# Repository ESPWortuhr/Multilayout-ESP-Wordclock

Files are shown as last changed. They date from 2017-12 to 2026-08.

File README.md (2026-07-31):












[🇬🇧 English](README.en.md) | 🇩🇪 Deutsch

# ESP Wordclock

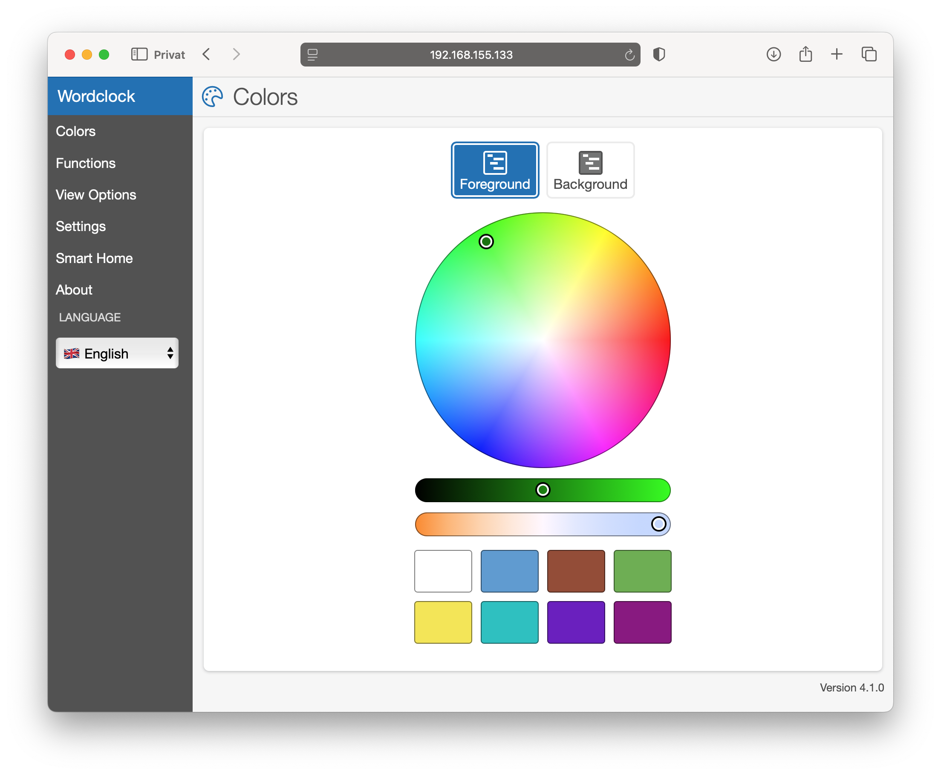
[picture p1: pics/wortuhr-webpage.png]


Dies ist ein Projekt für eine mehrsprachige Wortuhr auf Grundlage eines ESP8266-Mikrocontrollers und einer programmierbaren LED-Leiste (WS2812 oder SK6812). Eine Wortuhr ist ein wunderschönes DIY-Projekt für Anfänger, das Technologie und Design kombiniert, um eine funktionale und ästhetisch ansprechende Uhr zu schaffen. 
Egal, ob Sie ein Anfänger oder ein erfahrener Bastler sind, dieses Projekt ist eine großartige Möglichkeit, Ihre Fähigkeiten unter Beweis zu stellen und etwas wirklich Besonderes zu schaffen.
Die Software hat viele Funktionen:
- Mehrsprachig:
  - 🇬🇧 Englisch (English)
  - 🇩🇪 Deutsch
  - 🇪🇸 Spanisch (Español)
  - 🇮🇹 Italienisch (Italiano)
  - 🇳🇱 Niederländisch (Nederlands)
  - 🇭🇺 Ungarisch (Magyar)
  - 🇷🇴 Rumänisch (Română)
  - 🇨🇭 Schweizerdeutsch (Schwiizerdütsch)
  - 🇷🇺 Russisch (Русский)
  - 🇸🇪 Schwedisch (Svenska)
  - 🇫🇷 Französisch (Français)
  - 🇧🇩 Bengalisch (বাংলা)
- Unterstützung für mehrere Layouts und LED-Abstände
- Farbwechsel der Displayfarbe möglich (RGB oder RGBW)
- Digitale Uhranzeige
- Regenbogenfarbwechsel
- Umgebungslicht (als Sekundenzeiger ausgeführt) 
- Automatische Helligkeitsregelung (optional über LDR) 
- Auswahl an dialektspezifischen Anzeigen
- Home-Assistant-Einbindung mit Autodiscovery



## Inhaltsverzeichnis

- [Betriebsmodi der Uhr](#betriebsmodi-der-uhr)
- [Benötigte Hardware und Software](#benötigte-hardware-und-software)
- [Installation und Flashen der Firmware](#installation-und-flashen-der-firmware)
  - [Windows](#windows-über-grafische-oberfläche)
  - [MacOS](#macos)
  - [Linux](#linux)
  - [Fertige Firmware flashen (ohne Entwicklungsumgebung)](#fertige-firmware-flashen-ohne-entwicklungsumgebung)
  - [Nightly-Builds (aktueller Entwicklungsstand)](#nightly-builds-aktueller-entwicklungsstand)
  - [Nach der Installation: Der Erste Start](#nach-der-installation-der-erste-start)
- [Anschluss der Hardware](#anschluss-der-hardware)
- [Schematischer Aufbau einer Wordclock](#schematischer-aufbau-einer-wordclock)
- [Konfigurationsübersicht](#konfigurationsübersicht)
- [MQTT API Dokumentation](#mqtt-api-dokumentation)
- [Mitwirken](#mitwirken)
- [BSD-3 Lizenz](#bsd-3-lizenz)

## Betriebsmodi der Uhr

<p align="center">
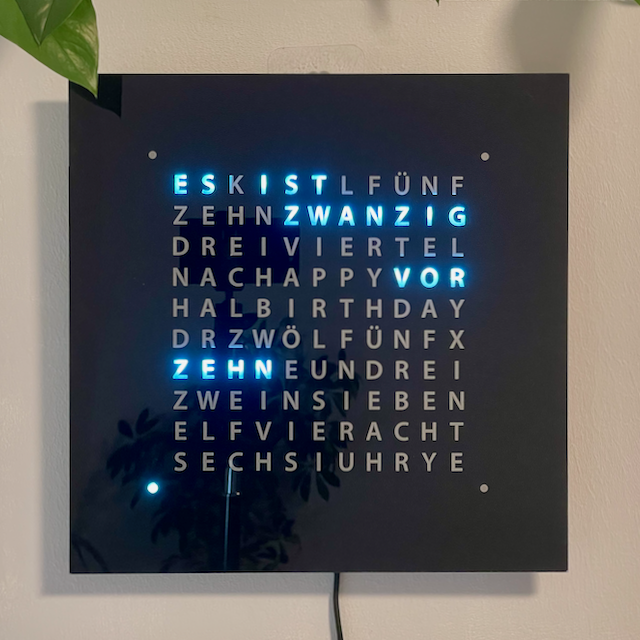
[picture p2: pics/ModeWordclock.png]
Wordclock
 DigitalClock
Colors Rainbow
Symbol Seconds
ScrollingText Animation
FrameSeconds 
</p>

## Benötigte Hardware und Software
* Hardware
    * NodeMCU oder vergleichbares Board mit einem dem ESP8266, ESP8285, ESP32 oder ESP32C3
    * WS2812B RGB-LED-Streifen oder SK6812 RGBW-Streifen
    * Stromversorgung 5V 2A
    * Optional: LDR, 10 KOhm-Widerstand

* Software
    * PlatformIO [Core](https://docs.platformio.org/en/latest/core/installation.html) oder [IDE](https://platformio.org/install/ide?install=vscode)
    * [Node.js](https://www.nodejs.org/)
    * [Git](https://git-scm.com)
 
---

## Installation und Flashen der Firmware

Bei vielen Entwickler-Boards (wie dem NodeMCU oder Wemos D1 Mini) benötigen Sie vorab den passenden USB-zu-Seriell-Treiber (meist **CH340** oder **CP210x**). Installieren Sie diesen, falls Ihr Computer das Board nach dem Einstecken nicht erkennt.

Es gibt zwei Wege zur fertigen Uhr:

* **Selbst kompilieren** (die folgenden Abschnitte Windows/MacOS/Linux). Nur so lässt sich die Uhr über `include/Config.h` an das eigene Layout, die eigene Sprache und die eigene Hardware anpassen. Für die meisten Nachbauten ist das der richtige Weg.
* **[Fertige Firmware flashen](#fertige-firmware-flashen-ohne-entwicklungsumgebung)** ohne Entwicklungsumgebung. Schneller, aber die Standard-Einstellungen sind fest einkompiliert.

### Windows (über grafische Oberfläche)

Der einfachste Weg für Windows-Nutzer führt über die grafische Oberfläche von Visual Studio Code (VS Code).

1. **Voraussetzungen installieren:**
   * Installieren Sie **PlatformIO IDE** (dies installiert automatisch Visual Studio Code), **Node.js** und **Git** manuell über die oben genannten Links.
   * Nach der Installation von VS Code finden Sie ein neues **PlatformIO-Symbol** (einen kleinen Ameisenkopf oder Alien) in der linken Seitenleiste.

2. **Projekt herunterladen (Klonen):**
   * Klicken Sie auf das PlatformIO-Symbol.
   * Gehen Sie im Menü auf `Quick Access` > `Miscellaneous` und wählen Sie `Clone Git Project`.
   * Geben Sie als URL `https://github.com/ESPWortuhr/Multilayout-ESP-Wordclock` ein und wählen Sie einen Speicherort auf Ihrer Festplatte aus.
   * Gehen Sie anschließend auf `Projects`, fügen Sie das soeben heruntergeladene Projekt über `Add Existing` hinzu und klicken Sie auf `Open`.

3. **Software kompilieren und hochladen:**
   * Schließen Sie nun Ihren ESP per USB-Kabel an den Computer an. *(Achtung: Verwenden Sie ein Datenkabel, kein reines Ladekabel!)*
   * In der PlatformIO-Seitenleiste finden Sie den Bereich `Project Tasks`. 
   * Klappen Sie Ihre Board-Umgebung auf und wählen Sie `General` > `Upload`.
   * **Geduld:** Beim ersten Mal dauert dieser Vorgang einige Minuten, da PlatformIO zunächst alle benötigten Bibliotheken im Hintergrund herunterlädt und die Software komplett neu kompiliert. 
   * Nach Abschluss erscheint eine grüne "SUCCESS"-Meldung.

### MacOS

Unter macOS können Sie ebenfalls den Weg über Visual Studio Code gehen (wie bei Windows beschrieben). Für Nutzer, die das Terminal bevorzugen, ist der Weg über den Paketmanager [Homebrew](https://docs.brew.sh/Installation) jedoch deutlich schneller:

1. Öffnen Sie das Terminal.
2. Führen Sie nacheinander die folgenden Befehle aus, um die Tools zu installieren, das Projekt herunterzuladen und auf den ESP zu flashen:

```sh
# PlatformIO und Node.js installieren
brew install platformio
brew install node

# Projektverzeichnis herunterladen
git clone https://github.com/ESPWortuhr/Multilayout-ESP-Wordclock.git
cd Multilayout-ESP-Wordclock

# ESP anschließen und flashen
pio run -t upload
```

### Linux

Auch unter Linux (z. B. Ubuntu, Debian, Raspberry Pi OS) lässt sich die Firmware bequem über das Terminal kompilieren und flashen.

Wichtiger Hinweis für Linux-Nutzer: Stellen Sie sicher, dass Ihr Benutzerkonto die Berechtigung hat, auf serielle Schnittstellen zuzugreifen (meist durch Hinzufügen des Benutzers zur Gruppe dialout via sudo usermod -a -G dialout $USER). Möglicherweise ist danach ein Neustart erforderlich.

```sh
# PlatformIO Installationsskript ausführen
python3 -c "$(curl -fsSL https://raw.githubusercontent.com/platformio/platformio/master/scripts/get-platformio.py)"

# Node.js Paketmanager installieren
sudo apt update
sudo apt install npm git

# Projekt herunterladen und ins Verzeichnis wechseln
git clone https://github.com/ESPWortuhr/Multilayout-ESP-Wordclock.git
cd Multilayout-ESP-Wordclock

# ESP anschließen und flashen
pio run -t upload
```

### Fertige Firmware flashen (ohne Entwicklungsumgebung)

Wer die Uhr nicht selbst kompilieren möchte, kann die fertigen Binärdateien von der [Releases-Seite](https://github.com/ESPWortuhr/Multilayout-ESP-Wordclock/releases) verwenden. Dort liegt pro Chip eine Datei, z. B. `ESP32_V4.4.0.bin`.

> **Wichtig:** Diese Dateien enthalten die Standard-Konfiguration aus `include/Config.h` (deutsches Layout `Ger10x11Alternative`, GRB-LEDs, kein I2C). Wer ein anderes Layout, eine andere Sprache oder eine RTC nutzt, muss selbst kompilieren.

**Weg 1 — Update über das Webinterface (empfohlen, kein Kabel nötig)**

Läuft auf der Uhr bereits eine Firmware, geht das Update über den eingebauten OTA-Updater:

1. Rufen Sie `http://<IP-der-Uhr>:81/update` im Browser auf (beachten Sie den **Port 81**).
2. Wählen Sie die heruntergeladene `.bin`-Datei aus und starten Sie den Upload.
3. Die Uhr startet nach dem Schreiben automatisch neu. Die WLAN- und Farbeinstellungen bleiben erhalten.

Ist in der Konfiguration `WEB_PROTECTED` auf `true` gesetzt, fragt der Updater vorher nach Benutzername und Passwort (`WEB_USER` / `WEB_PASSWORD`).

**Weg 2 — Serielles Flashen mit esptool**

Für ein fabrikneues Board oder eine Uhr, die nicht mehr startet. Voraussetzung ist Python mit `esptool` (`pip install esptool`):

```sh
# ESP8266 (NodeMCU, Wemos D1 Mini)
esptool.py --chip esp8266 --port /dev/ttyUSB0 write_flash 0x0 ESP8266_V4.4.0.bin

# ESP32 und ESP32-C3: die Datei enthält nur die Anwendung
esptool.py --chip esp32 --port /dev/ttyUSB0 write_flash 0x10000 ESP32_V4.4.0.bin
```

Unter Windows heißt der Port `COM3` o. ä., unter macOS `/dev/cu.usbserial-*`.

**Weg 3 — Browser-Flasher (ohne Installation)**

Wer weder PlatformIO noch Python installieren möchte, kann den ESP direkt aus dem Browser flashen. Diese Werkzeuge sprechen den Chip über die Web-Serial-Schnittstelle an:

| Werkzeug | Anmerkung |
| :--- | :--- |
| [esptool-js](https://espressif.github.io/esptool-js/) | Die offizielle Browser-Portierung von esptool durch Espressif. Datei und Offset werden von Hand eingetragen — es gelten dieselben Offsets wie oben. |
| [ESP Web Flasher (esp.huhn.me)](https://esp.huhn.me/) | Schlichtere Oberfläche, ebenfalls mit freier Offset-Angabe. |

Vorgehen: ESP per USB anschließen, im Werkzeug **Connect** wählen, den seriellen Port des Boards bestätigen, die `.bin`-Datei mit dem passenden Offset laden und den Schreibvorgang starten.

> **Voraussetzung:** Web Serial wird nur von Chromium-basierten Browsern unterstützt (Chrome, Edge, Opera) und nur über HTTPS. Firefox und Safari können das nicht. Der Browser braucht außerdem exklusiven Zugriff auf den Port — schließen Sie vorher alle seriellen Monitore.

> **Hinweis für ESP32/ESP32-C3:** Der Offset `0x10000` schreibt ausschließlich die Anwendung. Das setzt voraus, dass Bootloader und Partitionstabelle bereits auf dem Chip liegen — bei einem Board, auf dem schon einmal eine ESP32-Arduino-Firmware lief, ist das der Fall. Ein komplett leerer Chip braucht zusätzlich `bootloader.bin` (Offset `0x1000`, beim ESP32-C3 `0x0`) und `partitions.bin` (Offset `0x8000`). Diese beiden Dateien sind in den Releases nicht enthalten; verwenden Sie in dem Fall den Weg über `pio run -t upload`, der alles Nötige selbst schreibt.

### Nightly-Builds (aktueller Entwicklungsstand)

Für jeden Stand von `main` baut ein GitHub-Actions-Workflow automatisch die Firmware für alle drei Chips — nützlich, um einen Fehlerbericht oder eine gerade gemergte Funktion zu testen, ohne selbst zu kompilieren.

1. Öffnen Sie den Reiter [Actions → Nightly Firmware](https://github.com/ESPWortuhr/Multilayout-ESP-Wordclock/actions/workflows/nightly.yml).
2. Wählen Sie den obersten erfolgreichen Lauf aus.
3. Unter **Artifacts** liegen `firmware-ESP8266`, `firmware-ESP32` und `firmware-ESP32C3` zum Download.

Das Archiv enthält die `.bin` im Schema `<Chip>_V<Version>_<Commit>.bin`, eine `.sha256`-Prüfsumme sowie die `.elf`-Datei, mit der sich ein Absturz-Backtrace auflösen lässt. Geflasht wird genau wie oben beschrieben.

Zu beachten:

* Für den Download ist eine Anmeldung bei GitHub nötig (GitHub-Vorgabe für Artefakte).
* Die Artefakte werden nach **14 Tagen** automatisch gelöscht.
* Es sind **ungetestete Entwicklungsstände**, keine Releases. Wer eine stabile Uhr möchte, nimmt die Releases-Seite.

### Nach der Installation: Der Erste Start

Sobald der Upload auf den ESP erfolgreich war (Meldung `SUCCESS` im Terminal), startet die Uhr neu.

1. Die Wortuhr spannt nun ein eigenes WLAN-Netzwerk (Access Point) auf.
2. Suchen Sie mit Ihrem Smartphone oder Laptop nach einem neuen WLAN (meist "Wortuhr" oder ähnlich) und verbinden Sie sich damit.
3. Es sollte sich automatisch ein Anmeldefenster öffnen (Captive Portal). Falls nicht, öffnen Sie Ihren Browser und rufen Sie die Adresse `http://192.168.4.1` auf.
4. Tragen Sie dort Ihre heimischen WLAN-Zugangsdaten ein. Die Uhr startet neu, verbindet sich mit Ihrem Heimnetzwerk und ist fortan über ihre eigene IP-Adresse im Netzwerk erreichbar.

---

## Anschluss der Hardware
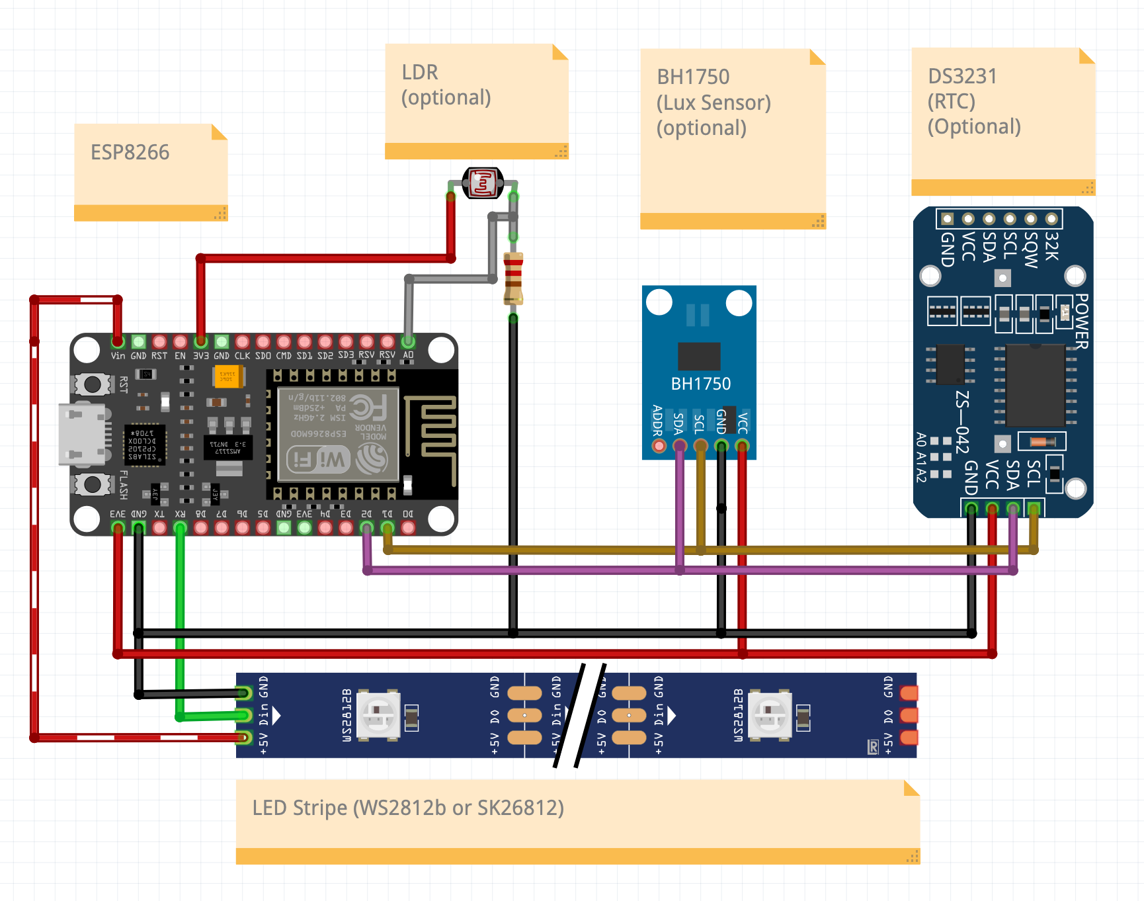
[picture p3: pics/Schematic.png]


## Schematischer Aufbau einer Wordclock

Dieser Leitfaden beschreibt den typischen Schichtaufbau und die elektronische Konfiguration einer DIY-Wortuhr. Die Spezifikationen richten sich nach dem klassischen 11x10 Buchstaben-Raster plus 4 separaten Minuten-LEDs.

### 1. Die mechanischen Schichten (Von vorne nach hinten)

* **Frontplatte:** Die sichtbare Schicht mit den ausgestanzten oder ausgelaserten Buchstaben (oft aus Edelstahl, beschichtetem Acryl oder Holzfurnier).
* **Diffusor-Schicht:** Eine milchige Folie oder ein Bogen Architektenpapier direkt hinter der Frontplatte. Sie streut das Licht der LEDs weich und gleichmäßig aus.
* **Lichtgitter (Baffle):** Ein Rasterkreuz (meist aus Holz, MDF oder 3D-Druck), das jede LED räumlich von den anderen trennt. Es verhindert streng das seitliche Überstrahlen des Lichts auf benachbarte, nicht aktive Buchstaben.
* **Trägerplatte (Rückwand):** Eine stabile Platte, auf der die LED-Streifen passgenau zum Lichtgitter waagerecht aufgeklebt werden.

### 2. Spezifikationen der LED-Matrix (WS2812B / Neopixel)

Um das Raster der Buchstaben matrixgetreu auszufüllen, müssen die Abstände der LEDs (LEDs pro Meter) exakt zur Größe der Uhr passen. Basierend auf den gängigen Gehäusegrößen ergeben sich folgende Anforderungen:

| Gehäusegröße (Front) | Matrix-Größe | Empfohlener LED-Stripe | Besonderheit bei der Verkabelung |
| :--- | :--- | :--- | :--- |
| **30 x 30 cm** | 25 x 25 cm | 60 LEDs/m | Standardmaß. Perfekter Abstand der LEDs für jedes Rasterfeld. |
| **40 x 40 cm** | 35 x 35 cm | 74 LEDs/m | Jede zweite LED einer Reihe bleibt ungenutzt (Software- oder Hardwareseitig übersprungen). |
| **50 x 50 cm** | 50 x 50 cm | 30 LEDs/m | Der natürliche Abstand der LEDs passt direkt zum größeren Raster. |

> **Hinweis zur Verklebung:** Die LED-Streifen werden typischerweise schlangenförmig (Zick-Zack-Verkabelung) auf die Trägerplatte geklebt. Der Daten-Ausgang (DOUT) einer Zeile wird dabei mit dem Daten-Eingang (DIN) der direkt darunterliegenden Zeile auf der gleichen Seite verbunden.

### 3. Elektronik und Komponenten

Den zugehörigen Schaltplan findest du oben unter [Anschluss der Hardware](#anschluss-der-hardware).

* **Mikrocontroller:** Ein ESP8266 (z.B. Wemos D1 Mini) oder ESP32. Dieser steuert die LEDs und synchronisiert die Uhrzeit meist automatisch über das heimische WLAN (NTP-Server).
* **Stromversorgung:** Ein starkes 5V-Netzteil. Wenn viele Buchstaben in der Farbe Weiß leuchten, kann die Matrix mehrere Ampere Strom ziehen. Ein 5V / 3A bis 5A Netzteil wird empfohlen.
* **Echtzeituhr (RTC):** Ein Modul wie das DS3231 (optional, aber empfohlen). Es sorgt durch eine Knopfzelle dafür, dass die Uhrzeit bei Stromausfall oder fehlendem WLAN exakt weiterläuft.
* **Level-Shifter:** Da der ESP mit 3.3V arbeitet, die LEDs aber 5V Datenpegel erwarten, sichert ein Level-Shifter (z.B. 74AHCT125) eine saubere Signalübertragung (oft reicht aber auch ein direkter Anschluss über einen 470 Ohm Widerstand).

### 4. Basis-Schaltplan

* **Netzteil 5V (+):** Verbinden mit dem 5V-Pin des Mikrocontrollers UND dem 5V-Eingang des LED-Streifens.
* **Netzteil GND (-):** Verbinden mit dem GND-Pin des Mikrocontrollers UND dem GND-Eingang des LED-Streifens.
* **Mikrocontroller Data-Pin:** Verbinden mit dem DIN (Data In) des allerersten LED-Streifens in der Matrix.

---

## Konfigurationsübersicht

Die folgenden Einstellungen stammen aus der Datei `include/Config.h`.
Viele dieser Einstellungen können später auch bequem über das Webinterface der Uhr angepasst werden.

### Hardware & Pins (ESP32)
Legt fest, an welchen Pins die Hardware angeschlossen ist (Hinweis: Der ESP8266 wird für diese spezifischen Pins hier aktuell nicht unterstützt).
* **`LED_PIN`**: Pin für den LED-Datenkanal. *(Standard: 3, bei dem ESP8266 ist das der RX Pin)*
* **`SDA_PIN_ESP32` / `SCL_PIN_ESP32`**: Pins für die I2C-Kommunikation (z.B. für RTC oder Lichtsensor). *(Standard: beide `255`, d.h. der I2C-Bus ist deaktiviert)*
  * Diese Pins müssen nicht im Quelltext gesetzt werden: Im Webinterface unter **Einstellungen → Hardware-Pins** lassen sich SDA und SCL direkt eintragen und speichern. Der Wert `255` steht dort ebenfalls für „deaktiviert".
  * Über die Schaltfläche **I2C-Adressen suchen** startet ein Scan des Busses (Adressen 1-126). Das Ergebnisfeld listet alle gefundenen Adressen auf — praktisch, um zu prüfen, ob eine RTC (DS3231 üblicherweise `0x68`) oder ein BH1750-Lichtsensor (`0x23` oder `0x5C`) korrekt angeschlossen ist. Meldet der Scan „Keine I2C-Adressen gefunden", stimmt in der Regel die Verkabelung oder die Pin-Zuordnung nicht.
* **`RTC_Type`**: Verwendetes Echtzeituhr-Modul (RTC), damit die Uhr auch ohne WLAN weiterläuft. *(Standard: `RTC_DS3231`)*

### Sprache & Front-Layout
Definiert, in welcher Sprache und mit welchem Raster die Wortuhr aufgebaut ist. Es ist eine Vielzahl an Sprachen hinterlegt (Deutsch, Englisch, Niederländisch, Spanisch, etc.).
* **`DEFAULT_LAYOUT`**: *(Aktiver Standard: `Ger10x11Alternative`)* * 10 Zeilen, 11 LEDs pro Zeile + 4 Minuten-LEDs.
  * Dies ist das alternative deutsche Layout von Github-User @dbambus mit zusätzlichen Wörtern.

### LED & Darstellung
Spezifiziert den Typ der verwendeten LEDs und die Standard-Farbwerte beim Start.
* **`DEFAULT_LEDTYPE`**: Die Farbreihenfolge des LED-Streifens.
* **`WHITE_LEDTYPE`**: Farbtemperatur, falls RGBW-LEDs genutzt werden. *(Standard: `NeutralWhite`)*
* **`DEFAULT_HUE`**: Standard-Farbton beim Start (0-360). *(Standard: `120` - entspricht Grün)*
* **`DEFAULT_BRIGHTNESS`**: Starthelligkeit in Prozent.
* **`DEFAULT_BUILDTYPE`**: Bauart der Matrix. *(Standard: `Normal` - jede LED auf dem Streifen wird genutzt)*
* **`MINUTE_...`**: Art der Minutenanzeige. *(Standard: `MINUTE_LED4x` - 4 separate LEDs für die Minuten)*

### Helligkeitsregelung
Einstellungen für die automatische Helligkeitsanpassung über externe Sensoren.
* **`AUTOBRIGHT_USE_BH1750`**: Nutzung eines digitalen Lichtsensors.
* **`AUTOBRIGHT_USE_LDR`**: Nutzung eines analogen Fotowiderstands.
  * *Hinweis: Da beide auf `false` stehen, ist die automatische Helligkeitsregelung aktuell deaktiviert.*
* **LDR-Widerstandswerte**: Falls ein LDR genutzt wird, sind hier die Kalibrierungswerte für den Spannungsteiler hinterlegt (`RESBRIGHT 15`, `RESDARK 1000`, `RESDIVIDER 10`).

### WLAN & Captive Portal
Konfiguration der Netzwerkanbindung.
* **`MANUAL_WIFI_SETTINGS`**: Legt fest, ob die WLAN-Daten fest im Code hinterlegt sind.
* **`WIFI_SSID`**: Name deines WLANs.
* **`WIFI_PASSWORD`**: Dein WLAN-Passwort.
* **`CP_PROTECTED` / `CP_SSID` / `CP_PASSWORD`**: Einstellungen für das Captive Portal (das eigene WLAN-Netzwerk der Uhr für die Ersteinrichtung). *(Standard: Unverschlüsselt, SSID: `"Connect_to_Wordclock"`)*

### System & Boot-Verhalten
Einstellungen für den Startvorgang und das Debugging.

### Matrix- & Verdrahtungseinstellungen
Hier wird definiert, wie die LEDs physisch in der Uhr verklebt und verdrahtet wurden (z.B. wo der Streifen beginnt und ob er im Zick-Zack verlegt wurde).
* **`REVERSE_MINUTE_DIR`**: Dreht die Laufrichtung der Minuten-LEDs um.
* **`MIRROR_FRONT_VERTICAL` / `HORIZONTAL`**: Spiegelt die Anzeige vertikal oder horizontal.
* **`EXTRA_LED_PER_ROW`**: Falls zusätzliche (blinde) LEDs pro Zeile verbaut sind.
* **`FLIP_HORIZONTAL_VERTICAL`**: Tauscht X- und Y-Achse (nützlich bei falscher Ausrichtung).
* **`MEANDER_ROWS`**: Gibt an, ob der LED-Streifen schlangenförmig (Zick-Zack) verklebt wurde.
---

## MQTT API Dokumentation

Die Uhr verwendet das **JSON Light Schema** von Home Assistant. Das bedeutet, dass Befehle und Statusmeldungen im JSON-Format über MQTT ausgetauscht werden.

### 1. MQTT Topics (Themen)
Die Uhr verwendet ein Basis-Topic, welches in den Einstellungen der Uhr (Webinterface) definiert wird. In dieser Dokumentation wird es als `<TOPIC>` bezeichnet (z.B. `ESPWordclock`).

| Funktion | Topic | Beschreibung |
| :--- | :--- | :--- |
| **Befehle senden** | `<TOPIC>/cmd` | An dieses Topic sendest du JSON-Befehle, um die Uhr zu steuern. |
| **Status empfangen** | `<TOPIC>/status` | Auf diesem Topic veröffentlicht die Uhr nach jeder Änderung ihren aktuellen Status. |
| **Verfügbarkeit** | `<TOPIC>/availability` | Zeigt an, ob die Uhr online ist (`online` oder `offline` via Last Will). |

---

### 2. Befehle Senden (Command Payload)
Befehle werden als JSON-String an das Topic `<TOPIC>/cmd` gesendet. Du kannst mehrere Parameter in einer einzigen Nachricht kombinieren.

#### Unterstützte JSON-Parameter:

* **`state`** (String)
  Schaltet die LEDs der Uhr ein oder aus.
  * Werte: `"ON"` oder `"OFF"` *(Muss zwingend großgeschrieben werden!)*
* **`brightness`** (Integer)
  Steuert die Helligkeit der LEDs.
  * Werte: `0` bis `255`
* **`color`** (Object)
  Setzt die Vordergrundfarbe der Uhr im HSB-Farbraum (Hue, Saturation).
  * `h` (Hue/Farbton): `0` bis `360` (Grad)
  * `s` (Saturation/Sättigung): `0` bis `100` (%)
* **`effect`** (String)
  Wechselt den Anzeigemodus / das Programm der Uhr.
  * Werte: 
    * `"Wordclock"` (Normale Wortuhr)
    * `"Seconds"` (Sekundenanzeige)
    * `"Digitalclock"` (Digitale Uhrzeit)
    * `"Scrollingtext"` (Lauftext)
    * `"Rainbowcycle"` (Regenbogen-Zyklus)
    * `"Rainbow"` (Regenbogen statisch)
    * `"Color"` (Einfarbig)
    * `"Symbol"` (Symbolanzeige, z.B. Herz)
* **`scrolling_text`** (String)
  Legt den Text fest, der im Effekt `"Scrollingtext"` angezeigt wird.
  * Werte: Beliebiger Text (max. Länge abhängig von den C++ Speichereinstellungen).

---

### 3. Beispiele für MQTT-Befehle

**Uhr einschalten, auf 100% Helligkeit setzen und Farbe auf Rot ändern:**
```json
{
  "state": "ON",
  "brightness": 255,
  "color": {
    "h": 0,
    "s": 100
  }
}
```

**Modus auf "Lauftext" ändern und Text vorgeben:**
```json
{
  "effect": "Scrollingtext",
  "scrolling_text": "Hallo Welt!"
}
```

**Uhr ausschalten:**
```json
{
  "state": "OFF"
}
```

---

### 4. Status Empfangen (Status Payload)

Sobald die Uhr einen Befehl verarbeitet hat (oder sich intern etwas ändert), sendet sie ihren Zustand an <TOPIC>/status. Dies ist besonders wichtig, damit Smart Home Systeme (wie Home Assistant) den aktuellen Zustand kennen.

**Beispielhafter Status-Rückgabewert:**

```json
{
  "state": "ON",
  "color": {
    "h": 120,
    "s": 100
  },
  "brightness": 128,
  "color_mode": "hs",
  "effect": "Wordclock"
}
```

(Hinweis: color_mode: "hs" wird von Home Assistant benötigt, um zu wissen, dass die Farbe im Hue/Saturation-Format vorliegt).

---

### 5. Home Assistant Auto-Discovery
Diese Uhr unterstützt MQTT Auto-Discovery für Home Assistant.
Wenn die Uhr startet oder der Button "MQTT Discovery" im Webinterface gedrückt wird, sendet sie automatisch ihre komplette Konfiguration an das Topic:

`homeassistant/light/<TOPIC>/light/config`

Dadurch taucht die Wortuhr in Home Assistant vollautomatisch als Licht-Entität auf. Du hast dort sofort Zugriff auf:

- Ein/Aus Schalter
- Helligkeits-Schieberegler
- Farbwähler (Farbrad)
- Ein Dropdown-Menü für alle Effekte (Wordclock, Rainbow, etc.)

## Mitwirken

Pull Requests sind willkommen — sei es eine neue Sprache, ein neues Frontlayout oder eine Fehlerkorrektur.

**Code-Formatierung.** Das Projekt nutzt `clang-format` mit der Konfiguration in [.clang-format](.clang-format). Ein Pull Request, dessen Formatierung davon abweicht, wird von der CI abgelehnt. Formatieren Sie deshalb vor dem Commit:

```sh
clang-format -i $(git ls-files '*.h' '*.hpp' '*.cpp' '*.ino')
```

Die CI prüft mit **clang-format 11**. Neuere Versionen formatieren an einzelnen Stellen abweichend — im Zweifel entscheidet das Ergebnis der CI.

**Automatische Prüfungen.** Jeder Push und jeder Pull Request durchläuft drei Workflows:

| Workflow | Prüft |
| :--- | :--- |
| [PlatformIO CI](.github/workflows/platformio.yml) | Kompiliert für ESP8266, ESP32 und ESP32-C3 |
| [Run clang-format Linter](.github/workflows/clang-format.yml) | Einhaltung der Code-Formatierung |
| [Nightly Firmware](.github/workflows/nightly.yml) | Täglicher Build inklusive Firmware-Artefakten |

Alle drei müssen grün sein, bevor ein PR gemergt werden kann.

**Vor dem Öffnen eines Pull Requests** empfiehlt sich ein lokaler Build aller drei Umgebungen — das ist derselbe Befehl, den die CI ausführt:

```sh
pio run
```

**Neue Frontlayouts** brauchen zwei Schritte:

1. Die Layout-Datei als eigene `.hpp` nach `include/WordClockTypes/` legen. Der Build bindet alle Dateien dieses Verzeichnisses automatisch über `include/ClockType.gen.h` ein; dort ist nichts von Hand zu ergänzen. Am Ende der Datei steht die Instanz des Layouts, z. B. `De10x11Alternative_t _de10x11Alternative;`.
2. Das Layout in der Liste `CLOCK_TYPES_LIST` in [include/WordClockState.h](include/WordClockState.h) registrieren. Ohne diesen Eintrag ist das Layout weder auswählbar noch im Webinterface sichtbar:

```c
X(Ger10x11Alternative, 12, _de10x11Alternative, "de-10-11-alt")
```

Die vier Parameter sind der Name der Aufzählung, eine **eindeutige ID**, der Name der Instanz aus Schritt 1 und der i18n-Schlüssel für die Anzeige. Die ID dient als Querverweis für HTML und JavaScript und darf nicht doppelt vergeben werden — verwenden Sie die nächste freie Nummer am Ende der Liste. Die Liste ist nach Sprachkürzeln gruppiert; ordnen Sie den neuen Eintrag passend ein.

Die Auswahlliste im Webinterface wird aus dieser Liste **automatisch erzeugt** (Grunt-Schritt `replace:frontlayout`); in `webpage/index.html` ist nichts zu ergänzen. Was noch von Hand dazukommt, ist der Anzeigename unter dem i18n-Schlüssel in den Sprachdateien `webpage/language/*.js` (dort im Abschnitt `view.front`).

Optional kann das Layout zusätzlich als auskommentierte `DEFAULT_LAYOUT`-Zeile in `include/Config.h` aufgeführt werden, damit es dort zur Auswahl steht.

## BSD-3 Lizenz

Diese Software ist unter der BSD-Lizenz lizenziert und darf frei verwendet werden. Es ist erlaubt, sie zu kopieren, zu verändern und zu verbreiten.
Die einzige Bedingung ist, dass der Copyright-Hinweis des Originalprogramms nicht entfernt werden darf.

Der vollständige Lizenztext steht in der Datei [LICENSE](LICENSE).

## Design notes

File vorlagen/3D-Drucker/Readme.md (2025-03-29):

# TBD: Druckdateien werde ich auf Printables hochladen
[Printables](https://www.printables.com/@Sebas)

# Druckdatei erstellen
Die Beschreibungen beziehen sich alle auf den PrusaSlicer, können aber mit Sicherheit auch auf andere Slicer übertragen werden.

## Einfache Version
Um den Diffusor direkt ins Gehäuse zu drucken kann entweder die Datei "Wortuhr_8x8_CaseWithoutLayerChange.3mf" direkt gesliced werden und in Höhe des Diffusors ein Filamentwechsel eingefügt. So hat man jedoch einen weißen Streifen aus am Gehäuse.

## Schwierigere Version
In der Datei "Wortuhr_8x8_Case_DE15min_Prusa.3mf" ist in Höhe des Diffusors ein Schlitz im Gehäuse, sodass der Diffusor in der Luft hängt. Dies kann so gesliced werden und im Anschluss mit dem Python-Script "ChangeLayerHeightAfterFilamentChange.py" nach unten gesetzt werden. Somit wird der Diffusor in das Gehäuse eingedruckt (siehe "Wortuhr_8x8_Case_DE15min_Prusa_0.2mm_PLA,PLA_MK3_2h24m.gcode"). Es soll wohl auch möglich sein, direkt im Slicer durch das definieren eines zweiten Extruders den Diffusor in das Gehäuse zu drucken, allerdings habe ich das bisher noch nicht getestet.

## Druckeinstellungen
- Höhenmodifizierer im Bereich des Diffusors zu 0.1mm (Zwei Schichten sind notwendig, damit homogen)
- Druckeinstellungen -> Erweitert -> Infill/Perimeter Überlappung: 35% (Sonst bleiben Lücken zwischen Buchstaben und Infill)
- PLA mit möglichst niedriger Temperatur (205-210°C) um Fäden zwischen den Buchstaben zu verhindern.

# FreeCAD
Zum erstellen habe ich die Version FreeCAD 1.0 RC1 (https://github.com/FreeCAD/FreeCAD/releases/tag/1.0rc1) verwendet. Das Modell ist über die Variablen in VarSet parametrierbar. Es wird empfohlen, nur manuell zu aktualisieren (Klick Rechte Maustaste auf Wortuhr_8x8_Vorlage -> Neuberechnungen überspringen). Die Vorlage ist für eine maximale Größe von 16x16 LEDs ausgelegt.

Folgende Parameter sind anpassbar:
- Anzahl der LEDs in X und Y Richtung
- Abstand der LEDs in X und Y Richtung
- Höhe und Breite der Platine der LED Matrix
- Buchstaben auf der Wortuhr
- Schriftart & -größe
- Wandstärke
- Spielraum

Falls ihr Fragen oder eigene Idee zu Layout's oder Änderungen habt könnt ihr euch gerne bei mir melden.

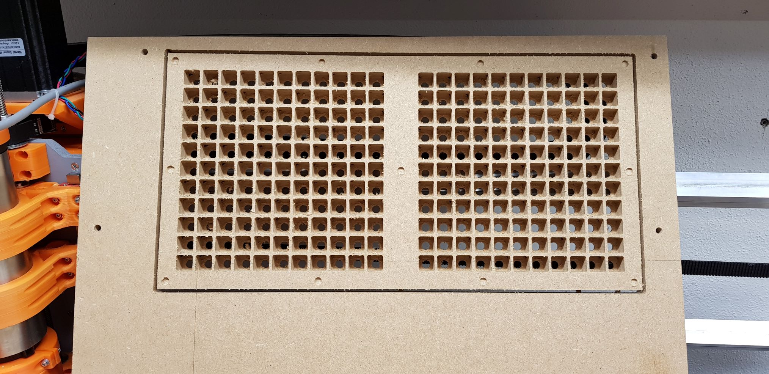
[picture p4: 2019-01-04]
pics/CNC_Machined/uhr_242-front.jpg

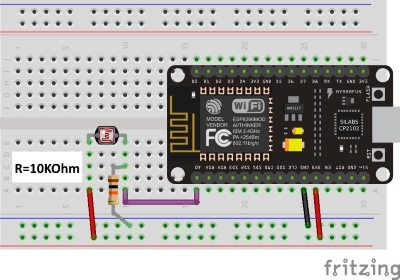
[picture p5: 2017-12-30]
pics/LDR.jpg

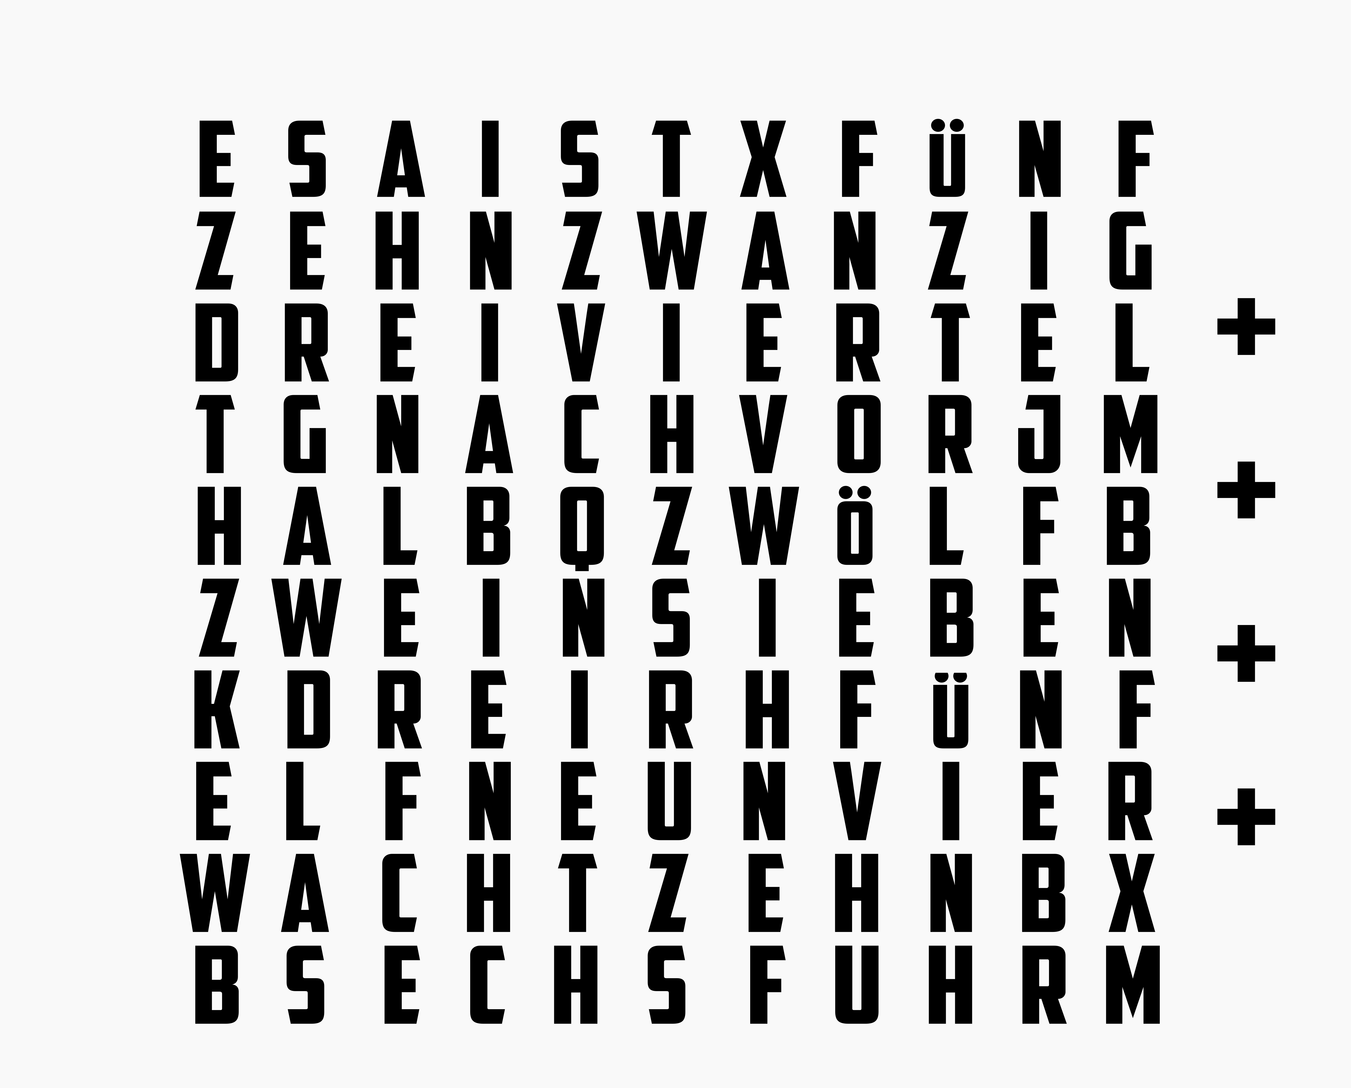
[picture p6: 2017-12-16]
pics/40x50_Text.png

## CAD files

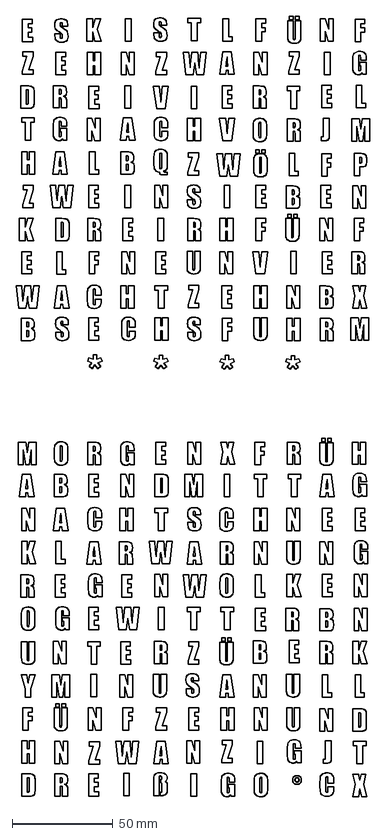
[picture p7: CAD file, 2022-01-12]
vorlagen/Router/Uhr242/Uhr242_Front.dxf
175.7 x 387.6 mm

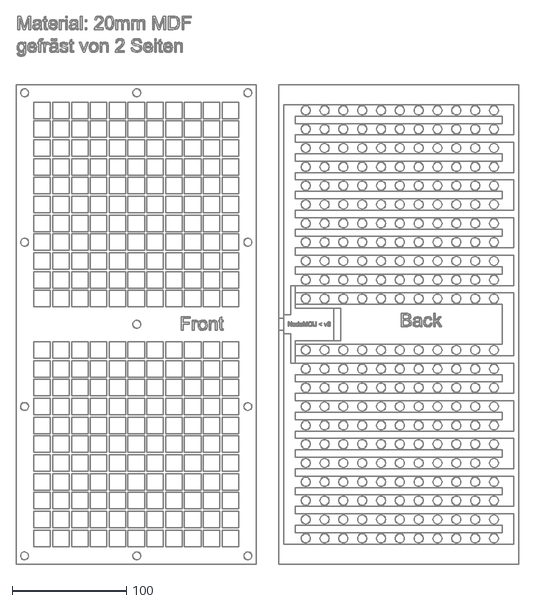
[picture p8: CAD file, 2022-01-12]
vorlagen/Router/Uhr242/Uhr242_Matrix.dxf
440.0 x 480.2

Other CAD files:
vorlagen/Laser/Uhr114/WordClockUhr114LaserFinalV2.dxf
vorlagen/Laser/Uhr242/WordClockUhr242LaserFinalV2.dxf
3D_Model/Wordclock.f3d

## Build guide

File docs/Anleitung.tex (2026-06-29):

\documentclass[12pt,a4paper, german,oneside, headinclude, headsepline,plainheadsepline,BCOR20mm, DIV18,parskip=half, openright, numbers=noenddot, captions=tableheading,version=first,listof=totoc,version=first]{scrbook}

\hfuzz=20pt
\vfuzz=20pt

%--------------- Packages ----------------
\usepackage[ngerman]{babel}
\usepackage[utf8]{inputenc}
\usepackage[T1]{fontenc}
\usepackage{lmodern}
\usepackage[centertags]{amsmath} 
\usepackage{tabularx}
\usepackage{graphicx} 
\usepackage{float} 
\usepackage{setspace} 
\usepackage{scrlayer-scrpage}
\usepackage{scrhack}
\usepackage{makeidx}
\usepackage[usenames,dvipsnames,svgnames,table]{xcolor}
\usepackage[absolute]{textpos}
\usepackage{subfigure}
\usepackage{amssymb}
\usepackage{listings}
\usepackage{trfsigns}
\usepackage{siunitx}
\usepackage[abs]{overpic}
\usepackage[colorlinks = false,pdfpagelabels = true,pdfstartview = FitH,bookmarksopen = true,bookmarksnumbered = true,linkcolor = black,plainpages = false,hypertexnames = false,citecolor = black] {hyperref}
\usepackage{pgfplots}
\usepackage[framed,numbered,autolinebreaks,useliterate]{mcode}
\usepackage{xcolor}
\usepackage[
    left = \flqq{},% 
    right = \frqq{},% 
    leftsub = \flq{},% 
    rightsub = \frq{} %
]{dirtytalk}
\lstset{breaklines=true}

\pagestyle{scrheadings}
\renewcommand{\headfont}{\normalfont\sffamily} 
\renewcommand{\pnumfont}{\normalfont\sffamily} 
\ohead[\pagemark]{\pagemark} 
\ifoot[]{}
\ofoot[]{}
\setlength{\headheight}{1.5\baselineskip}
\onehalfspacing

%----------------------- Beginn des Dokuments -----------------------
\begin{document}
\pagenumbering{Roman}
\thispagestyle{empty}
\setcounter{page}{-1}



\vspace{25mm}

{\centering

\LARGE\textbf{{Anleitung}}\\
\vspace{1em}
\large{Für die Multilayout-ESP-Wordclock} \\

\par}

\newpage
\thispagestyle{empty}

\cleardoublepage

\cleardoublestandardpage

\begin{spacing}{1.15}		
\pdfbookmark[1]{Inhaltsverzeichnis}{toc}		
\tableofcontents 		

\end{spacing}

\cleardoublestandardpage

\mainmatter							

\chapter{Einleitung}

Diese Anleitung soll helfen, eine mehrsprachige Wortuhr zu bauen, die auf einem ESP8266-, ESP8285-, ESP32- oder ESP32-C3-Mikrocontroller und einer programmierbaren LED-Leiste (WS2812 oder SK6812) basiert. Dieses Projekt wurde über mehrere Jahre von einer Vielzahl von Mitwirkenden auf GitHub entwickelt und frei zur Verfügung gestellt.\\
Eine Wortuhr (auch als Wordclock bekannt) ist ein schönes DIY-Projekt für Anfänger, das Technologie und Design kombiniert, um eine funktionale und ästhetisch ansprechende Uhr zu schaffen. Egal, ob Sie Anfänger oder erfahrener Bastler sind, dieses Projekt ist eine großartige Gelegenheit, Ihre Fähigkeiten unter Beweis zu stellen und etwas wirklich Besonderes zu schaffen. Die Gestaltungsmöglichkeiten liegen vor allem im Rahmen und in der Wahl der Oberfläche der Uhr.

\section{Hauptfunktionen}

Die bereitgestellte Software zum Betreiben der Wortuhr hat mehrere Funktionen:

\begin{itemize}
    \item Mehrsprachig (Deutsch, Englisch, Niederländisch, Italienisch, Spanisch, Ungarisch, Französisch, Rumänisch, Schweizer Deutsch, Russisch und Schwedisch)
    \item Unterstützung für mehrere Matrizengrößen und LED-Abstände
    \item Farbwechsel der Anzeigefarbe möglich (RGB oder RGBW)
    \item Digitale Uhranzeige
    \item Laufschrift, kurzer statischer Text und Symbol-Anzeige
    \item Regenbogenfarbwechsel
    \item Einstellbare Übergangsanimationen zwischen Anzeigewechseln
    \item Geburtstags- und Silvester-Animationen
    \item Umgebungslicht (als Sekundenzeiger ausgeführt oder Ambientlight)
    \item Minuten- und Sekundenanzeige im Rahmen oder in Worten
    \item Automatische Helligkeitsregelung (optional über Sensor)
    \item Offlinebetrieb (optional über entsprechende RTC)
    \item Zeitserver, Zeitzone und manuelle Uhrzeit im Web-Frontend einstellbar
    \item Konfigurierbare Hardware- und I2C-Pins
    \item Konfigurierbares Startverhalten
    \item Auswahl an dialektspezifischen Anzeigen
    \item MQTT- und Home-Assistant-Einbindung mit Autodiscovery
    \item Wetterdaten über OpenWeatherMap bei passenden Frontplatten
    \item Optionaler Passwortschutz für das Web-Frontend
\end{itemize}

\section{Uhrenvarianten}

Die Firmware unterstützt verschiedene Frontplatten und Matrixgrößen. Die passende Variante wird später im Web-Frontend unter \say{Anzeigeoptionen} im Bereich \say{Front} ausgewählt. Wichtig ist, dass die eingestellte Matrix zur tatsächlich gebauten Buchstabenmaske und zur Anordnung der LEDs passt.

\begin{itemize}
    \item Klassische deutsche Layouts mit 10 \(\times\) 11, 11 \(\times\) 11, 13 \(\times\) 13, 16 \(\times\) 8 oder 16 \(\times\) 18 LEDs
    \item Kompakte Varianten mit 8 \(\times\) 8 LEDs, teilweise für Viertelstunden-Anzeige
    \item Internationale Layouts, unter anderem Englisch, Niederländisch, Spanisch, Italienisch, Ungarisch, Französisch, Rumänisch, Schweizer Deutsch, Russisch, Schwedisch und Bengalisch
    \item Dialekt- und Sondervarianten wie Bayerisch, Schwäbisch, Nero, mrrioes oder Wetter-Layout
    \item Bauarten mit einer LED pro Buchstabe, jeder zweiten LED pro Buchstabe oder zwei, drei bzw. vier LEDs pro Buchstabe
\end{itemize}

Zusätzlich können im Web-Frontend die Minutenzählrichtung, horizontale oder vertikale Spiegelung, gedrehte Layouts, zusätzliche LEDs pro Reihe, mäanderförmig verlegte LED-Streifen und die Bauart der LED-Matrix eingestellt werden. Diese Optionen sind hilfreich, wenn die LED-Streifen anders herum eingebaut wurden, die Frontplatte gespiegelt gefertigt ist oder mehrere physische LEDs einen Buchstaben ausleuchten. Änderungen an Matrixgröße und Bauart werden im EEPROM gespeichert und erst nach einem Neustart der Uhr vollständig übernommen.

    \begin{figure} [H]
        \centering
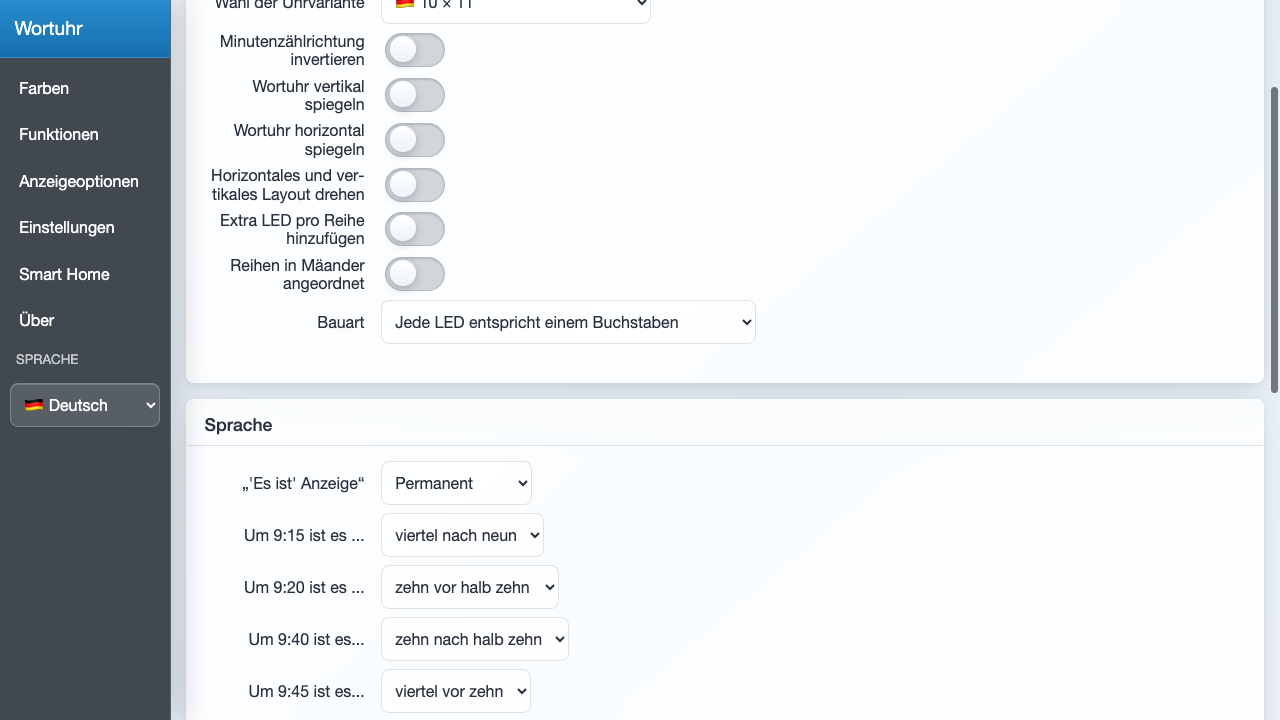
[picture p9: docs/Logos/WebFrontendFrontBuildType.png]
        
        \caption{Front- und Bauart-Konfiguration im Web-Frontend}
        \label{abb.WebFrontendFrontBuildType}
    \end{figure}

\section{Voraussetzungen}

Die folgende Hardware/Software wird für dieses Projekt benötigt:

\subsubsection{Hardware}

\begin{itemize}
    \item NodeMCU oder vergleichbares Board mit ESP8266-, ESP8285-, ESP32- oder ESP32-C3-Chip
    \item WS2812B RGB-LED-Streifen oder SK6812 RGBW-Streifen
    \item Stromversorgung 5 V / 2 A
    \item Optional: LDR, 10 KOhm-Widerstand
    \item Optional: BH1750 (digitaler Helligkeitssensor, anstatt LDR)
    \item Optional: DS3231 (Echtzeituhr, für den Offline-Betrieb)
\end{itemize}

\subsubsection{Software}

\begin{itemize}
    \item PlatformIO Core oder IDE (bspw. Visual Studio Code)
    \item Node.js
    \item Git
\end{itemize}

\chapter{Installation der Wortuhr Software}

\section{Erstmaliges Aufspielen einer Binary}
Für das erstmalige Aufspielen stehen auf der GitHub-Seite rechts unter \say{Releases} fertige Versionen der Software zur Verfügung. Programme zum Aufspielen der Binary findet man z.B. unter \say{https://github.com/nodemcu/nodemcu-flasher}.

\section{Windows}

\begin{enumerate}
    \item Installieren Sie die aktuellsten Versionen von PlatformIO, Node.js und Git manuell
    \item Dadurch wird Visual Studio Code installiert, mit einem PlatformIO-Symbol (Ameisenkopf/Alien) in der Seitenleiste
    \item Gehen Sie zu \say{Quick Access / Miscellaneous} und geben Sie den Befehl \say{Clone Git Project} ein, und geben Sie \href{https://github.com/ESPWortuhr/Multilayout-ESP-Wordclock}{https://github.com/ESPWortuhr/Multilayout-ESP-Wordclock} als URL ein
    \item Gehen Sie dann zu \say{Projekte}, fügen Sie das neue Projekt mit \say{Vorhandenes hinzufügen} zur Liste hinzu und klicken Sie auf \say{Öffnen}.
    \item In der PlatformIO-Seitenleiste erscheint nun \say{Project Tasks}. Wählen Sie den Befehl \say{General / Upload} (dauert ein paar Minuten, die Software wird zuerst erstellt).
    \item Schließen Sie den ESP8266 über USB an. Wenn die Wortuhr-Software erstellt ist, wird sie auf dem ESP installiert.
\end{enumerate}

\section{macOS}

Der einfachste Weg ist die Installation mit \say{Homebrew}:

\begin{lstlisting}
    brew install platformio
    brew install node
    git clone https://github.com/ESPWortuhr/Wortuhr
    cd Wortuhr
    pio run -t upload
\end{lstlisting}

Dabei ist der ESP über USB angeschlossen. Die Wortuhr-Software wird dabei mittels PlatformIO erstellt und auf den ESP übertragen.

\section{Linux}

\begin{lstlisting}
    python3 -c "$(curl -fsSL https://raw.githubusercontent.com/ platformio/platformio/master/scripts/get-platformio.py)"
    sudo apt install npm
    git clone https://github.com/ESPWortuhr/Wortuhr
    cd Wortuhr
    pio run -t upload
\end{lstlisting}

Dabei ist der ESP über USB angeschlossen. Die Wortuhr-Software wird dabei mittels PlatformIO erstellt und auf den ESP übertragen.

\section{Erster Start und WLAN-Einrichtung}
Nach dem erfolgreichen Aufspielen startet die Uhr neu. Falls noch keine WLAN-Daten hinterlegt sind, erstellt sie ein eigenes WLAN für die Einrichtung. Die Standard-SSID ist \say{Connect\_to\_Wordclock}, sofern sie in der Firmware-Konfiguration nicht geändert wurde.

\begin{enumerate}
    \item Mit Smartphone oder Laptop mit dem WLAN der Uhr verbinden.
    \item Falls sich kein Anmeldefenster öffnet, im Browser \say{http://192.168.4.1} aufrufen.
    \item Das heimische WLAN auswählen und die Zugangsdaten eintragen.
    \item Nach dem Speichern startet die Uhr neu und verbindet sich mit dem Heimnetzwerk.
    \item Die danach verwendete IP-Adresse wird in der Grundeinstellung beim Start als Laufschrift ausgegeben.
\end{enumerate}

\section{Update der Firmware über das Web-Frontend}
Mit der Software ist es möglich, die Firmware \textbf{OTA} (over the air), über den in der Uhr eingebauten Webserver zu aktualisieren. Dies ist in den meisten Fällen einfacher als das direkte Flashen.
Ausschlaggebend für diese Vorgehensweise ist, dass die Uhr über WLAN erreichbar ist. Die Update-Schnittstelle ist dann über die Adresse
http://<IP-Adresse der Uhr>:81/update erreichbar (Beispiel: http://192.168.4.1:81/update). Die Adresse der Uhr wird in der Grundeinstellung beim Start als Laufschrift ausgegeben.

\section{Optionaler Zugriffsschutz für das Web-Frontend}
Das Web-Frontend kann bereits in der Firmware-Konfiguration mit HTTP-Basic-Auth geschützt werden. Dazu werden in \texttt{include/Config.h} im Abschnitt \say{Web interface settings} die Werte \texttt{WEB\_PROTECTED}, \texttt{WEB\_USER} und \texttt{WEB\_PASSWORD} gesetzt. Ist \texttt{WEB\_PROTECTED} auf \texttt{true} gestellt, fragt die Uhr beim Zugriff auf Web-Frontend, Websocket-Verbindung und OTA-Update-Seite nach Benutzername und Passwort.

Wichtig: Das Standardpasswort \texttt{CHANGE\_THIS\_PASSWORD} darf für eine produktiv verwendete Uhr nicht unverändert bleiben. Nach einer Änderung in \texttt{Config.h} muss die Firmware neu gebaut und auf die Uhr übertragen werden.

\chapter{Hardware}

Für den Aufbau der Wortuhr wird folgende elektronische Hardware benötigt:

\begin{itemize}
    \item NodeMCU oder vergleichbares Board mit ESP8266-, ESP8285-, ESP32- oder ESP32-C3-Chip
    \item RGB-LED-Streifen WS2812B oder RGBW-Streifen SK6812
    \item Stromversorgung 5 V / 2 A
    \item Optional: Hardware-Taster für Power, Modus und Geschwindigkeit/Farbe
    \item Optional: LDR, 10 KOhm Widerstand
    \item Optional: BH1750 (digitaler Helligkeitssensor, ersetzt LDR)
    \item Optional: DS3231 (Echtzeituhr, für Offline-Betrieb)
\end{itemize}

Neben der Elektronik werden für den mechanischen Aufbau weitere Materialien benötigt. Da es verschiedene Arten gibt, eine Uhr zu bauen, sind hier nur die grundlegenden Dinge aufgeführt:

\begin{itemize}
    \item Bilderrahmen (Holz oder Metall mit mindestens 14 mm Rahmenhöhe)
    \item Diffusorfolie
    \item Buchstabenmaske
    \item Abstandsgitter (Holz oder Kunststoffschaum)
\end{itemize}

\section{Pegelanpassung}

Der ESP arbeitet intern mit einer Betriebsspannung von 3,3 V. Die WS2812(B)-Streifen arbeiten dagegen mit 5 V. Dies erfordert eine Pegelanpassung, damit die digitalen Signale fehlerfrei zu den Streifen übertragen werden können. Ohne Anpassung kann es auch funktionieren, muss es aber nicht.
Es gilt: "Der minimale High-Pegel des Ausgangs muss höher sein als der minimale High-Pegel des Eingangs"
Was heißt das im Klartext?
Laut Datenblatt des LED-Streifens sind folgende Pegel notwendig, um ein \say{sauberes} HIGH- und LOW-Signal zu bekommen.
Um ein HIGH-Signal am Eingang des WS2812B-Streifens zu erzeugen, muss laut Datenblatt (Bild 1) mindestens ein Pegel von 4,3 V erzeugt werden. Da der ESP aber maximal 3,3 V erzeugen kann, wird hier kein sicheres HIGH-Signal erzeugt.

Nun kommt der Trick mit der Diode:
Die erste LED wird nun mit einer Diode in der Plus-Leitung betrieben. Die Durchlassspannung der Diode beträgt 0,7 V. Das heißt, dass die erste LED mit 4,3 V betrieben wird. Das ist laut Datenblatt auch zulässig. Bei 4,3 V beträgt der benötigte HIGH-Pegel nun noch 3,6 V. Da die Hersteller noch Toleranzen mit einberechnen, funktioniert das ganze Konstrukt wieder. Nun gibt die erste LED den Pegel mit 4,3 V an die nächste LED weiter. Diese wird wieder mit 5 V betrieben und der HIGH-Pegel liegt mit 4,3 V wieder innerhalb der Datenblatt-Toleranz. Die zweite LED verstärkt sozusagen das Signal wieder auf die vollen 5 V.
Das heißt, die erste LED wird sozusagen als Pegelanpassung missbraucht.

\section{Anschlussbeispiel}
Der Datenpin des LED-Streifens ist in der Grundeinstellung an dem Port \say{Rx} (GPIO3) angeschlossen. Damit bleibt die bisherige ESP8266-Ansteuerung mit festem RX-Pin kompatibel. Wird der LED-Pin in der Hardware-Konfiguration geändert, verwendet die Firmware auf dem ESP8266 automatisch die Bit-Bang-Ansteuerung für den gewählten GPIO. Wie auf dem Schaltbild muss eine Diode in die +5-V-Leitung der ersten LED. Die +5-V-Leitung zwischen der ersten und zweiten LED muss durchtrennt werden (aber nur diese, nicht Daten und GND!).
Am zweiten Streifen wird dann zusätzlich vom Netzteil +5 V eingespeist. Die LEDs vom ersten Streifen werden dann sozusagen \say{rückwärts} mit den nötigen +5 V versorgt.

    \begin{figure} [h]
		\centering
		 
		\caption{Anschlussbeispiel}
		\label{abb.Schematic}
	\end{figure}

\section{Konfigurierbare Hardware-Pins}

Die Firmware kann den Datenpin des LED-Streifens und drei optionale Hardware-Taster konfigurieren. Die Konfiguration wird im Web-Frontend unter \say{Einstellungen} im Bereich \say{Hardware-Pins} vorgenommen. Es muss immer die GPIO-Nummer des Controllers eingetragen werden, nicht die auf dem Board aufgedruckte Bezeichnung. Bei NodeMCU-Boards ist zum Beispiel \say{D4} nicht die richtige Eingabe, sondern die zugehörige GPIO-Nummer.

    \begin{figure} [H]
        \centering
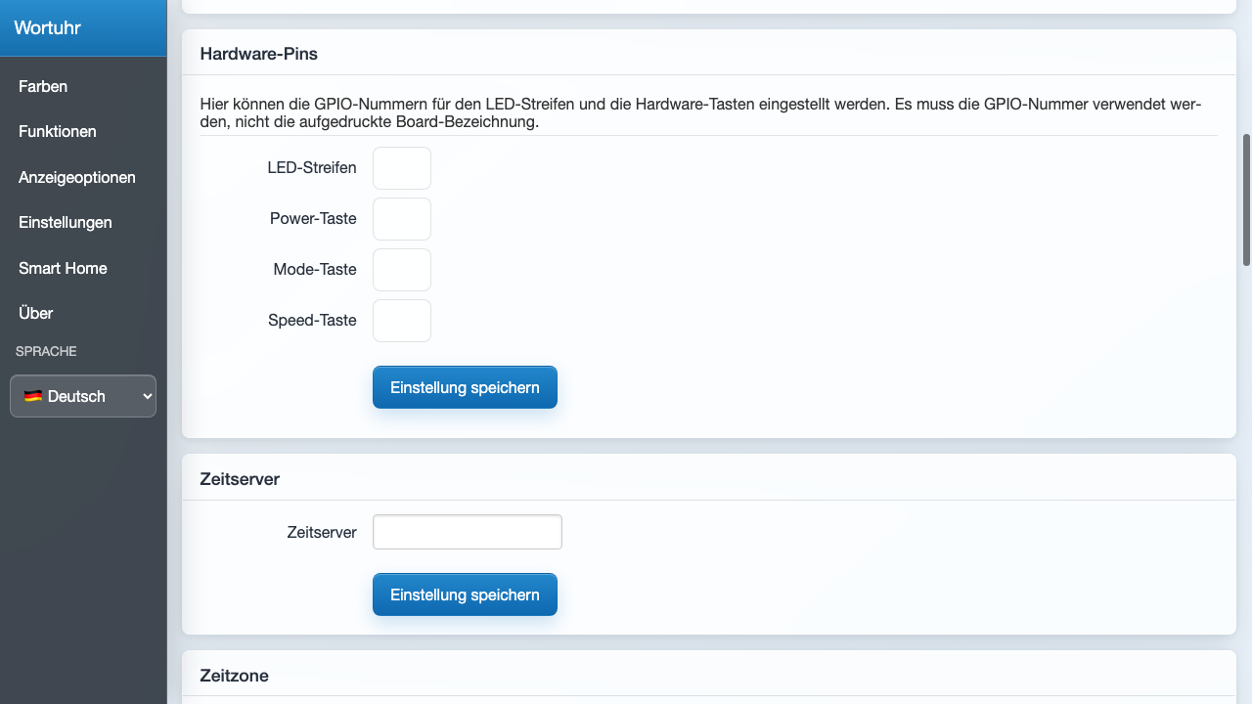
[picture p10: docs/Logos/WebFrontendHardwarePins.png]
        
        \caption{Hardware-Pin-Konfiguration im Web-Frontend}
        \label{abb.HardwarePinsWeb}
    \end{figure}

\subsection{Standard-Pins}

\begin{table}[H]
    \centering
    \begin{tabularx}{\linewidth}{|l|l|X|}
        \hline
        Funktion & Standard-GPIO & Hinweis \\
        \hline
        LED-Streifen & GPIO3 & Auf ESP8266 entspricht dies RX und nutzt die alte, feste Standard-Ansteuerung. \\
        \hline
        Power-Taste & GPIO2 & Taster gegen GND; wird per internem Pull-up gelesen. \\
        \hline
        Mode-Taste & GPIO13 & Kurzer Druck: nächster Modus; langer Druck: nächste Transition. \\
        \hline
        Speed-Taste & GPIO14 & Kurzer Druck: Helligkeit; langer Druck: Farbton. \\
        \hline
    \end{tabularx}
    \caption{Standardbelegung der konfigurierbaren Hardware-Pins}
    \label{tab.HardwarePinsDefaults}
\end{table}

Die Taster werden mit \texttt{INPUT\_PULLUP} betrieben. Ein Taster verbindet den GPIO daher beim Drücken mit GND. Für alle vier Hardware-Pins gilt: Jeder GPIO darf nur einmal verwendet werden. Die Firmware prüft doppelte Pins und ungültige Werte und stellt bei ungültigen EEPROM-Werten wieder die Standard-Pins her.

\subsection{I2C-Pins und I2C-Scan}

Im selben Bereich können auch die I2C-Pins für optionale I2C-Geräte wie BH1750-Helligkeitssensor oder DS3231-Echtzeituhr eingestellt werden. Für den ESP8266 sind die Standardwerte SDA = D2 und SCL = D1, beim klassischen ESP32 SDA = GPIO21 und SCL = GPIO22. Beim ESP32-C3 sind die I2C-Pins standardmäßig deaktiviert und müssen passend zum verwendeten Board gesetzt werden.

Der Wert \texttt{255} deaktiviert einen I2C-Pin. SDA und SCL müssen immer gemeinsam gesetzt oder gemeinsam deaktiviert werden. Nach dem Speichern kann mit \say{I2C-Adressen suchen} geprüft werden, ob angeschlossene Geräte auf dem gewählten Bus antworten. Gefundene Adressen werden im Web-Frontend angezeigt; bei ungültigen oder deaktivierten Pins erscheint eine entsprechende Meldung.

\subsection{Geeignete Pins je Controller}

Die folgenden Empfehlungen beziehen sich auf die in diesem Projekt verwendeten Controller-Varianten. Zusätzlich muss geprüft werden, welche Pins auf dem konkreten Entwicklungsboard wirklich herausgeführt sind. Einige Hersteller drucken Board-Bezeichnungen wie \say{D1} oder \say{RX} auf; in der Web-Konfiguration wird trotzdem die GPIO-Nummer eingetragen.

\subsubsection{ESP8266 / ESP8285}

Für ESP8266-Boards akzeptiert die Firmware GPIO0 bis GPIO16. Empfehlenswert sind:

\begin{itemize}
    \item LED-Streifen: Standard GPIO3/RX. Alternativ GPIO4, GPIO5, GPIO12, GPIO13 oder GPIO14.
    \item Hardware-Taster: GPIO4, GPIO5, GPIO12, GPIO13 oder GPIO14. GPIO2 ist als Standard für die Power-Taste nutzbar, darf beim Booten aber nicht auf LOW gezogen werden.
    \item Nicht verwenden: GPIO6 bis GPIO11, da diese üblicherweise mit dem Flash-Speicher verbunden sind.
    \item Mit Vorsicht verwenden: GPIO0, GPIO2 und GPIO15 sind Boot-Strapping-Pins. Falsche Pegel beim Einschalten können den Bootvorgang verhindern. GPIO16 hat keinen normalen internen Pull-up und ist deshalb für die Taster-Schaltung nicht empfohlen.
\end{itemize}

\subsubsection{ESP32}

Für ESP32-Boards akzeptiert die Firmware GPIO0 bis GPIO39. Empfehlenswert sind:

\begin{itemize}
    \item LED-Streifen: GPIO4, GPIO13 bis GPIO19, GPIO21 bis GPIO23, GPIO25 bis GPIO27, GPIO32 oder GPIO33. GPIO3 bleibt als Standard aus Kompatibilitätsgründen möglich, liegt aber oft auf RX0.
    \item Hardware-Taster: GPIO4, GPIO13 bis GPIO19, GPIO21 bis GPIO23, GPIO25 bis GPIO27, GPIO32 oder GPIO33.
    \item Nicht verwenden: GPIO6 bis GPIO11, da diese üblicherweise mit dem SPI-Flash verbunden sind.
    \item Nicht für den LED-Streifen verwenden: GPIO34 bis GPIO39, da diese nur Eingang sind. Für Taster sind sie nur mit externem Pull-up geeignet, da sie keine internen Pull-up-/Pull-down-Widerstände besitzen.
    \item Mit Vorsicht verwenden: GPIO0, GPIO2, GPIO5, GPIO12 und GPIO15 sind Boot-Strapping-Pins. GPIO1 und GPIO3 sind die Standard-UART-Pins und können die serielle Ausgabe stören.
\end{itemize}

\subsubsection{ESP32-C3}

Der ESP32-C3 besitzt GPIO0 bis GPIO21. Auch wenn die Weboberfläche höhere Zahlen nicht verhindert, sollten nur tatsächlich vorhandene Pins des Boards verwendet werden. Empfehlenswert sind:

\begin{itemize}
    \item LED-Streifen und Hardware-Taster: GPIO0, GPIO1, GPIO3, GPIO4, GPIO5, GPIO6, GPIO7, GPIO10, GPIO11, GPIO20 oder GPIO21, sofern diese Pins auf dem verwendeten Board herausgeführt sind.
    \item Nicht verwenden: GPIO12 bis GPIO17, da diese üblicherweise mit SPI-Flash oder PSRAM verbunden sind.
    \item Mit Vorsicht verwenden: GPIO2, GPIO8 und GPIO9 sind Boot-Strapping-Pins. GPIO18 und GPIO19 sind standardmäßig für USB-JTAG vorgesehen.
    \item Hinweis zu den Standard-Pins: GPIO13 und GPIO14 sind auf ESP32-C3-Boards häufig nicht als freie GPIOs nutzbar. Für ESP32-C3 sollten die Button-Pins daher vor dem Verdrahten auf geeignete freie GPIOs geändert werden.
\end{itemize}

Die Einschränkungen orientieren sich an den GPIO-Hinweisen der Espressif-Dokumentation für ESP32 und ESP32-C3 sowie den bekannten ESP8266-Boot- und Flash-Pins.

\subsection{Bedienung der Hardware-Taster}

\begin{itemize}
    \item Power-Taste: schaltet die LEDs aus und bei erneutem Druck wieder mit den vorherigen Farben ein.
    \item Mode-Taste: kurzer Druck wechselt zum nächsten Anzeigemodus, langer Druck zur nächsten Transition.
    \item Speed-Taste: kurzer Druck erhöht die Helligkeit, langer Druck wechselt den Farbton.
\end{itemize}

\chapter{Funktionen der Uhrensoftware auf dem ESP}

\section{Anzeigemodi im Web-Frontend}
Die wichtigsten Funktionen werden im Web-Frontend unter \say{Funktionen} ausgewählt. Neben der klassischen Wortuhr stehen Sekundenanzeige, Digitaluhr, Laufschrift, Regenbogen, Farbwechsel, feste Farbe und Symbol-Anzeige zur Verfügung. Je nach Modus werden darunter nur die jeweils passenden Einstellungen eingeblendet, zum Beispiel Geschwindigkeit, Helligkeit, Lauftext oder Symbolauswahl.

    \begin{figure} [H]
        \centering
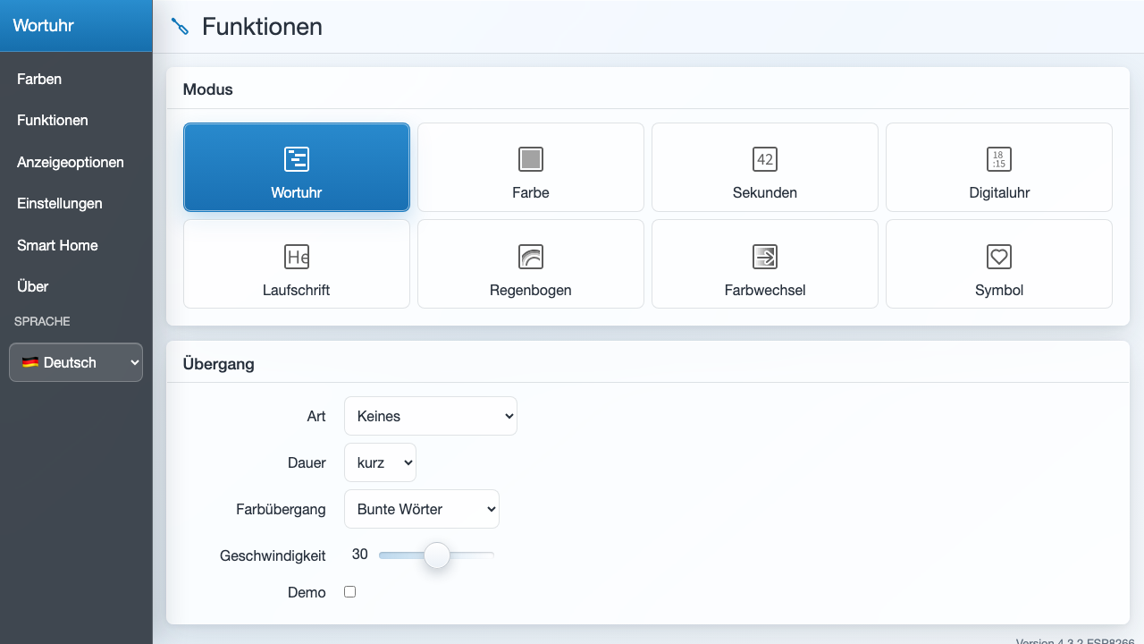
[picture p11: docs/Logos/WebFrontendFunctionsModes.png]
        
        \caption{Auswahl der Anzeigemodi im Web-Frontend}
        \label{abb.WebFrontendFunctionsModes}
    \end{figure}

Im Modus \say{Laufschrift} wird der unter \say{Lauftext} gespeicherte Text über die Matrix bewegt. Sehr kurze Texte werden automatisch anders behandelt: Nach dem Entfernen führender und nachfolgender Leerzeichen werden ein oder zwei Zeichen statisch zentriert angezeigt, sofern sie auf die gewählte Matrix passen. Ein- oder zweistellige Zahlen werden dabei wie eine kleine Digitalanzeige dargestellt.

Im Modus \say{Symbol} kann eines der vordefinierten Bitmap-Symbole angezeigt werden. Zur Auswahl stehen Herz, Smiley, Note, Schneeflocke, Brief, Glocke, Stop und Standby. Die Farbe wird über die normalen Vordergrund-Farbeinstellungen bestimmt; die Geschwindigkeit beeinflusst die Wiederholung bzw. Aktualisierung des Modus.

    \begin{figure} [H]
        \centering
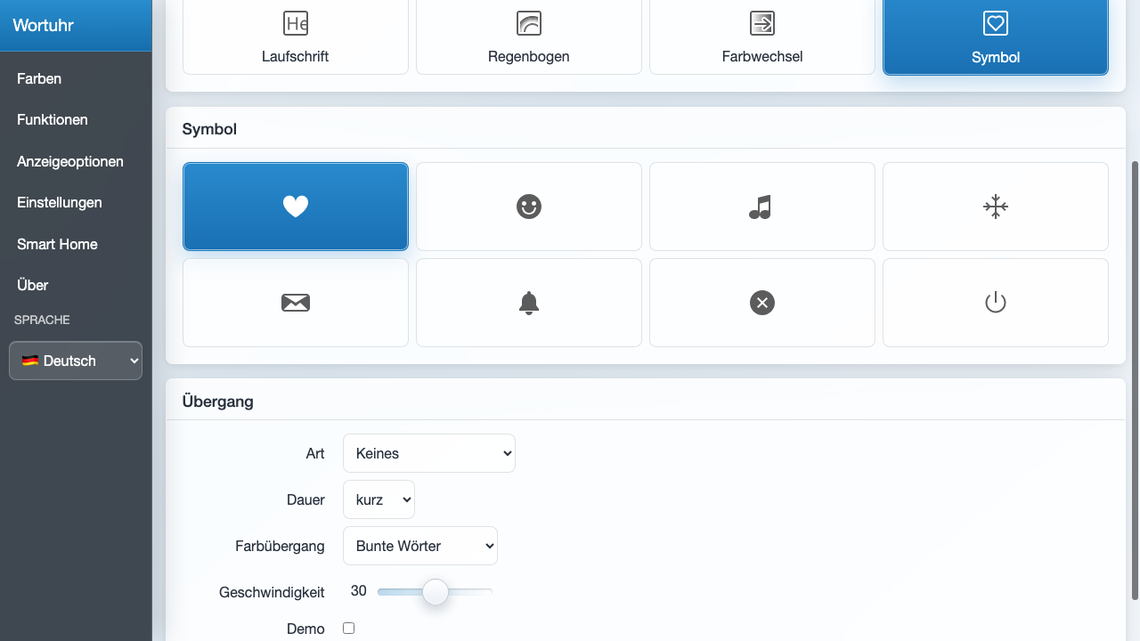
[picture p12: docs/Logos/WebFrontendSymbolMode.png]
        
        \caption{Symbol-Auswahl im Web-Frontend}
        \label{abb.WebFrontendSymbolMode}
    \end{figure}

\section{Übergänge und Animationen}

Unter \say{Funktionen} kann im Bereich \say{Übergang} eingestellt werden, wie Änderungen der Wortmatrix animiert werden. Zur Auswahl stehen unter anderem Hoch- und Runterscrollen, Schieben nach links oder rechts, Überblenden, Laser, Matrix-Regen, Bälle, Feuerwerk, Schlange, Bunt und Zufällig. Zusätzlich lassen sich Dauer, Geschwindigkeit und die Einfärbung der Animation einstellen. Die Option \say{Demo} löst die gewählte Transition zu Testzwecken aus.

Einige Animationen werden auch für besondere Ereignisse verwendet. An Silvester zeigt die Uhr einen Countdown und anschließend eine Feuerwerksanimation. Im Bereich \say{Geburtstage} können bis zu fünf Termine im Format \texttt{MM-DD} hinterlegt werden. An diesen Tagen erscheint alle fünf Minuten eine Feuerwerksanimation. Bei kompatiblen Frontplatten werden währenddessen die Wörter \say{Happy Birthday} statt der Uhrzeit angezeigt.

\section{Anzeigeoptionen}

Unter \say{Anzeigeoptionen} werden nicht nur Frontplatte und Bauart gesetzt, sondern auch die Darstellung von Sprache, Minuten, Sekunden und Startverhalten angepasst.

\subsection{Sprach- und Minutenlogik}

Im Bereich \say{Sprache} kann eingestellt werden, wann der Text \say{Es ist} angezeigt wird. Außerdem lassen sich sprachliche Varianten für Viertelstunden und Zwanzig-Minuten-Angaben wählen, zum Beispiel \say{viertel nach neun} oder \say{viertel zehn}. Diese Optionen hängen von der gewählten Sprache und Frontplatte ab.

Die Minutenanzeige kann deaktiviert oder über zusätzliche LEDs dargestellt werden. Je nach Bauart stehen vier Minuten-LEDs, sieben Minuten-LEDs, Ecken oder die Anzeige in Worten zur Verfügung. Die Einstellung muss zur mechanischen Front und zur Verdrahtung passen.

\subsection{Sekunden im Rahmen}

Die Sekundenanzeige im Rahmen kann ausgeschaltet oder als Punkt, Sektor oder umlaufender Sektor dargestellt werden. Diese Funktion setzt voraus, dass die gebaute Uhr entsprechende Rahmen-LEDs besitzt. Bei Frontplatten ohne Rahmen-LEDs sollte die Anzeige deaktiviert bleiben.

\subsection{Boot-Optionen}

Im Bereich \say{Boot} wird festgelegt, was beim Neustart sichtbar sein soll. Die LEDs können kurz aufblitzen, einmal durchlaufen, während der Netzwerksuche ein WLAN-Symbol anzeigen und nach erfolgreicher Verbindung die IP-Adresse ausgeben. Die IP-Anzeige ist besonders hilfreich, wenn die Uhr per Browser konfiguriert oder ein OTA-Update gestartet werden soll.

\section{Verbinden der Uhr mit dem eigenen WLAN}
Nach dem erfolgreichen Verbinden kann die Uhr nach Eingabe der angezeigten IP-Adresse in einem Browser konfiguriert werden. Dabei kann die Uhr auch mit dem eigenen WLAN Netz verbunden werden.

Die WLAN-Konfiguration befindet sich im Web-Frontend unter \say{Einstellungen} im Bereich \say{Wi-Fi / WLAN}. Dort kann die Neukonfiguration gestartet oder das WLAN bis zum Neustart deaktiviert werden.

    \begin{figure} [H]
        \centering
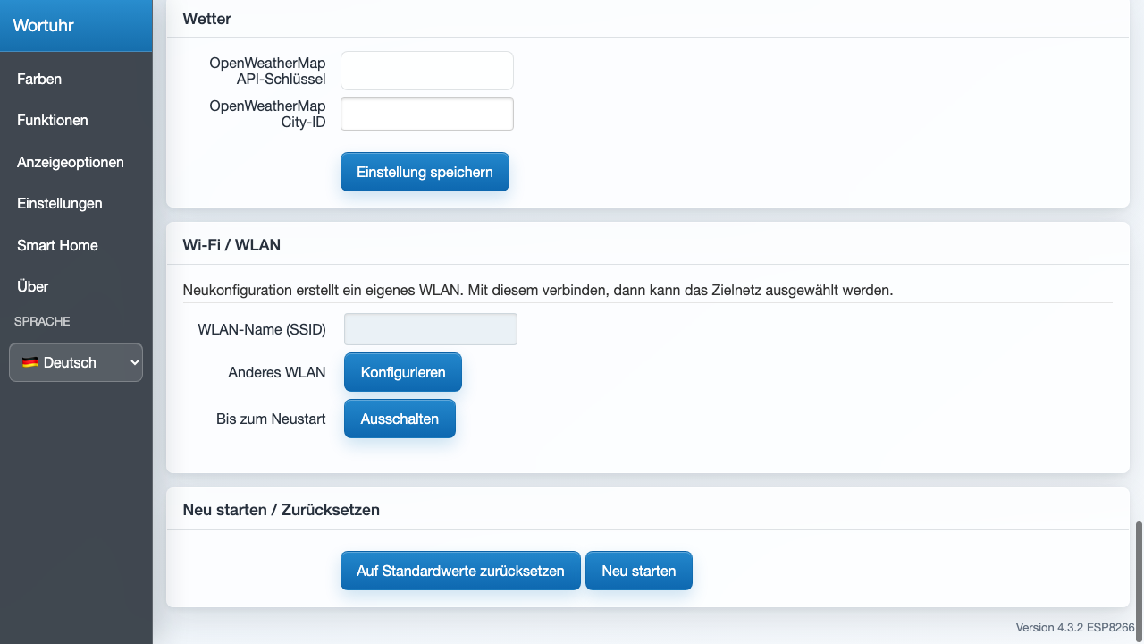
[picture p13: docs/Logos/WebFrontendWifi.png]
        
        \caption{WLAN-Konfiguration im Web-Frontend}
        \label{abb.WebFrontendWifi}
    \end{figure}
 
\section{Zeitserver (NTP Server)}
Falls die Uhr an das eigene WLAN mit Internet angebunden wird, kann ein Zeitserver hinterlegt werden. Dieser sorgt dafür, dass die Uhrzeit zyklisch sekundengenau gestellt wird. 

Der Zeitserver wird im Web-Frontend unter \say{Einstellungen} im Bereich \say{Zeitserver} eingetragen und gespeichert.

    \begin{figure} [H]
        \centering
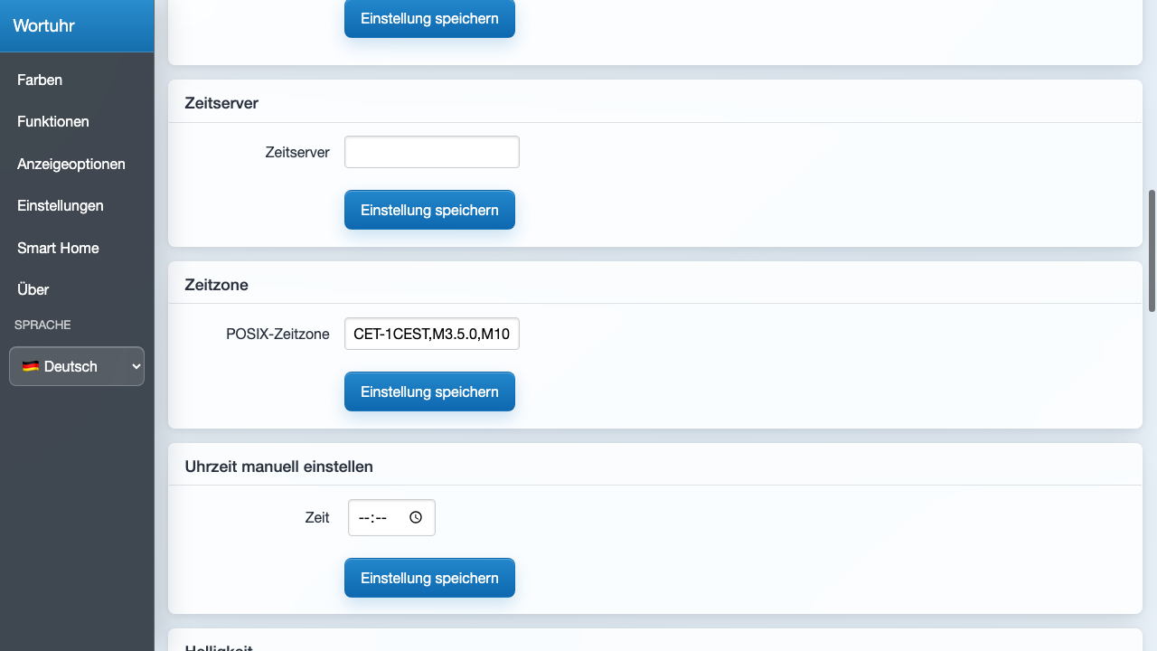
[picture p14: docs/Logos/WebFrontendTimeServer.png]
        
        \caption{Zeitserver-Konfiguration im Web-Frontend}
        \label{abb.WebFrontendTimeServer}
    \end{figure}

\section{Zeitzone und manuelle Uhrzeit}
Die Zeitzone wird im Web-Frontend unter \say{Einstellungen} im Bereich \say{Zeitzone} als POSIX-Zeitzone gespeichert. Für Deutschland ist die Voreinstellung \path{CET-1CEST,M3.5.0,M10.5.0/3}. Die POSIX-Schreibweise enthält neben der Abweichung zur UTC auch die Regeln für Sommer- und Winterzeit; dadurch kann die Uhr die lokale Zeit korrekt aus der vom Zeitserver gelieferten UTC-Zeit berechnen.

Im Bereich \say{Uhrzeit manuell einstellen} kann die Uhrzeit direkt gesetzt werden. Das ist vor allem für Tests, für den Betrieb ohne WLAN oder als schnelle Korrektur hilfreich. Wenn die Uhr später wieder einen Zeitserver erreicht, wird die Zeit erneut per NTP synchronisiert.

    \begin{figure} [H]
        \centering
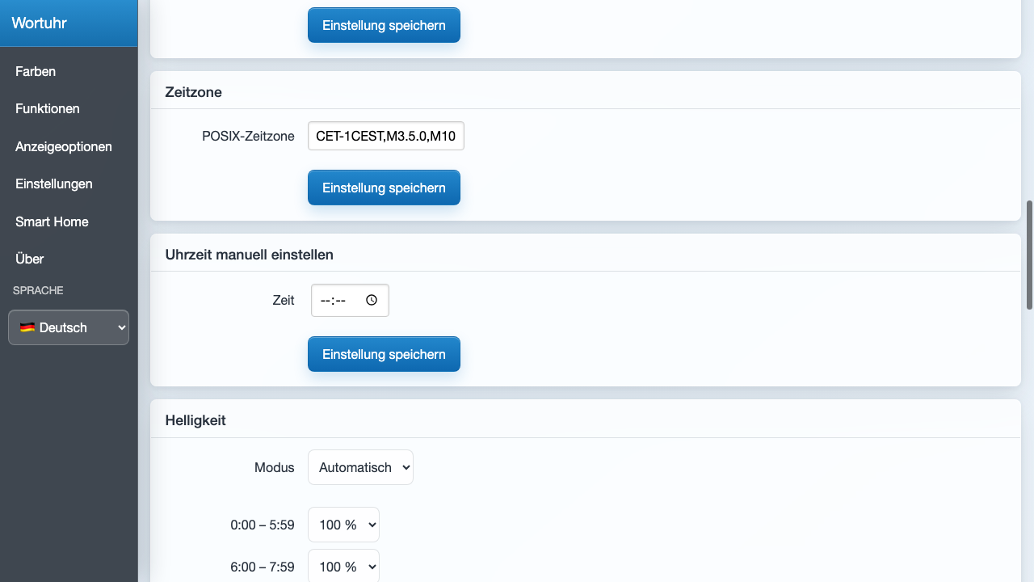
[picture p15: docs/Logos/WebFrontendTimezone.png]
        
        \caption{Zeitzone und manuelle Uhrzeit im Web-Frontend}
        \label{abb.WebFrontendTimezone}
    \end{figure}
 
\section{Automatische Helligkeitsregelung}
Falls der optionale LDR an der Uhr angeschlossen wurde, ist es möglich, die Helligkeit automatisch, abhängig der Umgebungshelligkeit, regeln zu lassen. Dazu muss folgende Einstellung aktiviert werden. Durch das Feld Kalibrierung kann man die Grundhelligkeit an seine eigenen Wünsche anpassen.

Die automatische Helligkeit wird im Web-Frontend unter \say{Einstellungen} im Bereich \say{Helligkeit} konfiguriert. Im Modus \say{Automatisch} können minimale und maximale LED-Helligkeit sowie das Referenz-Umgebungslicht angepasst werden.

    \begin{figure} [H]
        \centering
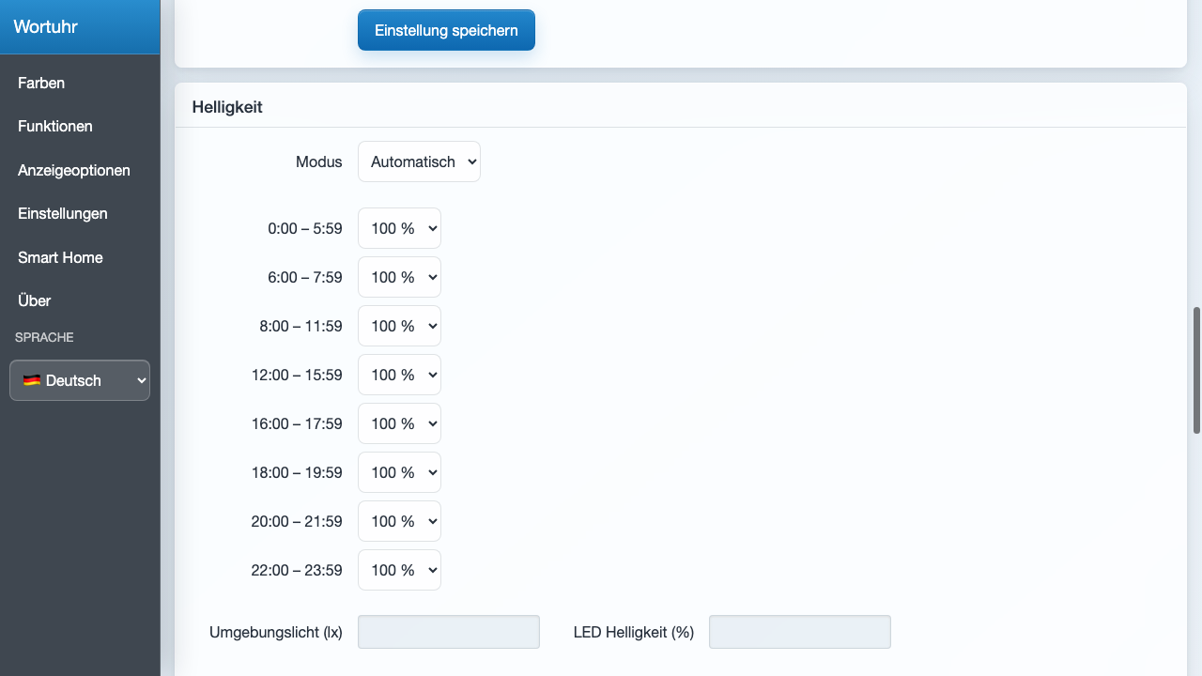
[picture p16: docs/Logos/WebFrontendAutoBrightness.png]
        
        \caption{Automatische Helligkeitsregelung im Web-Frontend}
        \label{abb.WebFrontendAutoBrightness}
    \end{figure}

Im manuellen Modus kann die Helligkeit zeitabhängig gesetzt werden. Dafür stehen Zeitbereiche von 0:00 bis 23:59 Uhr zur Verfügung, die jeweils auf 100 \%, 80 \%, 60 \%, 40 \%, 20 \% oder \say{Aus} gestellt werden können. So kann die Uhr nachts automatisch dunkler leuchten, auch wenn kein Helligkeitssensor angeschlossen ist.

\section{LED-Typ, Weißpunkt und Wetterdaten}

Unter \say{Einstellungen} kann der verwendete LED-Typ ausgewählt werden. Für WS2812-Streifen stehen verschiedene Farbreihenfolgen wie BRG, GRB, RGB, RBG und BGR zur Verfügung. Bei SK6812-RGBW-Streifen kann zusätzlich der Typ der weißen LED als Warmweiß, Neutralweiß oder Kaltweiß gesetzt werden. Wenn Farben falsch angezeigt werden, ist dies meistens die erste Einstellung, die geprüft werden sollte.

Für Wetter-Frontplatten kann im Bereich \say{Wetter} ein OpenWeatherMap-API-Schlüssel und eine City-ID hinterlegt werden. Die Uhr ruft damit Wettervorhersagen ab und kann diese auf Layouts anzeigen, die Wetterwörter bzw. Wetterbereiche unterstützen. Ohne passende Frontplatte oder ohne gültigen API-Schlüssel bleibt diese Funktion wirkungslos.

\section{Smart Home und MQTT}

Die Uhr kann über MQTT in ein Smart-Home-System eingebunden werden. Im Web-Frontend befindet sich dafür der Bereich \say{Smart Home}. Dort werden MQTT aktiviert sowie Serveradresse, Port, Benutzername, Passwort, Client-ID und Topic gespeichert. Die MQTT-Zugangsdaten können alternativ bereits in \texttt{include/Config.h} vorkonfiguriert werden.

Über MQTT lassen sich grundlegende Funktionen wie Ein-/Ausschalten, Helligkeit, Farbe, Effekt bzw. Modus, Lauftext, automatische Helligkeit und Übergangseinstellungen steuern. Statuswerte wie aktuelle Farbe, Helligkeit, Modus, WLAN-Signal, Uptime und Sensordaten werden ebenfalls veröffentlicht.

Mit \say{Sende HA Discovery} sendet die Uhr die Home-Assistant-Autodiscovery-Konfiguration. Danach erscheint sie in Home Assistant als MQTT-Gerät mit Licht-Entität und zusätzlichen Steuerelementen, ohne dass die YAML-Konfiguration manuell angelegt werden muss. Voraussetzung ist ein erreichbarer MQTT-Broker und aktivierte MQTT-Discovery in Home Assistant.

\section{Neustart und Zurücksetzen}

Im Bereich \say{Neu starten / Zurücksetzen} kann die Uhr direkt aus dem Web-Frontend neu gestartet werden. Außerdem können die gespeicherten Einstellungen auf Standardwerte zurückgesetzt werden. Nach Änderungen an Matrixgröße, Bauart, Hardware-Pins oder anderen systemnahen Einstellungen zeigt das Web-Frontend einen Hinweis an, wenn ein Neustart empfohlen wird.

\section{Fehlersuche}

\begin{table}[H]
    \centering
    \small
    \begin{tabularx}{\linewidth}{|l|X|}
        \hline
        Problem & Mögliche Ursache und Lösung \\
        \hline
        Kein WLAN der Uhr sichtbar & Die Uhr neu starten und einige Sekunden warten. Falls bereits WLAN-Daten gespeichert sind, startet kein Captive Portal. Dann die aktuelle IP-Adresse verwenden oder die WLAN-Konfiguration im Web-Frontend erneut starten. \\
        \hline
        Web-Frontend ist nicht erreichbar & Prüfen, ob sich Gerät und Uhr im gleichen Netzwerk befinden. Die beim Start angezeigte IP-Adresse verwenden und bei OTA-Updates den Port \texttt{:81} ergänzen. \\
        \hline
        Web-Frontend fragt nach Benutzername und Passwort & In \texttt{include/Config.h} ist \texttt{WEB\_PROTECTED} aktiviert. Mit den dort gesetzten Werten \texttt{WEB\_USER} und \texttt{WEB\_PASSWORD} anmelden. \\
        \hline
        LEDs bleiben dunkel & 5-V-Versorgung, GND-Verbindung, Datenrichtung des LED-Streifens und den eingestellten LED-Pin prüfen. Bei optionalen Tastern darf kein Boot-Strapping-Pin dauerhaft auf LOW gezogen werden. \\
        \hline
        Farben werden falsch angezeigt & Im Web-Frontend unter \say{Einstellungen} den LED-Typ bzw. die Farbreihenfolge anpassen. Unterschiedliche LED-Streifen verwenden verschiedene RGB-/RGBW-Reihenfolgen. \\
        \hline
        Uhrzeit stimmt nicht & WLAN-Verbindung, Zeitserver, Zeitzone und Internetzugang prüfen. Für den Offline-Betrieb muss eine RTC wie DS3231 korrekt angeschlossen sein oder die Uhrzeit manuell gesetzt werden. \\
        \hline
    \end{tabularx}
    \caption{Häufige Fehler und erste Prüfschritte}
    \label{tab.Troubleshooting}
\end{table}

\end{document}

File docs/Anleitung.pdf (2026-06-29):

!!

M | E | S | P | I | W | O | R | D | F
B | A | C | L | O | C | K | D | A | N
E | A | N | A | L | L | E | E | F | T
M | A | N | U | A | L | N | J | L | K

## Anleitung

### Für die Multilayout-ESP-Wordclock

# Inhaltsverzeichnis

1 Einleitung | 1
2 Installation der Wortuhr Software | 5
3 Hardware | 8
4 Funktionen der Uhrensoftware auf dem ESP | 15

Inhaltsverzeichnis | I

I

# 1 Einleitung

Diese Anleitung soll helfen, eine mehrsprachige Wortuhr zu bauen, die auf einem ESP8266-, ESP8285-, ESP32- oder ESP32-C3-Mikrocontroller und einer programmierbaren LED-Leiste (WS2812 oder SK6812) basiert. Dieses Projekt wurde über mehrere Jahre von einer Vielzahl von Mitwirkenden auf GitHub entwickelt und frei zur Verfügung gestellt. Eine Wortuhr (auch als Wordclock bekannt) ist ein schönes DIY-Projekt für Anfänger, das Technologie und Design kombiniert, um eine funktionale und ästhetisch ansprechende Uhr zu schaffen. Egal, ob Sie Anfänger oder erfahrener Bastler sind, dieses Projekt ist eine großartige Gelegenheit, Ihre Fähigkeiten unter Beweis zu stellen und etwas wirklich Besonderes zu schaffen. Die Gestaltungsmöglichkeiten liegen vor allem im Rahmen und in der Wahl der Oberfläche der Uhr.

## 1.1 Hauptfunktionen

Die bereitgestellte Software zum Betreiben der Wortuhr hat mehrere Funktionen:

- Mehrsprachig (Deutsch, Englisch, Niederländisch, Italienisch, Spanisch, Ungarisch, Französisch, Rumänisch, Schweizer Deutsch, Russisch und Schwedisch)
- Unterstützung für mehrere Matrizengrößen und LED-Abstände
- Farbwechsel der Anzeigefarbe möglich (RGB oder RGBW)
- Digitale Uhranzeige
- Laufschrift, kurzer statischer Text und Symbol-Anzeige
- Regenbogenfarbwechsel
- Einstellbare Übergangsanimationen zwischen Anzeigewechseln
- Geburtstags- und Silvester-Animationen

1 Einleitung | 2
- Umgebungslicht (als Sekundenzeiger ausgeführt oder Ambientlight)
- Minuten- und Sekundenanzeige im Rahmen oder in Worten
- Automatische Helligkeitsregelung (optional über Sensor)
- Offlinebetrieb (optional über entsprechende RTC)
- Zeitserver, Zeitzone und manuelle Uhrzeit im Web-Frontend einstellbar
- Konfigurierbare Hardware- und I2C-Pins
- Konfigurierbares Startverhalten
- Auswahl an dialektspezifischen Anzeigen
- MQTT- und Home-Assistant-Einbindung mit Autodiscovery
- Wetterdaten über OpenWeatherMap bei passenden Frontplatten
- Optionaler Passwortschutz für das Web-Frontend

## 1.2 Uhrenvarianten

Die Firmware unterstützt verschiedene Frontplatten und Matrixgrößen. Die passende Variante wird später im Web-Frontend unter «Anzeigeoptionen» im Bereich «Front» ausgewählt. Wichtig ist, dass die eingestellte Matrix zur tatsächlich gebauten Buchstabenmaske und zur Anordnung der LEDs passt.

- Klassische deutsche Layouts mit 10 × 11, 11 × 11, 13 × 13, 16 × 8 oder 16 × 18 LEDs
- Kompakte Varianten mit 8 × 8 LEDs, teilweise für Viertelstunden-Anzeige
- Internationale Layouts, unter anderem Englisch, Niederländisch, Spanisch, Italienisch, Ungarisch, Französisch, Rumänisch, Schweizer Deutsch, Russisch, Schwedisch und Bengalisch
- Dialekt- und Sondervarianten wie Bayerisch, Schwäbisch, Nero, mrrioes oder Wetter-Layout
- Bauarten mit einer LED pro Buchstabe, jeder zweiten LED pro Buchstabe oder zwei, drei bzw. vier LEDs pro Buchstabe

1 Einleitung | 3

Zusätzlich können im Web-Frontend die Minutenzählrichtung, horizontale oder vertikale Spiegelung, gedrehte Layouts, zusätzliche LEDs pro Reihe, mäanderförmig verlegte LED-Streifen und die Bauart der LED-Matrix eingestellt werden. Diese Optionen sind hilfreich, wenn die LED-Streifen anders herum eingebaut wurden, die Frontplatte gespiegelt gefertigt ist oder mehrere physische LEDs einen Buchstaben ausleuchten. Änderungen an Matrixgröße und Bauart werden im EEPROM gespeichert und erst nach einem Neustart der Uhr vollständig übernommen.


Abbildung 1.1: Front- und Bauart-Konfiguration im Web-Frontend

## 1.3 Voraussetzungen

Die folgende Hardware/Software wird für dieses Projekt benötigt:

Hardware

- NodeMCU oder vergleichbares Board mit ESP8266-, ESP8285-, ESP32- oder ESP32-C3-Chip
- WS2812B RGB-LED-Streifen oder SK6812 RGBW-Streifen
- Stromversorgung 5 V / 2 A
- Optional: LDR, 10 KOhm-Widerstand

1 Einleitung | 4
- Optional: BH1750 (digitaler Helligkeitssensor, anstatt LDR)
- Optional: DS3231 (Echtzeituhr, für den Offline-Betrieb)

Software

- PlatformIO Core oder IDE (bspw. Visual Studio Code)
- Node.js
- Git

# 2 Installation der Wortuhr Software

## 2.1 Erstmaliges Aufspielen einer Binary

Für das erstmalige Aufspielen stehen auf der GitHub-Seite rechts unter «Releases» fertige Versionen der Software zur Verfügung. Programme zum Aufspielen der Binary findet man z.B. unter «https://github.com/nodemcu/nodemcu-flasher».

## 2.2 Windows

1. Installieren Sie die aktuellsten Versionen von PlatformIO, Node.js und Git manuell
2. Dadurch wird Visual Studio Code installiert, mit einem PlatformIO-Symbol (Ameisenkopf/Alien) in der Seitenleiste
3. Gehen Sie zu «Quick Access / Miscellaneous» und geben Sie den Befehl «Clone Git Project» ein, und geben Sie https://github.com/ESPWortuhr/Multilayout-ESP-Wordclock (https://github.com/ESPWortuhr/Multilayout-ESP-Wordclock) als URL ein
4. Gehen Sie dann zu «Projekte», fügen Sie das neue Projekt mit «Vorhandenes hinzufügen» zur Liste hinzu und klicken Sie auf «Öffnen».
5. In der PlatformIO-Seitenleiste erscheint nun «Project Tasks». Wählen Sie den Befehl «General / Upload» (dauert ein paar Minuten, die Software wird zuerst erstellt).
6. Schließen Sie den ESP8266 über USB an. Wenn die Wortuhr-Software erstellt ist, wird sie auf dem ESP installiert.

2 Installation der Wortuhr Software | 6

## 2.3 macOS

Der einfachste Weg ist die Installation mit «Homebrew»:

1 | brew install platformio
2 | brew install node
3 | git clone https://github.com/ESPWortuhr/Wortuhr
4 | cd Wortuhr
5 | pio run -t upload

Dabei ist der ESP über USB angeschlossen. Die Wortuhr-Software wird dabei mittels PlatformIO erstellt und auf den ESP übertragen.

## 2.4 Linux

1 | python3 -c "$(curl -fsSL https://raw.githubusercontent.com/ ...
| platformio/platformio/master/scripts/get-platformio.py)"
2 | sudo apt install npm
3 | git clone https://github.com/ESPWortuhr/Wortuhr
4 | cd Wortuhr
5 | pio run -t upload

Dabei ist der ESP über USB angeschlossen. Die Wortuhr-Software wird dabei mittels PlatformIO erstellt und auf den ESP übertragen.

## 2.5 Erster Start und WLAN-Einrichtung

Nach dem erfolgreichen Aufspielen startet die Uhr neu. Falls noch keine WLAN-Daten hinterlegt sind, erstellt sie ein eigenes WLAN für die Einrichtung. Die Standard-SSID ist «Connect_to_Wordclock», sofern sie in der Firmware-Konfiguration nicht geändert wurde.

1. Mit Smartphone oder Laptop mit dem WLAN der Uhr verbinden.
2. Falls sich kein Anmeldefenster öffnet, im Browser «http://192.168.4.1» aufrufen.

2 Installation der Wortuhr Software | 7
3. Das heimische WLAN auswählen und die Zugangsdaten eintragen.
4. Nach dem Speichern startet die Uhr neu und verbindet sich mit dem Heimnetzwerk.
5. Die danach verwendete IP-Adresse wird in der Grundeinstellung beim Start als Laufschrift ausgegeben.

## 2.6 Update der Firmware über das Web-Frontend

Mit der Software ist es möglich, die Firmware OTA (over the air), über den in der Uhr eingebauten Webserver zu aktualisieren. Dies ist in den meisten Fällen einfacher als das direkte Flashen. Ausschlaggebend für diese Vorgehensweise ist, dass die Uhr über WLAN erreichbar ist. Die Update-Schnittstelle ist dann über die Adresse http://<IP-Adresse der Uhr>:81/update erreichbar (Beispiel: http://192.168.4.1:81/update). Die Adresse der Uhr wird in der Grundeinstellung beim Start als Laufschrift ausgegeben.

## 2.7 Optionaler Zugriffsschutz für das Web-Frontend

Das Web-Frontend kann bereits in der Firmware-Konfiguration mit HTTP-Basic-Auth geschützt werden. Dazu werden in include/Config.h im Abschnitt «Web interface set-

tings» die Werte WEB_PROTECTED, WEB_USER und WEB_PASSWORD gesetzt. Ist WEB_PROTECTED auf true gestellt, fragt die Uhr beim Zugriff auf Web-Frontend, Websocket-Verbindung und OTA-Update-Seite nach Benutzername und Passwort.

Wichtig: Das Standardpasswort CHANGE_THIS_PASSWORD darf für eine produktiv verwendete Uhr nicht unverändert bleiben. Nach einer Änderung in Config.h muss die Firmware neu gebaut und auf die Uhr übertragen werden.

# 3 Hardware

Für den Aufbau der Wortuhr wird folgende elektronische Hardware benötigt:

- NodeMCU oder vergleichbares Board mit ESP8266-, ESP8285-, ESP32- oder ESP32-C3-Chip
- RGB-LED-Streifen WS2812B oder RGBW-Streifen SK6812
- Stromversorgung 5 V / 2 A
- Optional: Hardware-Taster für Power, Modus und Geschwindigkeit/Farbe
- Optional: LDR, 10 KOhm Widerstand
- Optional: BH1750 (digitaler Helligkeitssensor, ersetzt LDR)
- Optional: DS3231 (Echtzeituhr, für Offline-Betrieb)

Neben der Elektronik werden für den mechanischen Aufbau weitere Materialien benötigt. Da es verschiedene Arten gibt, eine Uhr zu bauen, sind hier nur die grundlegenden Dinge aufgeführt:

- Bilderrahmen (Holz oder Metall mit mindestens 14 mm Rahmenhöhe)
- Diffusorfolie
- Buchstabenmaske
- Abstandsgitter (Holz oder Kunststoffschaum)

3 Hardware | 9

## 3.1 Pegelanpassung

Der ESP arbeitet intern mit einer Betriebsspannung von 3,3 V. Die WS2812(B)-Streifen arbeiten dagegen mit 5 V. Dies erfordert eine Pegelanpassung, damit die digitalen Signale fehlerfrei zu den Streifen übertragen werden können. Ohne Anpassung kann es auch funktionieren, muss es aber nicht. Es gilt: "Der minimale High-Pegel des Ausgangs muss höher sein als der minimale High-Pegel des Eingangs"Was heißt das im Klartext? Laut Datenblatt des LED-Streifens sind folgende Pegel notwendig, um ein «sauberes» HIGH- und LOW-Signal zu bekommen. Um ein HIGH-Signal am Eingang des WS2812B-Streifens zu erzeugen, muss laut Datenblatt (Bild 1) mindestens ein Pegel von 4,3 V erzeugt werden. Da der ESP aber maximal 3,3 V erzeugen kann, wird hier kein sicheres HIGH-Signal erzeugt.

Nun kommt der Trick mit der Diode: Die erste LED wird nun mit einer Diode in der Plus-Leitung betrieben. Die Durchlassspannung der Diode beträgt 0,7 V. Das heißt, dass die erste LED mit 4,3 V betrieben wird. Das ist laut Datenblatt auch zulässig. Bei 4,3 V beträgt der benötigte HIGH-Pegel nun noch 3,6 V. Da die Hersteller noch Toleranzen mit einberechnen, funktioniert das ganze Konstrukt wieder. Nun gibt die erste LED den Pegel mit 4,3 V an die nächste LED weiter. Diese wird wieder mit 5 V betrieben und der HIGH-Pegel liegt mit 4,3 V wieder innerhalb der Datenblatt-Toleranz. Die zweite LED verstärkt sozusagen das Signal wieder auf die vollen 5 V. Das heißt, die erste LED wird sozusagen als Pegelanpassung missbraucht.

## 3.2 Anschlussbeispiel

Der Datenpin des LED-Streifens ist in der Grundeinstellung an dem Port «Rx» (GPIO3) angeschlossen. Damit bleibt die bisherige ESP8266-Ansteuerung mit festem RX-Pin kompatibel. Wird der LED-Pin in der Hardware-Konfiguration geändert, verwendet die Firmware auf dem ESP8266 automatisch die Bit-Bang-Ansteuerung für den gewählten GPIO. Wie auf dem Schaltbild muss eine Diode in die +5-V-Leitung der ersten LED. Die +5-V-Leitung zwischen der ersten und zweiten LED muss durchtrennt werden (aber nur diese, nicht Daten und GND!). Am zweiten Streifen wird dann zusätzlich vom Netzteil +5 V eingespeist. Die LEDs vom ersten Streifen werden dann sozusagen «rückwärts» mit den nötigen +5 V versorgt.

3 Hardware | 10

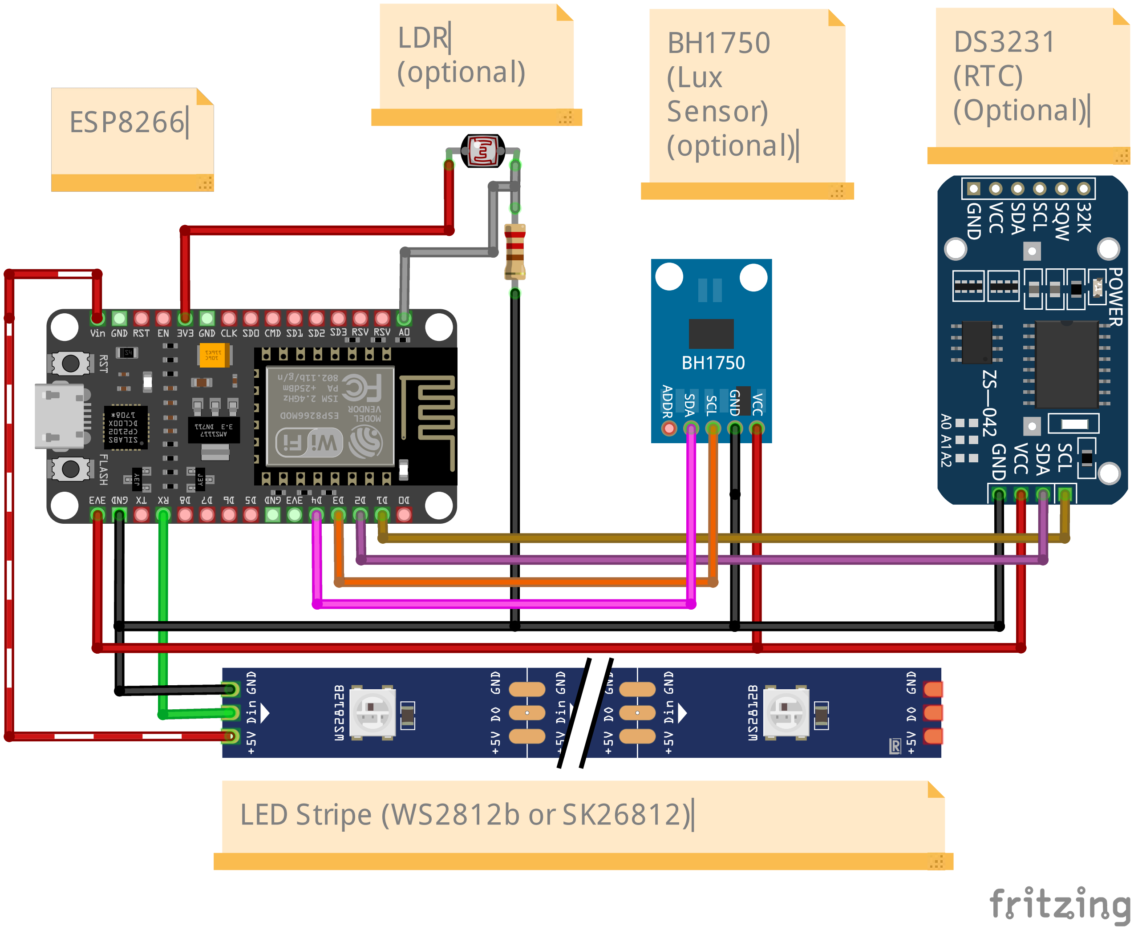
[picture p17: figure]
DS3231 (RTC) (Optional); BH1750 (Lux Sensor) (optional); LED Stripe (WS2812b or SK26812); ESP8266; LDR (optional)

Abbildung 3.1: Anschlussbeispiel

## 3.3 Konfigurierbare Hardware-Pins

Die Firmware kann den Datenpin des LED-Streifens und drei optionale Hardware-Taster konfigurieren. Die Konfiguration wird im Web-Frontend unter «Einstellungen» im Bereich «Hardware-Pins» vorgenommen. Es muss immer die GPIO-Nummer des Controllers eingetragen werden, nicht die auf dem Board aufgedruckte Bezeichnung. Bei NodeMCU-Boards ist zum Beispiel «D4» nicht die richtige Eingabe, sondern die zugehörige GPIO-Nummer.

3 Hardware | 11

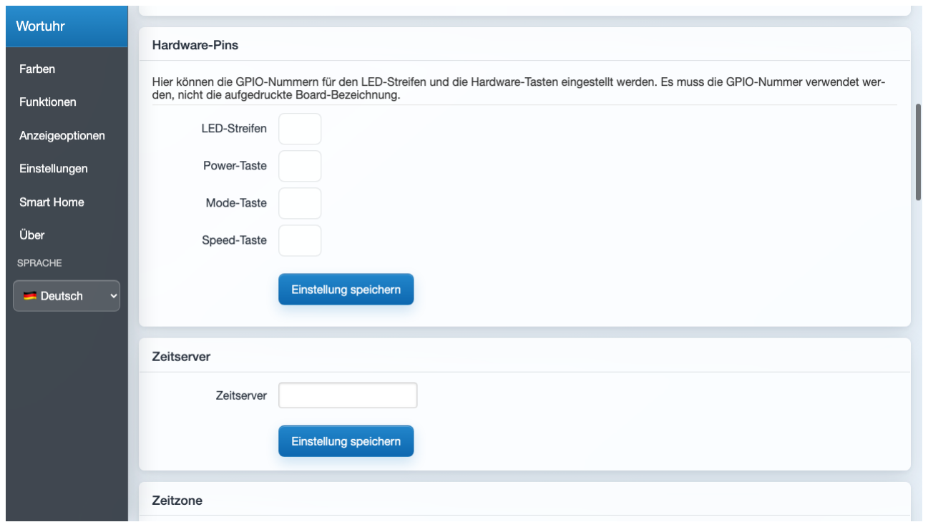
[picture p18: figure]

Abbildung 3.2: Hardware-Pin-Konfiguration im Web-Frontend

### 3.3.1 Standard-Pins

Funktion | Standard-GPIO | Hinweis
LED-Streifen | GPIO3 | Auf ESP8266 entspricht dies RX und nutzt die alte, feste Standard-Ansteuerung.
Power-Taste | GPIO2 | Taster gegen GND; wird per internem Pull-up gele-sen.
Mode-Taste | GPIO13 | Kurzer Druck: nächster Modus; langer Druck: nächste Transition.
Speed-Taste | GPIO14 | Kurzer Druck: Helligkeit; langer Druck: Farbton.
Tabelle 3.1: Standardbelegung der konfigurierbaren Hardware-Pins

Die Taster werden mit INPUT_PULLUP betrieben. Ein Taster verbindet den GPIO daher beim Drücken mit GND. Für alle vier Hardware-Pins gilt: Jeder GPIO darf nur einmal verwendet werden. Die Firmware prüft doppelte Pins und ungültige Werte und stellt bei ungültigen EEPROM-Werten wieder die Standard-Pins her.

### 3.3.2 I2C-Pins und I2C-Scan

Im selben Bereich können auch die I2C-Pins für optionale I2C-Geräte wie BH1750-Helligkeitssensor oder DS3231-Echtzeituhr eingestellt werden. Für den ESP8266 sind

3 Hardware | 12

die Standardwerte SDA = D2 und SCL = D1, beim klassischen ESP32 SDA = GPIO21 und SCL = GPIO22. Beim ESP32-C3 sind die I2C-Pins standardmäßig deaktiviert und müssen passend zum verwendeten Board gesetzt werden.

Der Wert 255 deaktiviert einen I2C-Pin. SDA und SCL müssen immer gemeinsam gesetzt oder gemeinsam deaktiviert werden. Nach dem Speichern kann mit «I2C-Adressen suchen» geprüft werden, ob angeschlossene Geräte auf dem gewählten Bus antworten. Gefundene Adressen werden im Web-Frontend angezeigt; bei ungültigen oder deaktivierten Pins erscheint eine entsprechende Meldung.

### 3.3.3 Geeignete Pins je Controller

Die folgenden Empfehlungen beziehen sich auf die in diesem Projekt verwendeten Controller-Varianten. Zusätzlich muss geprüft werden, welche Pins auf dem konkreten Entwicklungsboard wirklich herausgeführt sind. Einige Hersteller drucken Board-Bezeichnungen wie «D1» oder «RX» auf; in der Web-Konfiguration wird trotzdem die GPIO-Nummer eingetragen.

ESP8266 / ESP8285

Für ESP8266-Boards akzeptiert die Firmware GPIO0 bis GPIO16. Empfehlenswert sind:

- LED-Streifen: Standard GPIO3/RX. Alternativ GPIO4, GPIO5, GPIO12, GPIO13 oder GPIO14.
- Hardware-Taster: GPIO4, GPIO5, GPIO12, GPIO13 oder GPIO14. GPIO2 ist als Standard für die Power-Taste nutzbar, darf beim Booten aber nicht auf LOW gezogen werden.
- Nicht verwenden: GPIO6 bis GPIO11, da diese üblicherweise mit dem Flash-Speicher verbunden sind.
- Mit Vorsicht verwenden: GPIO0, GPIO2 und GPIO15 sind Boot-Strapping-Pins. Falsche Pegel beim Einschalten können den Bootvorgang verhindern. GPIO16 hat keinen normalen internen Pull-up und ist deshalb für die Taster-Schaltung nicht empfohlen.

3 Hardware | 13

ESP32

Für ESP32-Boards akzeptiert die Firmware GPIO0 bis GPIO39. Empfehlenswert sind:

- LED-Streifen: GPIO4, GPIO13 bis GPIO19, GPIO21 bis GPIO23, GPIO25 bis GPIO27, GPIO32 oder GPIO33. GPIO3 bleibt als Standard aus Kompatibilitätsgründen möglich, liegt aber oft auf RX0.
- Hardware-Taster: GPIO4, GPIO13 bis GPIO19, GPIO21 bis GPIO23, GPIO25 bis GPIO27, GPIO32 oder GPIO33.
- Nicht verwenden: GPIO6 bis GPIO11, da diese üblicherweise mit dem SPI-Flash verbunden sind.
- Nicht für den LED-Streifen verwenden: GPIO34 bis GPIO39, da diese nur Eingang sind. Für Taster sind sie nur mit externem Pull-up geeignet, da sie keine internen Pull-up-/Pull-down-Widerstände besitzen.
- Mit Vorsicht verwenden: GPIO0, GPIO2, GPIO5, GPIO12 und GPIO15 sind Boot-Strapping-Pins. GPIO1 und GPIO3 sind die Standard-UART-Pins und können die serielle Ausgabe stören.

ESP32-C3

Der ESP32-C3 besitzt GPIO0 bis GPIO21. Auch wenn die Weboberfläche höhere Zahlen nicht verhindert, sollten nur tatsächlich vorhandene Pins des Boards verwendet werden. Empfehlenswert sind:

- LED-Streifen und Hardware-Taster: GPIO0, GPIO1, GPIO3, GPIO4, GPIO5, GPIO6, GPIO7, GPIO10, GPIO11, GPIO20 oder GPIO21, sofern diese Pins auf dem verwendeten Board herausgeführt sind.
- Nicht verwenden: GPIO12 bis GPIO17, da diese üblicherweise mit SPI-Flash oder PSRAM verbunden sind.
- Mit Vorsicht verwenden: GPIO2, GPIO8 und GPIO9 sind Boot-Strapping-Pins. GPIO18 und GPIO19 sind standardmäßig für USB-JTAG vorgesehen.
- Hinweis zu den Standard-Pins: GPIO13 und GPIO14 sind auf ESP32-C3-Boards häufig nicht als freie GPIOs nutzbar. Für ESP32-C3 sollten die Button-Pins daher vor dem Verdrahten auf geeignete freie GPIOs geändert werden.

3 Hardware | 14

Die Einschränkungen orientieren sich an den GPIO-Hinweisen der Espressif-Dokumentation für ESP32 und ESP32-C3 sowie den bekannten ESP8266-Boot- und Flash-Pins.

### 3.3.4 Bedienung der Hardware-Taster

- Power-Taste: schaltet die LEDs aus und bei erneutem Druck wieder mit den vorherigen Farben ein.
- Mode-Taste: kurzer Druck wechselt zum nächsten Anzeigemodus, langer Druck zur nächsten Transition.
- Speed-Taste: kurzer Druck erhöht die Helligkeit, langer Druck wechselt den Farbton.

# 4 Funktionen der Uhrensoftware auf

# dem ESP

## 4.1 Anzeigemodi im Web-Frontend

Die wichtigsten Funktionen werden im Web-Frontend unter «Funktionen» ausgewählt. Neben der klassischen Wortuhr stehen Sekundenanzeige, Digitaluhr, Laufschrift, Regenbogen, Farbwechsel, feste Farbe und Symbol-Anzeige zur Verfügung. Je nach Modus werden darunter nur die jeweils passenden Einstellungen eingeblendet, zum Beispiel Geschwindigkeit, Helligkeit, Lauftext oder Symbolauswahl.

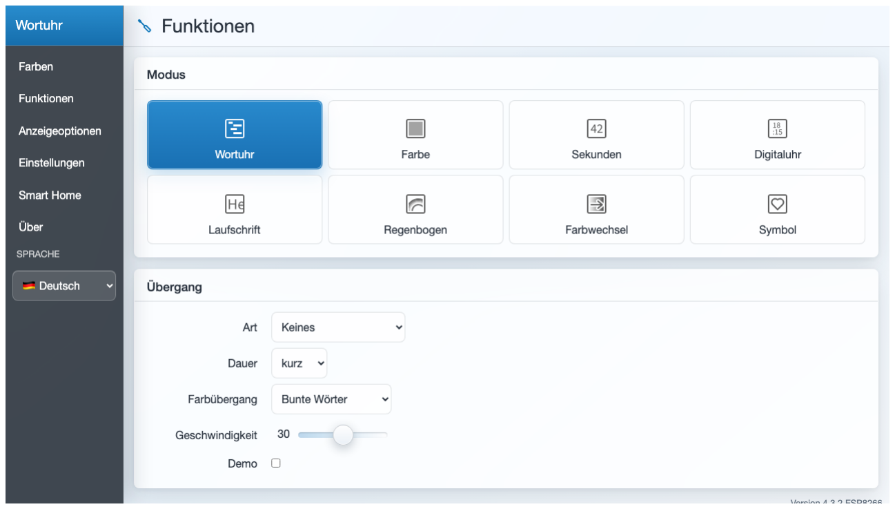
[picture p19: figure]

Abbildung 4.1: Auswahl der Anzeigemodi im Web-Frontend

Im Modus «Laufschrift» wird der unter «Lauftext» gespeicherte Text über die Matrix bewegt. Sehr kurze Texte werden automatisch anders behandelt: Nach dem Entfernen führender und nachfolgender Leerzeichen werden ein oder zwei Zeichen statisch zentriert

4 Funktionen der Uhrensoftware auf dem ESP | 16

angezeigt, sofern sie auf die gewählte Matrix passen. Ein- oder zweistellige Zahlen werden dabei wie eine kleine Digitalanzeige dargestellt.

Im Modus «Symbol» kann eines der vordefinierten Bitmap-Symbole angezeigt werden. Zur Auswahl stehen Herz, Smiley, Note, Schneeflocke, Brief, Glocke, Stop und Standby. Die Farbe wird über die normalen Vordergrund-Farbeinstellungen bestimmt; die Geschwindigkeit beeinflusst die Wiederholung bzw. Aktualisierung des Modus.


Abbildung 4.2: Symbol-Auswahl im Web-Frontend

## 4.2 Übergänge und Animationen

Unter «Funktionen» kann im Bereich «Übergang» eingestellt werden, wie Änderungen der Wortmatrix animiert werden. Zur Auswahl stehen unter anderem Hoch- und Runterscrollen, Schieben nach links oder rechts, Überblenden, Laser, Matrix-Regen, Bälle, Feuerwerk, Schlange, Bunt und Zufällig. Zusätzlich lassen sich Dauer, Geschwindigkeit und die Einfärbung der Animation einstellen. Die Option «Demo» löst die gewählte Transition zu Testzwecken aus.

Einige Animationen werden auch für besondere Ereignisse verwendet. An Silvester zeigt die Uhr einen Countdown und anschließend eine Feuerwerksanimation. Im Bereich «Geburtstage» können bis zu fünf Termine im Format MM-DD hinterlegt werden. An diesen Tagen erscheint alle fünf Minuten eine Feuerwerksanimation. Bei kompatiblen Frontplatten werden währenddessen die Wörter «Happy Birthday» statt der Uhrzeit angezeigt.

4 Funktionen der Uhrensoftware auf dem ESP | 17

## 4.3 Anzeigeoptionen

Unter «Anzeigeoptionen» werden nicht nur Frontplatte und Bauart gesetzt, sondern auch die Darstellung von Sprache, Minuten, Sekunden und Startverhalten angepasst.

### 4.3.1 Sprach- und Minutenlogik

Im Bereich «Sprache» kann eingestellt werden, wann der Text «Es ist» angezeigt wird. Außerdem lassen sich sprachliche Varianten für Viertelstunden und Zwanzig-Minuten-Angaben wählen, zum Beispiel «viertel nach neun» oder «viertel zehn». Diese Optionen hängen von der gewählten Sprache und Frontplatte ab.

Die Minutenanzeige kann deaktiviert oder über zusätzliche LEDs dargestellt werden. Je nach Bauart stehen vier Minuten-LEDs, sieben Minuten-LEDs, Ecken oder die Anzeige in Worten zur Verfügung. Die Einstellung muss zur mechanischen Front und zur Verdrahtung passen.

### 4.3.2 Sekunden im Rahmen

Die Sekundenanzeige im Rahmen kann ausgeschaltet oder als Punkt, Sektor oder umlaufender Sektor dargestellt werden. Diese Funktion setzt voraus, dass die gebaute Uhr entsprechende Rahmen-LEDs besitzt. Bei Frontplatten ohne Rahmen-LEDs sollte die Anzeige deaktiviert bleiben.

### 4.3.3 Boot-Optionen

Im Bereich «Boot» wird festgelegt, was beim Neustart sichtbar sein soll. Die LEDs können kurz aufblitzen, einmal durchlaufen, während der Netzwerksuche ein WLAN-Symbol anzeigen und nach erfolgreicher Verbindung die IP-Adresse ausgeben. Die IP-Anzeige ist besonders hilfreich, wenn die Uhr per Browser konfiguriert oder ein OTA-Update gestartet werden soll.

4 Funktionen der Uhrensoftware auf dem ESP | 18

## 4.4 Verbinden der Uhr mit dem eigenen WLAN

Nach dem erfolgreichen Verbinden kann die Uhr nach Eingabe der angezeigten IP-Adresse in einem Browser konfiguriert werden. Dabei kann die Uhr auch mit dem eigenen WLAN Netz verbunden werden.

Die WLAN-Konfiguration befindet sich im Web-Frontend unter «Einstellungen» im Bereich «Wi-Fi / WLAN». Dort kann die Neukonfiguration gestartet oder das WLAN bis zum Neustart deaktiviert werden.


Abbildung 4.3: WLAN-Konfiguration im Web-Frontend

## 4.5 Zeitserver (NTP Server)

Falls die Uhr an das eigene WLAN mit Internet angebunden wird, kann ein Zeitserver hinterlegt werden. Dieser sorgt dafür, dass die Uhrzeit zyklisch sekundengenau gestellt wird.

Der Zeitserver wird im Web-Frontend unter «Einstellungen» im Bereich «Zeitserver» eingetragen und gespeichert.

4 Funktionen der Uhrensoftware auf dem ESP | 19

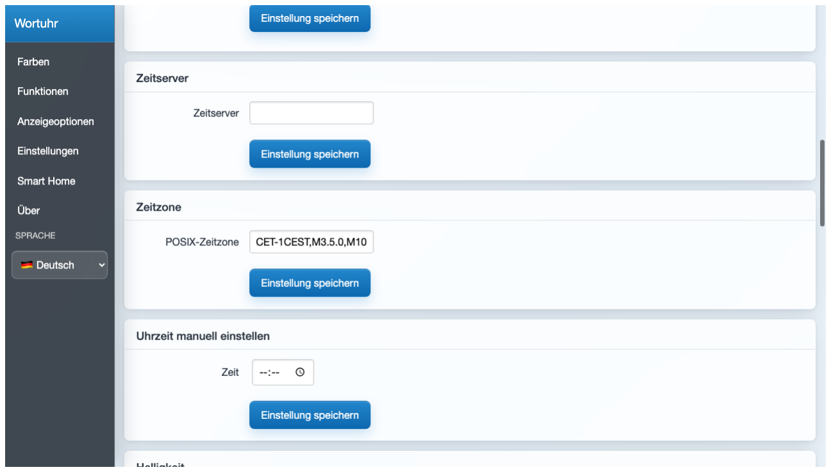
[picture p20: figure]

Abbildung 4.4: Zeitserver-Konfiguration im Web-Frontend

## 4.6 Zeitzone und manuelle Uhrzeit

Die Zeitzone wird im Web-Frontend unter «Einstellungen» im Bereich «Zeitzone» als POSIX-Zeitzone gespeichert. Für Deutschland ist die Voreinstellung CET-1CEST,M3.5. 0,M10.5.0/3. Die POSIX-Schreibweise enthält neben der Abweichung zur UTC auch die Regeln für Sommer- und Winterzeit; dadurch kann die Uhr die lokale Zeit korrekt aus der vom Zeitserver gelieferten UTC-Zeit berechnen.

Im Bereich «Uhrzeit manuell einstellen» kann die Uhrzeit direkt gesetzt werden. Das ist vor allem für Tests, für den Betrieb ohne WLAN oder als schnelle Korrektur hilfreich. Wenn die Uhr später wieder einen Zeitserver erreicht, wird die Zeit erneut per NTP synchronisiert.

4 Funktionen der Uhrensoftware auf dem ESP | 20

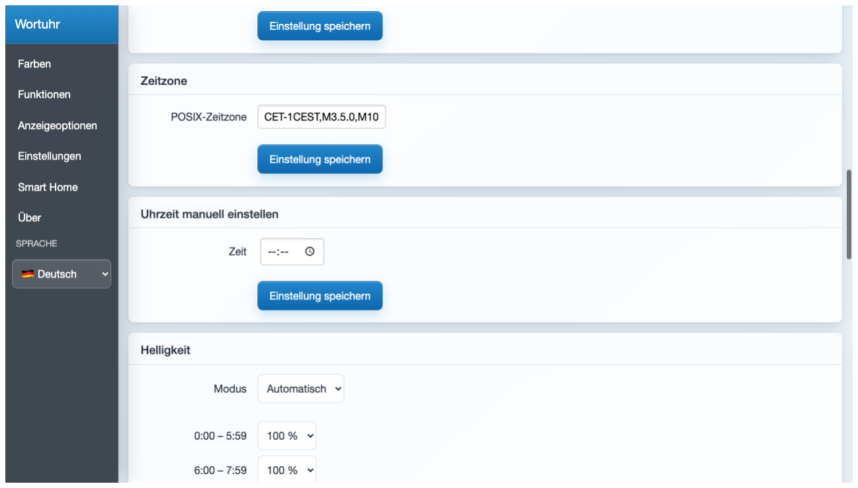
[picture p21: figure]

Abbildung 4.5: Zeitzone und manuelle Uhrzeit im Web-Frontend

## 4.7 Automatische Helligkeitsregelung

Falls der optionale LDR an der Uhr angeschlossen wurde, ist es möglich, die Helligkeit automatisch, abhängig der Umgebungshelligkeit, regeln zu lassen. Dazu muss folgende Einstellung aktiviert werden. Durch das Feld Kalibrierung kann man die Grundhelligkeit an seine eigenen Wünsche anpassen.

Die automatische Helligkeit wird im Web-Frontend unter «Einstellungen» im Bereich «Helligkeit» konfiguriert. Im Modus «Automatisch» können minimale und maximale LED-Helligkeit sowie das Referenz-Umgebungslicht angepasst werden.

4 Funktionen der Uhrensoftware auf dem ESP | 21


Abbildung 4.6: Automatische Helligkeitsregelung im Web-Frontend

Im manuellen Modus kann die Helligkeit zeitabhängig gesetzt werden. Dafür stehen Zeitbereiche von 0:00 bis 23:59 Uhr zur Verfügung, die jeweils auf 100 %, 80 %, 60 %, 40 %, 20 % oder «Aus» gestellt werden können. So kann die Uhr nachts automatisch dunkler leuchten, auch wenn kein Helligkeitssensor angeschlossen ist.

## 4.8 LED-Typ, Weißpunkt und Wetterdaten

Unter «Einstellungen» kann der verwendete LED-Typ ausgewählt werden. Für WS2812-Streifen stehen verschiedene Farbreihenfolgen wie BRG, GRB, RGB, RBG und BGR zur Verfügung. Bei SK6812-RGBW-Streifen kann zusätzlich der Typ der weißen LED als Warmweiß, Neutralweiß oder Kaltweiß gesetzt werden. Wenn Farben falsch angezeigt werden, ist dies meistens die erste Einstellung, die geprüft werden sollte.

Für Wetter-Frontplatten kann im Bereich «Wetter» ein OpenWeatherMap-API-Schlüssel und eine City-ID hinterlegt werden. Die Uhr ruft damit Wettervorhersagen ab und kann diese auf Layouts anzeigen, die Wetterwörter bzw. Wetterbereiche unterstützen. Ohne passende Frontplatte oder ohne gültigen API-Schlüssel bleibt diese Funktion wirkungslos.

4 Funktionen der Uhrensoftware auf dem ESP | 22

## 4.9 Smart Home und MQTT

Die Uhr kann über MQTT in ein Smart-Home-System eingebunden werden. Im Web-Frontend befindet sich dafür der Bereich «Smart Home». Dort werden MQTT aktiviert sowie Serveradresse, Port, Benutzername, Passwort, Client-ID und Topic gespeichert. Die MQTT-Zugangsdaten können alternativ bereits in include/Config.h vorkonfiguriert werden.

Über MQTT lassen sich grundlegende Funktionen wie Ein-/Ausschalten, Helligkeit, Farbe, Effekt bzw. Modus, Lauftext, automatische Helligkeit und Übergangseinstellungen steuern. Statuswerte wie aktuelle Farbe, Helligkeit, Modus, WLAN-Signal, Uptime und Sensordaten werden ebenfalls veröffentlicht.

Mit «Sende HA Discovery» sendet die Uhr die Home-Assistant-Autodiscovery-Konfiguration. Danach erscheint sie in Home Assistant als MQTT-Gerät mit Licht-Entität und zusätzlichen Steuerelementen, ohne dass die YAML-Konfiguration manuell angelegt werden muss. Voraussetzung ist ein erreichbarer MQTT-Broker und aktivierte MQTT-Discovery in Home Assistant.

## 4.10 Neustart und Zurücksetzen

Im Bereich «Neu starten / Zurücksetzen» kann die Uhr direkt aus dem Web-Frontend neu gestartet werden. Außerdem können die gespeicherten Einstellungen auf Standardwerte zurückgesetzt werden. Nach Änderungen an Matrixgröße, Bauart, Hardware-Pins oder anderen systemnahen Einstellungen zeigt das Web-Frontend einen Hinweis an, wenn ein Neustart empfohlen wird.

4 Funktionen der Uhrensoftware auf dem ESP | 23

## 4.11 Fehlersuche

Problem | Mögliche Ursache und Lösung
Kein WLAN der Uhr sichtbar | Die Uhr neu starten und eini-ge Sekunden warten. Falls bereits WLAN-Daten gespeichert sind, startet kein Captive Portal. Dann die aktuelle IP-Adresse verwenden oder die WLAN-Konfiguration im Web-Frontend erneut starten.
Web-Frontend ist nicht erreichbar | Prüfen, ob sich Gerät und Uhr im gleichen Netzwerk befinden. Die beim Start angezeigte IP-Adresse verwenden und bei OTA-Updates den Port :81 ergänzen.
Web-Frontend fragt nach Benutzername und Passwort | In include/Config.h ist WEB_PROTECTED aktiviert. Mit den dort gesetzten Werten WEB_USER und WEB_PASSWORD anmelden.
LEDs bleiben dunkel | 5-V-Versorgung, GND-Verbindung, Datenrichtung des LED-Streifens und den ein-gestellten LED-Pin prüfen. Bei optionalen Tastern darf kein Boot-Strapping-Pin dauerhaft auf LOW gezogen werden.
Farben werden falsch angezeigt | Im Web-Frontend unter «Einstel-lungen» den LED-Typ bzw. die Farbreihenfolge anpassen. Unter-schiedliche LED-Streifen verwen-den verschiedene RGB-/RGBW-Reihenfolgen.
Uhrzeit stimmt nicht | WLAN-Verbindung, Zeitserver, Zeitzone und Internetzugang prü-fen. Für den Offline-Betrieb muss eine RTC wie DS3231 korrekt an-geschlossen sein oder die Uhrzeit manuell gesetzt werden.

Tabelle 4.1: Häufige Fehler und erste Prüfschritte

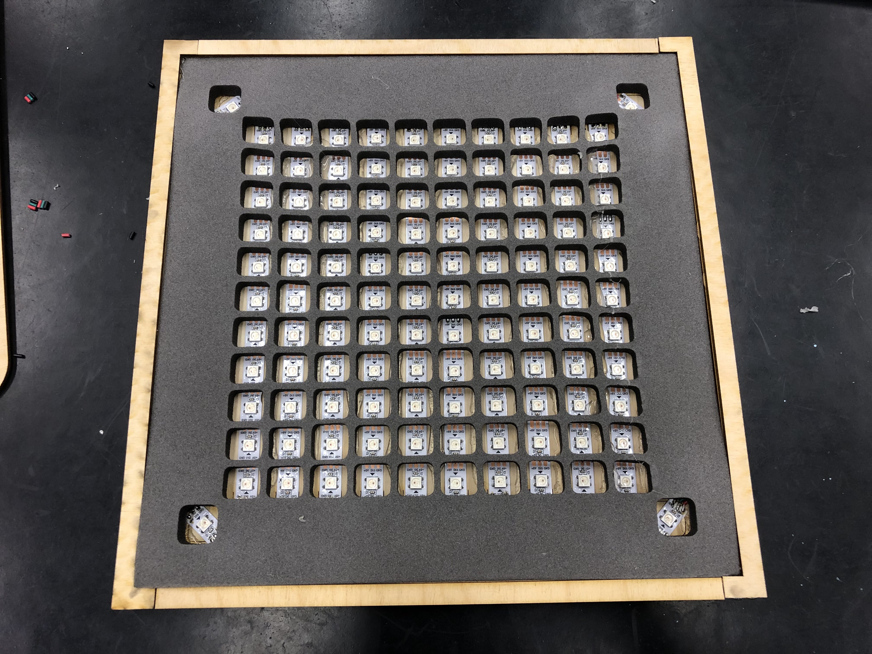
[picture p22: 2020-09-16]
pics/Lasercutted/UHR114_Step_5.jpg

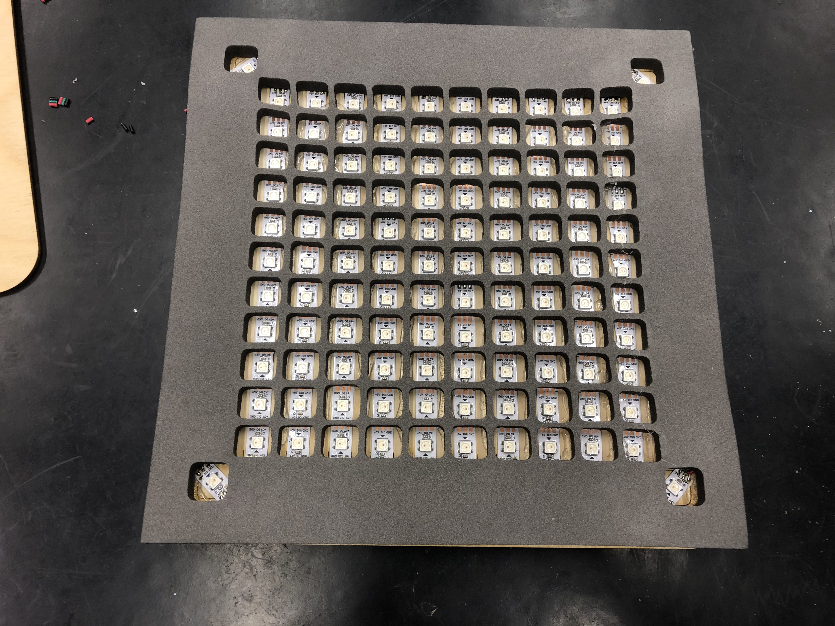
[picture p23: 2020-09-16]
pics/Lasercutted/UHR114_Step_4.jpg

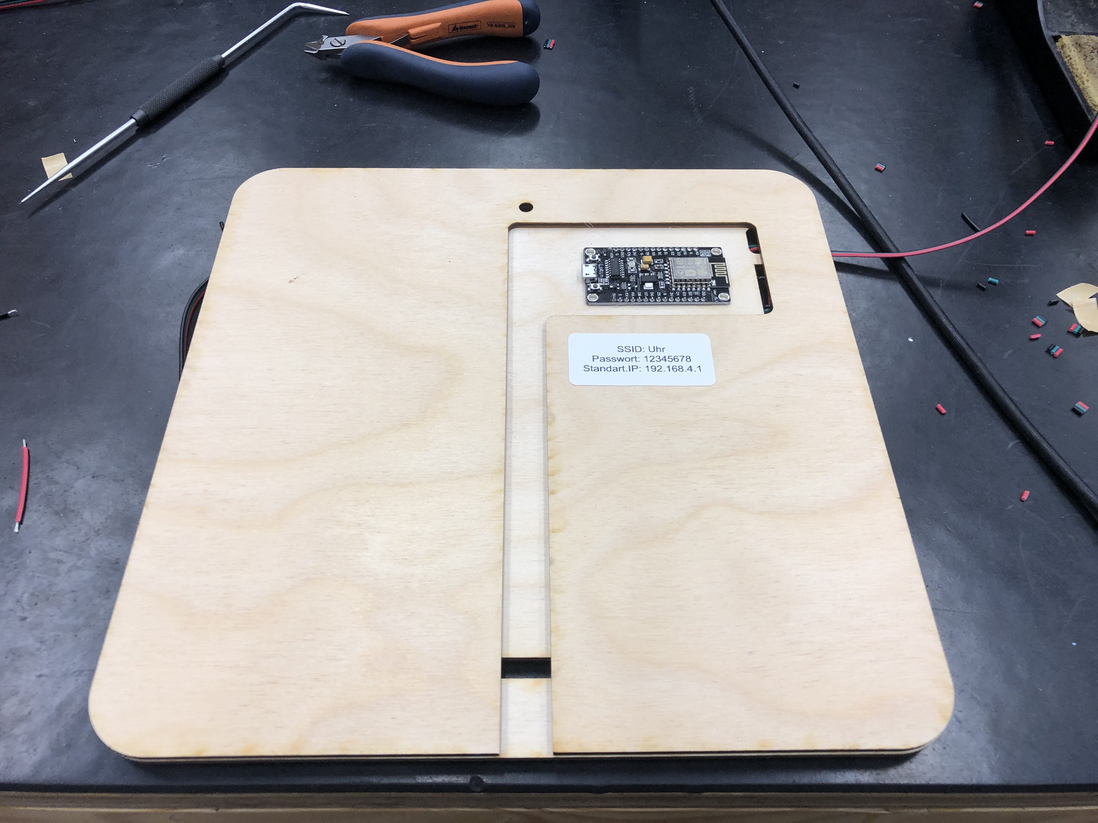
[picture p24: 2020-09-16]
pics/Lasercutted/UHR114_Step_Back_Assembly_Step_1.jpg

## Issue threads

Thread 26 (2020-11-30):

[BUG] Hostname wird nicht gespeichert

michi1g, 2020-11-30:
Hostname wird im Backend nicht geändert

tali, 2021-01-27:
Behoben mit bb6cc05 und c9811c38.

Closed 2021-01-27.

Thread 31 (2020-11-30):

[BUG] Funktionsanzeige nach verlassen der Webseite falsch

michi1g, 2020-11-30:
Wenn ich die Webseite verlasse nachdem ich z.B. Sekunden eingestellt habe, wird beim erneuten Besuch der Seite Wortuhr angezeigt, obwohl die Sekundenanzeige noch läuft.
Bei einem normalen reload der Seite tritt der Fehler nicht auf

dbambus, 2020-12-02:
Ja, das liegt daran, dass die Website die Config erst beim Besuch der "Einstellungen" Unterseite anfragt. Kannst du mal überprüfen, erst auf die "Einstellungen" Seite zu gehen und dann auf "Funktionen". Ist dann der Bug auch vorhanden ?

michi1g, 2020-12-02:
Bug ist auch vorhanden wenn man vorher auf Einstellungen gegangen ist

dbambus, 2020-12-02:
Ich habe da mal wieder nachgesehen. Ich kann den Fehler soweit auf den HTML Code zurückführen.

Bei Radio-Buttons kann man das checked Attribut als vorselektierbares Element verwenden, während man zum Beispiel bei einem DropDown Menü relativ einfach über das <select> Attr. eine Vorauswahl anhand eines eingelesenen Parameters machen kann. Dies ist bei Radio-Buttons nicht so einfach möglich. @michi1g kannst du da vielleicht suchen ? Wie man das in HTML und JS hinbekommt ?

Eine (un-)schöne Möglichkeit wäre, dass man da keine Checkboxen verwendet, sondern Dropdowns.

Eisbaeeer, 2020-12-02:
Du musst das value als  char checkbox[8] = "checked" oder  checkbox[0]=0 auswerten. Habe ich in anderen Projekten schon so gemacht. Gruß Eisbaeeer Von meinem/meiner Galaxy gesendet
-------- Ursprüngliche Nachricht --------Von: dbambus <notifications@github.com> Datum: 02.12.20  15:21  (GMT+01:00) An: dbambus/Worduhr-v3 <Worduhr-v3@noreply.github.com> Cc: Subscribed <subscribed@noreply.github.com> Betreff: Re: [dbambus/Worduhr-v3] [BUG] Funktionsanzeige nach verlassen der Webseite falsch (#31)

Ich habe da mal wieder nachgesehen. Ich kann den Fehler soweit auf den HTML Code zurückführen.

Bei Radio-Buttons kann man das checked Attribut als vorselektierbares Element verwenden, während man zum Beispiel bei einem DropDown Menü relativ einfach über das  Attr. eine Vorauswahl anhand eines eingelesenen Parameters machen kann. Dies ist bei Radio-Buttons nicht so einfach möglich. @michi1g kannst du da vielleicht suchen ? Wie man das in HTML und JS hinbekommt ?

Eine (un-)schöne Möglichkeit wäre, dass man da keine Checkboxen verwendet, sondern Dropdowns.

—You are receiving this because you are subscribed to this thread.Reply to this email directly, view it on GitHub, or unsubscribe.

dbambus, 2020-12-03:
Hey @Eisbaeeer,

würde deine Lösung auch für Radio-Buttons funktionieren, da Checkboxen doch was anderes sind. Und wäre es möglich, dass du dich der Problematik annimmst ?
Ich würde mich um andere Bugs kümmern wollen, um den Release noch vor Weihnachten hinzubekommen.

LG
dbambus

Eisbaeeer, 2020-12-03:
Radio Button geht sicher auch. Hier mal das Beispiel, wie das bei mir realisiert ist:
Im HTML:
`const char _PAGE_CONFIG_YOUTU[] PROGMEM  = "<label class=inline><input type=checkbox name=youtu value=checked %YOUTUSTAT% > YoutTube Abonnenten</label>";`
Im Code:
` TokenStringPair youtupair[1];
youtupair[0].setPair("%YOUTUSTAT%", youtuStat);
webpage.add_P(_PAGE_CONFIG_YOUTU, youtupair,1);`
Den Status von der Webseite abholen:
`void getConfig() {
// YouTubeCheckbox
  String youtubeString = server.arg("youtu");
  youtubeString.toCharArray(youtuStat,8);
}`

Das Problem ist eben, dass es kein wirkliches Value gibt, ob die Checkbox an oder aus ist.
Ich kann mir das schon mal anschauen, aber im Moment (also vor Weihnachten) wird das nichts, sorry.
Gruß Eisbaaaer

dbambus, 2021-01-28:
@ATho95 und @tali,

ist das nicht im aktuellem Branch schon behoben ?

dbambus, 2021-01-28:
Ah richtig, grad getestet. Aber wenn man von einer alternativen Anzeige zurück auf die Wortuhr wechselt, dann wird die Anzeige erst nach einer vollen Minute aktualisiert gleiches gilt für die Änderung der Farbe, das gilt es noch zu beheben. Da würde ich mich aber morgen drum bemühen wollen.

Closed 2021-02-01.

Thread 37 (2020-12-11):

Compile error Wifi Manager

Eisbaeeer, 2020-12-11:
Hi
Get compile error regarding wifi-manager.
Arduino version 1.8.14

`

WARNUNG: Bibliothek Timezone behauptet auf avr Architektur(en) ausgeführt werden zu können und ist möglicherweise inkompatibel mit Ihrem derzeitigen Board, welches auf esp8266 Architektur(en) ausgeführt wird.
In file included from sketch\Network.cpp:8:0:

WiFiManager::getRSSIasQuality(int)' is private
     int           getRSSIasQuality(int RSSI);
                   ^
Network.cpp:20:42: error: within this context
  return wifiManager.getRSSIasQuality(rssi);
                                          ^
sketch\Network.cpp: In function 'void Network_disable()':
Network.cpp:24:14: error: 'class WiFiManager' has no member named 'disconnect'
  wifiManager.disconnect();
              ^
sketch\Network.cpp: In function 'void Network_reboot()':
Network.cpp:28:14: error: 'class WiFiManager' has no member named 'reboot'
  wifiManager.reboot();
              ^
sketch\Network.cpp: In function 'void Network_resetSettings()':
Network.cpp:33:14: error: 'class WiFiManager' has no member named 'reboot'
  wifiManager.reboot();
              ^
sketch\Network.cpp: In function 'String Network_getSSID()':
Network.cpp:37:21: error: 'class WiFiManager' has no member named 'getWiFiSSID'
  return wifiManager.getWiFiSSID();
                     ^
sketch\Network.cpp: In function 'void Network_setup(const char*)':
Network.cpp:41:14: error: 'class WiFiManager' has no member named 'setHostname'
  wifiManager.setHostname(hostname);
              ^
sketch\Network.cpp: In function 'void Network_loop()':
Network.cpp:47:14: error: 'class WiFiManager' has no member named 'process'
  wifiManager.process();
              ^
C:\Users\Lars Weimar\OneDrive\Dokumente\Arduino\Wortuhrv3\Wortuhrv3.ino: In function 'void setup()':
Wortuhrv3:359:14: error: 'class PubSubClient' has no member named 'setServer'
   mqttClient.setServer(G.MQTT_Server, G.MQTT_Port);
              ^
Wortuhrv3:360:14: error: 'class PubSubClient' has no member named 'setCallback'
   mqttClient.setCallback(MQTT_callback);
              ^
exit status 1
within this context
`

Eisbaeeer, 2020-12-11:
Version 2.5 compiles without errors ;-)

Eisbaeeer, 2020-12-14:
Ja das kann ich bestätigen. Die Version 2.5 ist stable und läuft bei mir jetzt schon einige Tage durch (auch mit Openweathermap). Ich schließe dann das issue.

Closed 2020-12-14.

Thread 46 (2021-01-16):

Erweiterung um animierte Anzeigen

ATho95, 2021-01-16:
Hallo, ich habe vor Jahren schonmal was für die Wortuhr gemacht. Bevor ich das publik machen konnte war das Projekt verschwunden. Bin jetzt auf dieses Repository gestossen. Falls interesse besteht, würde ich meine Änderungen bereitstellen. Da ich jetzt selber den master nutze, habe ich auch Anpassungen an meine Uhren-HW gemacht.
Hier mal ein Überblick:
- Übergangsanimationen
- Silvesterfeuerwerk
- LDR Anpassungen auch für Phototransistor (umgekehrte Kennlinie)
- ntp_flag setzen, wenn das Jahr 1970 ist
- Assert für EEPROM Inhalt zu groß
- Anpassungen für RGB und GRB Leds (ist eher ein Vorschlag, nur die RGB Variante zu nutzen)
- Favicon
- Webserver nur für "/" (verhindert doppelte Übertragung)
- Zeige WiFi conncting phase auf den LEDs
- Vereinfachung für LED Layout 114 (LED_LAYOUT_REVERSE)
- Bugfix für das Radio Button Problem auf der Funktionsseite
- Bugfix in payloadTextHandling()
- Bugfix in set hostname (host-button -> hostname-button)
- SERNR 101 (geänderte Config Struktur)
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

dbambus, 2021-01-16:
Hey @ATho95,

das hört sich sehr sehr gut an, was du da vorschlägst und ich würde es sehr begrüßen, wenn du dem Projekt beiwohnst. Der "master" Branch ist bei mir ausschließlich für die finalen Releases da. Ich selbst entwickle aktiv im Branch "master_V2.6.0". Für genau dieses Release habe ich mir selbst vorgenommen mehr Layouts zu Supporten und Effekte zu integrieren. :-) Also genau das, was du ja schon gemacht hast.

Kommen wir also nun zum Code selbst. @tali hat schon sehr viel am Unterbau der Wordclock, insbesondere der Website und der Compiler Settings, gearbeitet. Diese Änderungen betreffen auch einige deiner Implementierungsvorschläge (geänderte Configstruktur, bugfix hostname, Wifi connect LEDs, ..) andere Punkte bleiben offen, worüber ich mich sehr freuen würde.

Ich selbst habe in der letzten Zeit viel am Uhrtype gearbeitet, um einerseits den Speicherverbrauch zu reduzieren und anderseits auch mehr Layouts zu unterstützen. Hier habe ich auch das UHR114_Reverse Layout angerührt, schau es dir einfach mal an :-).

Schau dir einfach mal den Entwicklungsbranch und die bisherigen Änderungen seit 2.5.1 an und "Give It a Go" :-) bin schon gespannt.

ATho95, 2021-01-18:
Das Mergen hat etwas gedauert, ein Hook passte gar nicht mehr.
Leider ist der Start der FW instabil geworden. Ich vermute, dass das ein out of memory Problem ist. Free heap ist 17808 Byte.
Die FW kommt oft nur bis zum Lauftext und kommt dann auf das hier. Manchmal kommt sie auch darüber und läuft dann.

Exception Cause: 28  [LoadProhibited: A load referenced a page mapped with an attribute that does not permit loads]

0x4023752e: pgm_read_byte_inlined at /home/earle/src/esp-quick-toolchain/repo/newlib/newlib/libc/sys/xtensa/sys/pgmspace.h:72
0x4023a70b: _svfprintf_r at /home/earle/src/esp-quick-toolchain/repo/newlib/newlib/libc/stdio/nano-vfprintf.c:667

dbambus, 2021-01-19:
Hey @ATho95,

kannst du den Code auf Github pushen ? Dann könnte ich nachschauen, wo die Fehler herkommen. Eventuell könnte man die Features sequenziell mergen, es dauert zwar etwas, aber so könnte man Fehlerquellen isolieren.

Hast du zuvor den ESP über das esptool.py komplett gelöscht ? Eventuell auch mal einen hard-reboot über das Abklemmen der Versorgungsspannung machen, nach dem flashen.

ATho95, 2021-01-19:
Ich bin ja ein Github Neuling und hatte so ein paar Probleme:
Line endings aus Github waren Windows like, das ZIP auf dem ich gearbeitet hatte ware Linux like. Ich hoffe beim committen wird das wieder gerade gebogen. Meine Änderungen sind unter @ATho95 branch master_V2_6_0 zu finden.
Die Abstürze von gestern sind nach dem kompletten Löschen des Flashs weg ???
Known Bugs:
- Minuten verschwinden bei Animationen
- Auto LDR funktioniert noch nicht

Wenn Du oder Ihr euch entscheidet, die Animation zu übernehmen, entfällt wahrscheinlich diese Transition in led_set() und ich könnte Änderungen für die known bugs machen. Mindestens der Minutenfehler hat damit zu tun, das show_minuten() in Word_array schreibt, aber Word_array_old an Neopixel übergeben wird.

Die Animation holt alles was es braucht aus Neopixel und schreibt auch wieder darein. Basierend auf den 4 Hooks:
	void begin();
	void loop(struct tm &tm);
	bool led_show_notify(bool flag, uint8_t minute);
	void demoMode(uint8_t &_minute, uint8_t _sekunde);

ATho95, 2021-01-20:
Ich kann die Abstürze jetzt reproduzieren. Bei den Einstellungen setze ich einen Haken bei Neustart - Ip Adresse anzeigen. Nach dem nächsten Reboot kommt er bis zur laufschrift("IP Adresse"). Vermutlich bekommt er da immer einen Interrupt vom IP-Stack und stürzt darin ab.
Das passiert auch in der originalen master_V2_6_0 FW, allerdings nur, wenn ich sie übersetzt habe. Das Release_2.6.0.bin File hat dieses Problem nicht.
Ich nutze die ESP8266 lib 2.7.4

dbambus, 2021-01-22:
Hey,

ich habe nun wieder etwas zeit gefunden und werde mir nun den Code genauer anschauen.

dbambus, 2021-01-23:
Hey @ATho95,

ich habe es im Wesentlichen zum Laufen gebracht, wichtig ist dabei allerdings, dass animation.begin(); nach der WLAN Init ausgeführt wird, da das Programm der WLAN.init über den WiFiManager sehr viel Ressourcen braucht. Deshalb habe Ich habe ich die .begin() nach der OTA Stage platziert, hier wird sie korrekt ausgeführt. Die Zeile mir dem anzeigen des WLAN Logos habe ich aaskommentiert, da sie nicht mehr nötig ist.

Ich werde in den kommenden Tagen einen Commit mit meinen Änderungen machen, da es noch den ein oder anderen Bug gibt, den ich noch fixen will.

Aber großes Lob, die Animation Class schaut wirklich gut gemacht aus. :-) Hier könnte man noch an der ein oder anderen Stelle optimieren, um doppelte Variablen zu vermeiden und den Speicherverbrauch reduzieren zu können.

Mit freundlichen Grüßen
David

ATho95, 2021-01-23:
Hallo David,

ich versuche jetzt einfach mal die Adresse aus der Notification.
Bezüglich Speicherverbrauch ist egal wo das animation.begin steht, da
mit dem #include die Klasse instanziiert wird. Ansonsten müsste man im
.begin() instanziieren.

Ich habe aber auch so meine Befürchtungen, dass die Animation auf den
"grossen" Uhren nicht so richtig läuft.

Speicher sparen kann man immer. Ich hatte z.B. ein uint8 wieder lang
gemacht weil der Compiler sagte, der Vergleich ist immer true.
Bei meinen Schwierigkeiten bin ich noch auf das uint8 s[5] gestossen. Da
werden in Zeile 696 in Wortuhr.ini 5 byte + '0' reingeschrieben.
sprintf(s, "rgb%d%d", i, ii);

Ich weiß inzwischen, dass ich nur noch Neopixel und ESP8266WiFi zusammen
binde muss und dann Illegal Instruction kriege. Der Bug muss in den Libs
liegen.
Eventuell liegt das am Stand 3.0.0-dev der ESP8266 SDK. Du hast wohl
eine Version 2.2.2-dev. Wie kommt man daran?
SDK 2.2.1 stürzte ja mit LoadProhibited ab.

Andreas

Am 23.01.2021 um 09:12 schrieb dbambus:
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

dbambus, 2021-01-24:
Hey,

also ich code mit CLion mit dem Platform.io Plugin. Hier kommt es beim Kompilieren zu diesem LOG:

```
Verbose mode can be enabled via `-v, --verbose` option
CONFIGURATION: https://docs.platformio.org/page/boards/espressif8266/nodemcuv2.html
PLATFORM: Espressif 8266 (2.6.2) > NodeMCU 1.0 (ESP-12E Module)
HARDWARE: ESP8266 80MHz, 80KB RAM, 4MB Flash
PACKAGES:
 - framework-arduinoespressif8266 3.20704.0 (2.7.4)
 - tool-esptool 1.413.0 (4.13)
 - tool-esptoolpy 1.20800.0 (2.8.0)
 - toolchain-xtensa 2.40802.200502 (4.8.2)
Converting Wortuhr.ino
LDF: Library Dependency Finder -> http://bit.ly/configure-pio-ldf
LDF Modes: Finder ~ chain, Compatibility ~ soft
```

mit meinem aktuellem Branch `master_V2.6.0` ist es aber noch etwas Buggy, aber es funktioniert.

ATho95, 2021-01-27:
Nachdem ich mich durch den konfusen Stacktrace und die vermeintlich alte SDK Version vollkommen auf dem Holzweg verirrt hatte. Ich habe "meinen" Bug gefunden. War aber auch nicht einfach, da er aus dem Time Callback asynchron auftaucht UND der zeitliche Ablauf UND die DHCP Einstellungen im Router eine Rolle spielen.
Meine Fritzbox übermittelt ihre eigene IP-Adresse als NTP Server. Das führt dazu, dass **sntp_getservername() NULL** liefert, die im printf die Exception auslöst.
Letztendlich kann das jeden treffen.

Ich guck mir die neue Struktur später noch an. Wenn ihr das folende schonmal in Wortuhr.ino merged könnte das so manchen Frust verhindern.
```C++
void time_is_set() {
    time_t utc = time(nullptr);
    if (externalRTC) {
        RTC.adjust(DateTime(utc));
    }
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
tali, 2021-01-27:
@ATho95 hilft #52 ?

ATho95, 2021-01-29:
> Was mir noch nicht so ganz gefällt, dass bei den Animationen sehr viele Variablen neu angelegt werden, die vorher schon global existierten.

Welche Variablen meinst du? Ich bin kein Freund von globalen Variablen, da sollte man schon genau hinsehen.

> Aber verstehe ich das richtig, dass es eigentlich nur Transitions zwischen den Uhrzeiten sind ? Also man hat vorher die alte Zeit und nach dem Effekt die neue Zeit ?

Ja, genau.
Die Info, dass sich etwas am Layout geändert hat wird mitgeteilt.
Wenn sich lediglich die Farben von Vorder- oder Hintergrund geändert haben ermittle ich das aus dem Neopixel Stripe. Das Layout könnte man genauso aus dem Stripe ermitteln aber in der alten Wortuhr gab es die Info schon. Das entkoppelt die Animation vollkommen von dem anderen Code. Man könnte also auch die Wetterdaten damit animieren.

Ich habe da noch ein Problem mit dem PR #56 den kann ich nicht als branch auswählen. beim #52  ging das noch. Muss der von euch freigegeben werden oder kann ich da was machen?

dbambus, 2021-01-29:
> Welche Variablen meinst du? Ich bin kein Freund von globalen Variablen, da sollte man schon genau hinsehen.

Ich würde mir gerne die Zeit nehmen den Code genau zu verstehen :-) Das wird etwas dauern, wenn man nur hier und da mal Zeit hat zu lesen. Mir ist halt nur aufgefallen, dass die Werte der alten Matrix, der kommenden und der Transitions doppelt vorhanden waren. Aber ich würde mein Fading Animation Code einfach in die Animation.hpp implementieren, dann sollte das wieder passen.

> Ja, genau.
> Die Info, dass sich etwas am Layout geändert hat wird mitgeteilt.
> Wenn sich lediglich die Farben von Vorder- oder Hintergrund geändert haben ermittle ich das aus dem Neopixel Stripe. Das Layout könnte man genauso aus dem Stripe ermitteln aber in der alten Wortuhr gab es die Info schon. Das entkoppelt die Animation vollkommen von dem anderen Code. Man könnte also auch die Wetterdaten damit animieren.

Hier müsste ich mir erstmal eine entsprechende Wordclock bauen, ebenfalls auch die 291er. :-), dann kann man das angehen.

> Ich habe da noch ein Problem mit dem PR #56 den kann ich nicht als branch auswählen. beim #52 ging das noch. Muss der von euch freigegeben werden oder kann ich da was machen?

PR #56 habe ich selbst noch nicht freigegeben, da es noch nicht fertig getestet ist. Deswegen ist er noch nicht verfügbar. Du kannst allerdings in meinem Fork in der `main` branch schauen. Das ist der Code.

Es wäre cool, wenn du dir mal de Effekte anschauen kannst. Wenn vorher nämlich keine Hintergrundfarbe eingestellt ist, dann wird beim auswählen der Effekte ein roter Hintergrund gesetzt.

ATho95, 2021-01-29:
> Es wäre cool, wenn du dir mal de Effekte anschauen kannst.

Ich habe jetzt deinen Code. Wenn du mit Effekten die Animation meinst, sehe ich nichts was rot wird.
Bei den Schiebeanimationen erscheint bei der nächsten Animation erst nochmal der vorherige Hintergrund. Da kann ich mal gucken.

ATho95, 2021-02-01:
Ich habe die Minuten LEDs mit in die Animation genommen und Änderungen an der Konfiguration von der Webpage aus werden sofort angezeigt.
Das Favicon habe ich auch gängig gemacht.
Für den Pull Request kämpfe ich im Augenblick mit dem github lint, da muss ich mein Eclipse noch anpassen.
Also bitte nichts an der Animation ändern.

dbambus, 2021-03-29:
Können wir dieses Issue schließen ?

ATho95, 2021-03-29:
erledigt

Closed 2021-03-29.

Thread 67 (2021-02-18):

Was mache ich falsch?

udo1toni, 2021-02-18:
Ich habe hier ein Problem.

Meine Schritte:
1. Wemos D1 Mini mittels ESP8266Flash.exe mit der aktuellen Version (2.5.1) bespielen. -> Reboot
2. AP Uhr anmelden und 192.168.4.1 aufrufen.
3. WLAN SSID und Passwort eintragen, speichern. -> Reboot (automatisch)
4. Mit der über den Router ermittelten IP verbinden, NTP Server eintragen, LEDStripe auf RGB änden. -> Poweroff
5. Mit Dem Ledstripe verbinden und Power up.
6. Die Punktmatrix zeigt korrekt die IP als Laufschrift an.
7. Die Uhrzeit wird für einen Sekundenbruchteil angezeigt, der Wemos bootet erneut. Nun wiederholen sich die Punkte 6 und 7 bis zum Powerdown.

Die Webschnittstelle ist ab Punkt 6 zu keiner Zeit erreichbar. Auch nach dem Abstecken vom LEDStripe bleibt der Zustand.
Einzig das Flashen mit einem leeren Image und anschließendes Neu Flashen führend wieder zu einem nutzbaren Chip. Es scheint, als wäre eine gewählte Einstellung dafür verantwortlich. Da ich beim ersten Mal den LED Typ nicht geändert hatte, neige ich zum NTP-Server... Mein NTP Server befindet sich im LAN, der Wemos darf sich nicht mit dem Internet verbinden. Ich nutze allerdings einen DNS Resolver, der die internen Adressen ebenfalls auflöst, in der Form ntpserver.meinlan.lokal.

Hat jemand Irgendwelche Ideen, was ich falsch mache?

Ich habe noch etwas weiter getestet, tatsächlich, sobald ich einen ntp Server eintrage (gleich ob DNS oder IP), hängt sich die Uhr immer wieder auf und startet sofort neu. Die Webschnittstelle ist zu keinem Zeitpunkt erreichbar.

Weiterhin habe ich es bis her nicht geschafft, den MQTT Client einzuschalten. Beim Speichern der Werte meldet die Seite kurz Offline, um dann immer stur den default Wert 192.168.4.1 als IP und den Zustand OFF zu melden.

dbambus, 2021-02-25:
Guten Tag,

entschuldige die späte Antwort, war aber im KurzUrlaub.

Ich nehme an, dass es sich um einen alten Bug handelt, der in der neueren Entwicklerversion behoben worden ist. Probieren Sie doch mal aus, den Flashspeicher zu löschen

`esptool.py --port COM5 erase_flash`

 und neu zu Flashen. Im Anschluss die Schritte erneut durchführen, jedoch nicht den Zeitserver einzustellen. Hier gab es früher mal einen Fehler, der zu dem beschriebenen Verhalten führen kann.

udo1toni, 2021-02-25:
Die Entwicklerversion muss ich vermutlich selbst bauen? Ist grundsätzlich kein Problem, ist nur etwas her, dass ich das letzte mal für Arduino & Co compiliert habe.
Der Zeitserver ist schon eine wichtige Funktion :) weil die Uhr keinen Zugriff auf das Internet bekommen soll. Mithin ginge die Anfrage auf den per default hinterlegten Server ins Leere. Je nach Modul kann die interne Uhr schon ordentlich zu schnell/langsam laufen, unsynchronisiert macht das also auf keinen Fall Spaß.
Und natürlich möchte ich auch mqtt nutzen :) das ist für mich der Hauptgrund umzudaten.

dbambus, 2021-02-26:
Hey,

ich werde versuchen in den Kommenden Tage die Version 2.6.0 Final zu machen. Hier habe ich mal unkompliziert die Binary für dich gebaut.

[firmware.bin.zip](https://github.com/ESPWortuhr/Wortuhr/files/6049216/firmware.bin.zip)

udo1toni, 2021-02-27:
Super, probiere ich morgen mal aus. Vielen Dank!

udo1toni, 2021-02-27:
So, ich habe die Datei ausprobiert, funktioniert super. Allerdings gibt es da doch noch en einen oder anderen Fehler...

- Die Anzeige "fünf nach halb" liefert derzeit nur "nach halb", das Wort "fünf" (für die Minuten) fehlt.

Unter Einstellungen:

- Status -> Verbinden führt zur Anzeige `Seite /? nicht gefunden`

- Zeitserver scheint nur mit IP zu funktionieren (aber vielleicht war ich auch nur zu ungeduldig...)

- Sprachoptionen -> Es fehlt eine Auswahl für "dreiviertel" statt "viertel vor". Das Design der Uhr gibt es her :) und speziell wenn es schon die Auswahl "viertel" statt "viertel nach" gibt, ist der Alternativtext "dreiviertel" zwingend.

Smart Home:

- Bei Auswahl "MQTT-Daten speichern" erscheint `Seite /?mqtt-state=1 nicht gefunden` - Nach Neuladen der Seite sind die Felder wieder leer und MQTT steht auf OFF.

- Im Zusammenhang mit Firefox **mobile** wird das Menü nicht aufgeklappt.

- In Safari fehlen im Animationsmenü mehrere Punkte (z.B. "Keine Animation"), andere Punkte sind doppelt angegeben (ich habe allerdings nicht ausprobiert, ob die jeweils gleichen Punkte evtl. zu unterschiedlichen Animationen führen). In Chrome klappt die Bedienung sauber.

- Die Auswahl des WLAN-Symbols beim Start führt zu einer dauerhaften Anzeige des Symbols. Erst das Umschalten (z.B. Farbwechsel und wieder zurück zu Uhrzeit) führt zur korrekten Anzeige der Uhrzeit. Sollen hier mehrere Optionen gleichzeitig aktiv sein können? zumindest die Auswahl des WLAN-Symbols hat alle anderen Haken wieder entfernt.

dbambus, 2021-03-01:
Hey @udo1toni,

vielen Dank für die ausführliche Fehlerbeschreibung.

> Die Anzeige "fünf nach halb" liefert derzeit nur "nach halb", das Wort "fünf" (für die Minuten) fehlt.

Dieses Issue habe ich soeben mit dem https://github.com/ESPWortuhr/Wortuhr/pull/65/commits/9cf7769c9fe8451864d7f4e7b9655141d73ff50e behoben.

> Status -> Verbinden führt zur Anzeige Seite /? nicht gefunden

@ATho95 Kannst du dich dieses Issues annehmen ?

> Zeitserver scheint nur mit IP zu funktionieren (aber vielleicht war ich auch nur zu ungeduldig...)

@tali Hast du vielleicht eine Idee, woran das liegen könnte ?

>
Sprachoptionen -> Es fehlt eine Auswahl für "dreiviertel" statt "viertel vor". Das Design der Uhr gibt es her :) und speziell wenn es schon die Auswahl "viertel" statt "viertel nach" gibt, ist der Alternativtext "dreiviertel" zwingend.

Dieses Issue bin ich auch mit https://github.com/ESPWortuhr/Wortuhr/pull/65/commits/7c234a275bf08d2fade82dd5a4b043d78de3205d angegangen und habe es behoben.

> Bei Auswahl "MQTT-Daten speichern" erscheint Seite /?mqtt-state=1 nicht gefunden - Nach Neuladen der Seite sind die Felder wieder leer und MQTT steht auf OFF.

Das werde ich mir genauer anschauen. :-)

> Die Auswahl des WLAN-Symbols beim Start führt zu einer dauerhaften Anzeige des Symbols. Erst das Umschalten (z.B. Farbwechsel und wieder zurück zu Uhrzeit) führt zur korrekten Anzeige der Uhrzeit. Sollen hier mehrere Optionen gleichzeitig aktiv sein können? zumindest die Auswahl des WLAN-Symbols hat alle anderen Haken wieder entfernt.

@ATho95 oder @tali, Kannst du dir das evtl auch anschauen ?

dbambus, 2021-03-01:
>Bei Auswahl "MQTT-Daten speichern" erscheint Seite /?mqtt-state=1 nicht gefunden - Nach Neuladen der Seite sind die Felder wieder leer und MQTT steht auf OFF.

Dieses Issue habe ich mit https://github.com/ESPWortuhr/Wortuhr/pull/65/commits/f24df8c382992d73d47d49ba64016a9cad9735df behoben. Hier sollte man allerdings erwähnen, dass die MQTT Funktionen in der Theorie funktionieren sollten, aber bisher noch nicht ausreichend getestet wurden. Hier erhoffe ich mir mal Feedback, werde aber selbst mal einen Server aufsetzten und mal testen (müssen).

Hier habe ich mal die aktuelle Version mit den neuen Änderungen erstellt.
[firmware.zip](https://github.com/ESPWortuhr/Wortuhr/files/6061338/firmware.zip)

ATho95, 2021-03-01:
>    Status -> Verbinden führt zur Anzeige Seite /? nicht gefunden
@ATho95 Kannst du dich dieses Issues annehmen ?

habe ich beseitigt, PR folgt

> Die Auswahl des WLAN-Symbols beim Start führt zu einer dauerhaften Anzeige des Symbols.
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
ATho95, 2021-03-01:
@udo1toni, zum ursprünglichen Problem mit den endlos restarts.
Da gab es mal einen Fehler in time_is_set(). Wenn du da ab "String origin" alles bis zum Ende der Funktion auskommentierst, könnte man ein ähnliches Problem schonmal ausschließen.

Ansonsten würde ich den Stacktrace analysieren.
Ob das wie hier erklärt funktioniert weiß ich nicht, da ich Eclipse nutze.
https://arduino-esp8266.readthedocs.io/en/latest/Troubleshooting/stack_dump.html

Aus der Kommandozeile geht es auf jeden Fall. Das Ergebnis ist allerdings manchmal sehr schwierig zu interpretieren.
java -jar EspStackTraceDecoder.jar C:\Users\Andreas\git\arduino-esp32\tools\xtensa-esp32-elf\bin\xtensa-esp32-elf-addr2line.exe ..\ESP8266_Wortuhr\Release\ESP8266_Wortuhr.elf stack.txt
In stack.txt steht dann natürlich der stack trace

udo1toni, 2021-03-02:
Puh, ich bin ja eher dummer Endanwender ;) so ein paar kleine Sachen zusammenzimmern hab ich schon mal hinbekommen, dies hier ist definitiv außerhalb meiner Skills ;)
Als NTP Server hatte ich meinen OpnSense Router eingetragen, da das IoT WLAN keinerlei Zugriff auf das Internet hat (aus Gründen...) Der OpnSense liefert die Uhrzeit auch recht zuverlässig aus, im IoT WLAN habe ich ca. 20 Teilnehmer, die größtenteils mit Tasmota 8.5.2 laufen, da gab es bisher noch nie Probleme.  Mit der aktuellen Firmware (sowohl die vom 27. als auch die von gestern) tritt der zyklische Neustart nicht mehr auf

Wie schon erwähnt, kann es gut sein, dass ich bei der Nutzung des fqdn im NTP Server Feld einfach etwas ungeduldig war, mit der IP funktioniert es jedenfalls zuverlässig.

Ansonsten bin ich mit dem Stand jetzt schon sehr happy. Die Auswahl für die Sprachvariante "viertel vor" bzw. "dreiviertel" steht allerdings nach wie vor nicht zur Verfügung. Den Sourcecode habe ich noch nicht verstanden ;) aber wegen der Änderungen im Code, als Uhrenvariante habe ich "Uhr 114" ausgewählt. Das funktioniert auch soweit korrekt. Kann es daran liegen, dass die entsprechende Auswahl nicht erscheint?

Was mir noch aufgefallen ist: Es gibt ja die Option, die Helligkeit abhängig von der Uhrzeit zu steuern. Das funktioniert bei mir irgendwie nicht. In der Uhr ist kein LDR verbaut, und da ich die Uhr nicht selbst gebaut habe, möchte ich hier nur sehr ungern eingreifen (es gäbe auch gar keine Stelle, wo ich den Sensor unauffällig platzieren könnte).
Nun gibt es ja drei Felder, die sich mit der Displayhelligkeit beschäftigen (Helligkeit, Automatische Helligkeit und Einstellung des LDR). Liegt es also vielleicht einfach daran, dass ich nur einen Fehler bei der Einstellung habe? Ich hatte nur unter Helligkeit für die entsprechende Uhrzeit den Prozentwert eingetragen, das hatte aber auch nach mehreren Minuten keine Auswirkung, Oder wird die Helligkeit nur exakt zum angegebenen Zeitpunkt gesetzt, aber nicht, wenn man den Parameter ändert?

Die Aktivierung von MQTT klappt leider auch noch nicht, zwar kommt nun keine Fehlermeldung mehr, aber nach dem Neuladen der Seite sind die eingetragenen Daten (Serveradresse, Port und auch Zustand des Schalters) wieder leer bzw. OFF.

ATho95, 2021-03-02:
> Was mir noch aufgefallen ist: Es gibt ja die Option, die Helligkeit abhängig von der Uhrzeit zu steuern. ...

Die zeitabhängigen Werte werden mit jedem Minutenwechsel übernommen. Aber nur, wenn Auto-Helligkeit "an" oder LDR-Steuerung "aus" ist.
@dbambus, ich habe gerade mit den Auto-Werten gespielt. Wenn beide Parameter gleich sind, gibt's Division durch 0. Ich packe die Änderung noch in den letzten PR.
Und die LDR-Steuerung kann ausgebaut werden. Dazu solltest du die Autohelligkeit mal testen. ich habe einen Fototransistor verbaut. Der hat eine umgekehrte Kennlinie zum LDR. D.h. mit der LDR-Steuerung ist meine Uhr im Dunkeln hell.
Ich könnte das übernehmen.

udo1toni, 2021-03-03:
Was macht denn die Autohelligkeit genau, ist das ein Teil von LDR?

ATho95, 2021-03-03:
Im Prinzip machen beide das gleiche, wobei die Autohelligkeit flexibler ist. Deshalb könnte die LDR Steuerung entfernt werden.
Entscheidend für die Helligkeit der LEDs ist ja die Eingangsspannung am ESP. Die kann, je nach Beschaltung, im Dunklen höher oder niedriger als im Hellen sein.
Ich habe die Uhr damals gebaut und erst danach eine Software gesucht. Da hatte ich schon einen Fototransistor statt LDR verbaut und die LDR Steuerung funktionierte damit verkehrt herum. Im Dunklen waren die LEDs am hellsten.

Closed 2021-03-29.

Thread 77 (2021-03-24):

Kein Zugriff auf Webinterface

Opferwurst87, 2021-03-24:
Grüße,

ich habe vorhin das Update auf 2.6.0 durchgeführt und komme seitdem nicht mehr über die IP-Adresse auf die Weboberfläche zum Konfigurieren. Mit der Version 2.5.1 war noch alles ok. Als erstes habe ich das Update über die IP-Adresse:81/update hochgeladen und im nächsten Versuch die .bin nochmal manuell über USB-Schnittstelle aufgespielt.

Nach dem flashen via USB kam dann immerhin das WLAN "Wortuhr_verbinden" oder so ähnlich. Gesagt, getan. Die Konfig öffnet sich und ich kann dort meine WLAN Daten eintragen (auch die Erase-Funktion habe ich probiert). Dannach scheint alles i.O. jedoch kann ich weiterhin nicht drauf zugreifen.

Hier der Auszug aus dem seriellen Monitor der Arduino IDE nach erfolgreicher Konfig (WLAN-Kennwort entfernt).

`Begin Setup
--------------------------------------
--------------------------------------
ESP Uhr
Version         : 2.6.0
Chip ID         : 00BF92FF
Flash ID        : 00164020

CPU Speed       : 80 MHz

Flash real Size : 4096 KByte
Flash ide  Size : 4096 KByte
Flash ide Speed : 40000000

Free Heap Size  : 26464 Byte
Sketch Size     : 594432 Byte
Free Sketch Size: 2547712 Byte

SDK Version     : 2.2.2-dev(38a443e)
RESET Info      : External System
COMPILED        : Mar 24 2021 08:59:29
LED Init
No external RealtimeClock found
*WM: [1] AutoConnect
*WM: [3] setupHostname:  uhr
*WM: [2] Setting WiFi hostname
*WM: [2] Connecting as wifi client...
*WM: [3] STA static IP:
*WM: [2] setSTAConfig static ip not set, skipping
*WM: [1] Connecting to SAVED AP: FRITZ!Box 7490
*WM: [3] Using Password: "Kennwort"
*WM: [3] WiFi_enableSTA enable
*WM: [3] enableSTA PERSISTENT ON
*WM: [3] Mode after delay:  STA+AP
*WM: [1] connectTimeout not set, ESP waitForConnectResult...
no RTC clock - disable SNTP startup delay
*WM: [2] Connection result: WL_CONNECTED
*WM: [1] AutoConnect: SUCCESS
*WM: [1] STA IP Address: 192.168.178.21
*WM: [3] hostname: STA:  uhr
Mode: STA+AP
PHY mode: N
Channel: 9
AP id: 0
Status: 5
Auto connect: 1
SSID (14): FRITZ!Box 7490
Passphrase (18): "Kennwort"
BSSID set: 0
Signal strength: 100

-- Begin WlanStart --
IP:192.168.178.21

-- Ende  WlanStart --

Websockest started
--------------------------------------
Ende Setup
--------------------------------------

Set new time: 23:45:22 (europe.pool.ntp.org)
1970-01-01 01:00:04 (+0100)
2021-03-24 23:45:23 (+0100)
...`

Die IP-Adresse 192.168.178.21 lässt sich auch nicht anpingen. In der Fritzbox wird mir das Gerät angezeigt (Reboot usw. durchgeführt). Jedoch ist es nach gewisser Zeit auch dort nicht mehr in der Geräteliste der verbundenen Geräte aufgeführt.
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

Im WirelessNetworkWatcher von Nirsoft wird mir das Gerät jedoch nicht angezeigt - alle anderen Geräte im Netzwerk schon
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

Die Uhrzeit läuft übrigens korrekt - nur auf dem falschen Layout, was ich gerne einstellen würde.

Jemand eine Idee, wo der Hund begraben ist?

ATho95, 2021-03-27:
Ich würde dir raten, einen Paketmitschnitt aus der Fritzbox heraus zu machen.
[http://fritz.box/html/capture.html](url)
Neben "wlan" den **Start** Button drücken. Es wird nach einem Filenamen auf dem PC gefragt. Wenn man einige Daten gesammelt hat, drückt man auf den **Stop** Button. Das File kann mit Wireshark analysiert werden.
Wenn du dich mit Netzwerken nicht so auskennst, kannst du mir den Trace auch schicken.

Das Layout kannst du unter den Einstellungen ändern.

Opferwurst87, 2021-03-28:
Moin, im Anhang ein kurzer Mitschnitt nach dem Herstellen der Stromversorung der Uhr. Wäre cool, wenn du es dir anschauen könntest. Die Auswertung in Wireshark sagt mir nämlich nichts.

[iad-if-wlan_28.03.21_1521.zip](https://github.com/ESPWortuhr/Wortuhr/files/6217373/iad-if-wlan_28.03.21_1521.zip)

ATho95, 2021-03-28:
Deine Fritzbox gibt dem ESP keine IP Addresse. (Stichwort DHCP)
Der ESP nimmt sich einfach die 192.168.178.21. Es kommt von der Fritzbox auch die Frage: Wer hat die 192.168.178.21 , die der ESP auch beantwortet.
Als nächstes guckst du mal in der Fritzbox, ob der DHCP Bereich für die Vergabe von IP Addressen groß genug ist.
Das ist etwas versteckt unter: Heimnetz -> Netzwerk -> Tab Netzwerkeinstellungen -> weitere Einstellungen -> IPv4-Konfiguration: DHCP-Server vergibt IPv4-Adressen von ... bis ...
Und kontrollier mal, ob die .21 schon an andere Geräte vergeben wurde.

Opferwurst87, 2021-03-28:
Grüße,
also die .21 taucht nur in Verbindung mit dem ESP auf. Der DHCP in der FritzBox steht auf .20 - .200 - wobei die .20, .22 und .23 bereits vergeben sind.
Im Ergeignislog der FB erscheint nach der WLAN Konfig des ESP ein Eintrag für die Anmeldung, nach 30sek ein Eintrag für die Abmeldung. Teilweise erscheint auch der Hinweis, der WLAN-Key sei falsch. Den hab ich jedoch 100% richtig eingebenen. Auch mit deaktivierter Verschlüsselung kommen die Hinweise mit der an- und abmeldung.
Den dazwischengeschalteten FritzRepeater hab ich auch bereits vom Strom genommen und das alles ohne den Repeater versucht.
Alle inaktiven Geräte hab ich aus der Geräteliste entfernt (auch den ESP mit der .21) Im nächsten Versuch ist das Ding jedoch wieder mit der .21 "verbunden".
Mit der Version 2.5.1 hab er noch die .78 bezogen.

Wird denn der ESP mit dem Neuaufspielen einer .bin kompett resettet oder muss man da was anderes machen?

Ich glaube eher weniger, dass es mit der FB zu tun hat, werde es jedoch m Wochenende mit einem anderen Router ausprobieren können.

ATho95, 2021-03-29:
Wenn dein WLAN Passwort falsch wäre, sähe man im Trace den Versuch eine IP Addresse zu bekommen nicht.
Es gibt einen kleinen Unterschied zwischen deinem und meinem ESP im ersten DHCP Protokoll Paket. Eventuell hat der WiFiManager sich da was gemerkt, das du nur über ein komplettes Löschen des Flash weg bekommst.
esptool.py erase_flash
Oder aus Arduino heraus: Werkzeuge -> Erase Flash -> All Flash Contents

Opferwurst87, 2021-03-29:
Ich habe mal den DHCP Bereich der FB auf .30 - .200 geändert. Nach der Neueinrichtung des ESP, bezieht er die 192.168.178.30, aber auch darüber bekomme ich keinen Zugriff.
Dann hab ich versuch am Smartphone einen Hotspot einzurichten. Ich hab den ESP dann damit verbunden - er bezieht dann die Adresse 192.168.122.213 - auch hier kein Zugriff über die IP Adresse auf die Konfig.
In der Arduino IDE hab ich es auf "Alle Flash Contents" umgestellt - damit das funktioniert muss ich dann was tun? Ein beliebiges Image aufspielen? So hab ich es zumindest jetzt versucht - alles ohne Erfolg.

Später werde ich es ggf. mal mit esptool.py probieren.

ATho95, 2021-03-29:
Ich habe mir den kleinen Unterschied (Bootp flags: 0x8000, Broadcast flag (Broadcast)) mal genauer angesehen. Dieses Flag sorgt u.a. dafür, dass die DHCP Antworten von der FB als Broadcast gesendet werden. Da ich einen Filter benutzt habe, der nur Pakete von/an deine MAC Adresse sichtbar macht, hatte ich die Broadcasts nicht gesehen. Die IP Addressvergabe läuft also doch, da muss ich meine obige Aussage zurücknehmen.
Ich gucke Morgen mal weiter.

ATho95, 2021-03-30:
Ich dachte, dass ich über den Vergleich mit meiner Uhr noch etwas herausfinde. Ich sehe bei mir keine MDNS Pakete. Bei dir werden diese Pakete relativ häufig gesendet.
Ohne MDNS funktioniert bei mir das Ansprechen über den Hostnamen auch nicht mehr. Nutze ich eh nicht, darum habe ich auch nicht gemerkt seid wann das nicht mehr geht.
Wenn du mal ein von mir übersetztes Binary ausprobieren möchtest, hänge ich hier gern mal eins an.

Ansonsten fällt mir dazu nichts mehr ein.

Ich habe einige ESPs (32 und 8266) im Dauereinsatz. Die waren nach Monaten auch nicht mehr erreichbar. In der FB war auch nur noch zu sehen, dass sie abgemeldet wurden. Ich habe damals ein ping auf meine FB eingebaut. Wenn der mit Fehlern zurückkam booten die ESPs neu. Das hilft bei dir nicht, aber es zeigt, dass es da wohl noch Probleme gibt.

Opferwurst87, 2021-03-30:
Hey danke für die Mühe, ich probiere gerne dein Binary aus, vielleicht funktioniert es ja! Zur Not spiel ich mir halt einfach wieder die Version 2.5.1 auf.

ATho95, 2021-03-30:
Na dann versuchs mal hiermit:
[ESP8266_Wortuhr.zip](https://github.com/ESPWortuhr/Wortuhr/files/6231917/ESP8266_Wortuhr.zip)

Ich habe übrigens auch die FB 7490

Opferwurst87, 2021-03-30:
Hey, habs probiert, jedoch ist es das gleiche Fehlerbild...

Opferwurst87, 2021-04-03:
Grüße, ich habe nun eine komplett anderen ESP mit 2.6.0 bespielt und mit einem anderen Router (Speedport W724V) verbunden. Auch hier das gleiche Problem. Wird im Log angezeigt, dass das Gerät verbunden ist und kurze Zeit später, ist es wieder raus. Einfach kein Zugriff auf das Webinterface. Bei dem ESP war auch vorher die Version 2.5.1 drauf.

Kein Plan mehr, was ich sonst noch probieren kann.

ATho95, 2021-04-03:
Nur so eine Idee. Es könnte an der Versorgungsspannung (Netzteil und/oder Kabel) liegen wenn der WiFiManager vielleicht an der Sendeleistung dreht.

Opferwurst87, 2021-04-03:
Hmmm, sollte das dann nicht über den seriellen Monitor zu sehen sein?
Ich habe jetzt nochmal einen jungfräulichen ESP genommen und mit dem ESP flasher die Version 2.6.0 aufgespielt. Diesen dann auch nur über den USB Port von PC betrieben und nicht wie bei den anderen beiden über das 5V Netzteil. Wobei, soweit ich weiß wird der USB Port auch mit einer 5V Ausgangsspannung betrieben, oder? Wie dem auch sei... gleiches Problem.

dbambus, 2021-05-11:
Hat sich das Problem mittlerweile lösen können ?

Opferwurst87, 2021-05-12:
Ja, indem ich weiterhin 2.5.1 nutze. Alles andere funktioniert einfach nicht. Vielleicht liegt es auch an der Art und Weise des aufspielens der BIN. Gibt's noch ne andere Möglichkeit als der ESP flasher? Mit der arduino IDE konnte ich die 2.6.0 auch nicht kompilieren. Zuviele Fehlermeldungen mit denen ich nichts anfangen kann.

dbambus, 2021-05-12:
Du kannst es über ein OTA Update versuchen. <IP-Adresse der Wortuhr>:81 hier wäre ein Webupdater hinterlegt. In welchem du eine Binary hochladen kannst.

Du kannst dabei diese Version verwenden. Hier habe ich einzig die Seriennummer geändert, sodass der EEPROM mit neuen Werten überschreiben wird.

[2.6.0.zip](https://github.com/ESPWortuhr/Wortuhr/files/6466191/2.6.0.zip)

ATho95, 2021-05-12:
In der Arduino IDE kann man unter Werkzeuge -> Flash Erase: "Scetch + WiFi Settings" einstellen. Das würde ich mal probieren.
Wenn die 2.6.0 nicht kompiliert kannst das nicht benutzen sondern musst von Hand das esptool aufrufen.
Das müsste sinngemäß etwa so aussehen:
C:\Users\Andreas\AppData\Local\Arduino15\packages\esp8266\tools\python3\3.7.2-post1/python3 C:\Users\Andreas\AppData\Local\Arduino15\packages\esp8266\hardware\esp8266\2.7.4/tools/upload.py --chip esp8266 --port COM6 --baud 3000000 **erase_region 0x3FC000 0x4000** --before default_reset --after hard_reset write_flash 0x0 C:\Users\Andreas\AppData\Local\Temp\arduino_build_337571/ESP_Telnet.ino.bin
Wie die Pfade bei dir gesetzt sind kannst du im IDE Status Fenster sehen wenn du die 2.5.1 flash'st

Opferwurst87, 2021-05-20:
Ich werde es demnächst nochmal über die OTA Funktion versuchen. Beim ersten Mal hatte ich damit auch keinen Erfolg. Vielleicht klappt es mit der geänderten Variante.

Das mit Flash Erase: "Scetch + WiFi Settings" habe ich bereits probiert, aber auch hier ohne Erfolg.
Die letzte Option werde ich bei Bedarf auch nochmal testen. Ich melde mich dann, habe nur aktuell keine Zeit dafür.
Danke für eure Hilfe!

Closed 2021-06-02.

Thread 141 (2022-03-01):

Dutch

pienmatla, 2022-03-01:
First: i am a noob at programming but i really want to learn.

Question: If i send you a complete clockface in dutch (with translation etc) can someone change the code for me so it corresponds with the right words?

Also is there a step by step description of how to make this clock? Thanks

dbambus, 2022-03-01:
Hey @pienmatla,

how good is your German ?

It is pretty easy to add a new language. You just have to add a new Uhrtype. For example copy this [.hpp file](https://github.com/ESPWortuhr/Wortuhr/blob/main/include/Uhrtypes/uhr_func_114_Alternative.hpp
) and apply changes for your language. If you've done right, that should be it (90% sure), you can then upload the file to a private fork and test it.

If you still got problems with the header file, I can set up a private zoom conference to tell you more about the code, if you want.

Cheers David

pienmatla, 2022-03-01:
Thanks for your respond.

My German is not really good but good enough to understand the time. The only thing is: in German you say es ist zwanzig nach eins. In Dutch you say "het is tien voor half twee" (es ist zehn vor halb zwei).

Do you have any clue how to fix that?

Kind Regards,
Pien

dbambus, 2022-03-01:
Hey @pienmatla,

Maybe this is a helping guide for you :-)

https://gerben.algemeenbekend.nl/wordclock/images/

Just try to apply your changes as far as you can, I can help afterwards.

Cheers
David

pienmatla, 2022-03-01:
Thank you @dbambus!

Is there a way I can contact you? By mail or something. I will send you some questions. I have made a clockface and am wondering if the ideas i have are realistic 😀

dbambus, 2022-03-01:
Hey @pienmatla,

may be I ve just send you an email. Can you check ?

Cheers
David

pienmatla, 2022-03-01:
Hey David,

Pic 1: clockface
Het = es
Is = ist
Vijf = funf
Tien = zehn
Drie = drei
kwart = viertel
over = nach
voor = vor
half = halb
twaalf = zwolf
twee = zwei
een = eins
zeven = sieben
drie = drei
vijf = funf
elf = elf
acht = acht
vier = vier
negen = neun
tien = zehn
zes = sechs
uur = uhr

Pic 2: the led strips. I will solder them so they are connected

Pic 3: the frame i put on top of the leds

This is what i have so far. I also have an Nodemcu V3. I am struggling how to connect the leds to the nodemcu and with the programming. Like i said, zwanzig nach .. needs to be zehn vor halb ..  ( tien voor half ..).

I can put the right led addresses in the code but changing the twenty to what it needs to be seems difficult to me. I also dont want to have the 4 leds that will show minutes. I use 110 leds as u see in the pictures.

Can you show me how to connect the wires of the led to the nodemcu and how to fix the code? :)

Kind regards,
Pien

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

pienmatla, 2022-03-01:
Hi @dbambus,

I got your message and sent u a reply. Thank you very much!

dbambus, 2022-03-02:
Hey @pienmatla,

I added the dutch translation for the layout only in a ned branch https://github.com/dbambus/Wortuhr/tree/main_dutch_added feel free to test it :-)

David

Closed 2022-04-19.

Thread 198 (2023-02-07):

Matrix hinzufügen

n3roGit, 2023-02-07:
Hallo zusammen,

es wäre super wenn ihr die angehängte Matrixdatei im Repo hinzufügen könntet. Leider hat meine Wortuhr das Layout von "uhr" um ein Zeichen verschoben. bei mir steht dort dann immer "luh". Also muss ich bei jedem Update erst das Projekt kompilieren und dabei meistens vorher alle Komponenten aktualisieren.

Es muss lediglich in der Datei DE10x11.hpp der folgende Abschnitt angepasst werden:
`
case FrontWord::uhr:
            setLetter(LED_MAP(99));
            setLetter(LED_MAP(100));
            setLetter(LED_MAP(101));
            break;
`

dbambus, 2023-02-07:
Hallo @n3roGit,

ich kann das machen. Wie soll dieser Typ genannt werden ? bspw. DE10x11.Nero

Ist an dem Buchstaben Layout noch irgendwas anders bzw. brauchst du die defs für REVERSE nicht?
Wenn ja, kannst du dann die komplette .hpp hier hinzufügen ? Der Upload geht nur als .txt Datei, dass kann ich dann aber abändern.

Voraussichtlich kommt das in ein Bugfix Release 2.7.1

n3roGit, 2023-02-07:
Ui das ging ja Flott!!
Da ich kein Entwickler bin weiß ich nicht was du mit dem Reverse meinst. Ich hatte nach dem Bau der Uhr mich dran gemacht und diese Stelle angepasst, da nur das Wort "Uhr" bei meinem Layout anders ist. Wenn es hier Abhängigkeiten gibt wäre ich für die entsprechenden Anpassungen natürlich sehr dankbar!

Als Namen würde ich DE10x11.LUH vorschlagen. Wenn jemand mal das selbe Problem hat, wird er dann leicht auf das angepasste Profil stoßen :)

dbambus, 2023-02-07:
Hallo @n3roGit,

Okay, dann mach ich das fix. Wie ist denn das Buchstaben layout ? Bzw. kannst du kontrollieren, ob alle Buchstaben so passen ?

```
/*
 * Layout Front
 *
 * E S K I S T R F Ü N F
 * Z E H N Z W A N Z I G
 * D R E I V I E R T E L
 * T G N A C H V O R U M
 * H A L B G Z W Ö L F J
 * Z W E I N S I E B E N
 * K D R E I R H F Ü N F
 * E L F N E U N V I E R
 * N A C H T Z E H N B X
 * U S E C H S U H R Y F
 */
```

n3roGit, 2023-02-07:
nicht ganz.

/*
 * Layout Front
 *
 * E S J I S T L F Ü N F
 * Z E H N Z W A N Z I G
 * D R E I V I E R T E L
 * T F N A C H V O R J M
 * H A L B X Z W Ö L F T
 * Z W E I N S I E B E N
 * L D R E I C I F Ü N F
 * E L F N E U N V I E R
 * U A C H T Z E H N S I
 * C S E C H S T L U H R
 */

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

dbambus, 2023-02-22:
Vielen Dank @n3roGit

Ich habe dein Layout mit https://github.com/dbambus/Wortuhr/commit/e4776b343f800389eabb2f8051825078a7284a44 hinzugefügt. Damit wurde es im nächsten Release enthalten sein.

Mit freundlichen Grüßen
David

n3roGit, 2023-02-23:
@dbambus ich habe zu danken! =)

Closed 2023-02-22.

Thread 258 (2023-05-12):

LED-Strip "von hinten" ansteuern

huckes, 2023-05-12:
Hallo,
Ein tolles Projekt und eine schöne Implementierung des Wortuhr Prinzips !!
Ich baue gerade eine Uhr 11x10 (ca. 40x50cm) mit 4 Minuten LEDs in der unteren Zeile. Aus Platzgründen kommt der ESP8266 neben diese Minuten-LEDs. Die Datenleitung zur ersten LED links oben ist daher recht weit, was eigentlich nicht empfohlen wird. Es wäre schön, wenn man den LED-Streifen genau anders herum einbauen könnte, und die Daten am letzten Minuten-Punkt eingespeist werden. Dann musste aber die Neopixel-Matrix umgedreht gefüllt werden. Könnte man jetzt direkt im Code "reinwürgen", aber das ist keine gute Lösung.
Daher wäre neben den Optionen vertikal und horizontal speigeln noch eine weitere Auswahl wünschenswert, die die Daten ausgehend von der letzten Minuten-LED einfüllt.

Viele Grüße aus Mittelfranken,
Hans

dbambus, 2023-05-12:
Hallo Hans,

vielen Dank für die Lorbeeren :-).

Ich musste ein wenig über dein Problem nachdenken. Es gibt also in der Tat keine triviale Lösung (mehr), um einfach die Laufrichtung der LEDs samt Minuten zu ändern.
Was es aber gibt und bereits implementiert ist, wäre eine Änderung der Laufrichtung der Frontmatrix selbst. Die Minuten-LEDs müssen dabei immer an der letzten Position stehen.
Sprich man kann die Uhr "unten rechts" einspeisen, aber sie muss direkt mit der Frontmatrix beginnen und dann müssen die 4 LEDs angeschlossen werden. Dann kann man online oder in der config.h horizontal und vertikal spiegeln, um die Wordclock benutzbar zu bekommen.

Mit freundlichen Grüßen
David

huckes, 2023-05-12:
Hallo David,
vielen Dank für die schnelle Antwort.
Ohne Minuten-LEDs wäre das die Lösung. Aber mit den Minuten-LEDs bleibt 'ne lange Leitung dann weiterhin in der Verdrahtung. Oder die Minuten-LEDs werden über die erste Zeile positioniert. Mein Blech ist schon gelasert, also evtl. was für zukünftige Aufbauten.
Ich habe jetzt mal einen kleinen Testaufbau mit dem zu verwendeten LED-Streifen und dem Adafruit Strandtest gemacht:
Aufbau 1: erste WS2812 über 220Ohm direkt an den Datenausgang.
Aufbau 2: den Datenausgang über einen Diode und pull-up Widerstand 1kOhm nach +5V geschaltet und die erste WS2812 dann mit 220Ohm zwischen Diode und pull-up. Damit wird der Datenpegel für die WS2812 auf 5V-high und ca. 1V low verschoben.
Nun die Datenleitung (einadriges Dupont-Kabel) verlängert: bei 1,5 m Störungen in beiden Aufbauten; bei 1m Störungen nur bei Aufbau 2 und wenn ich am Kabel rumwackle; bei 0,5m keine Störungen. Damit sollten die 0,5m, die ich brauche vom ESP nach "oben links" kein Problem werden (mit beiden Testaufbauten, ich werde den 1. verwenden). Notfalls werde ich dazu ein abgeschirmtes Kabel nehmen.
Das Ergebnis kann man allerdings nicht verallgemeinern: Je nach LED-Strip kann der High-Pegel von 3,3V nicht ausreichen und auch die "lange Leistung" kann bei anderen Komponenten Probleme machen. Also im Einzelfall selbst ausprobieren.
Nochmals vielen Dank für den Lösungsansatz. Ich mach' den Issue dann mal wieder zu.

Grüße, Hans

Closed 2023-05-12.

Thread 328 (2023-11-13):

Port to ESP32

merlin2533, 2023-11-13:
For more Power on HTML side?
More flexible to it?

dbambus, 2023-11-13:
Hello @merlin2533,

so far it has not been requested and I would like to continue supporting the ESP8266. I think it is possible to port the code within a few hours, but I don't have a timeline when. It should be a solution where most of the code is the same to have some kind of base and only change the platform.

Cheers David

merlin2533, 2023-11-13:
We have the problem that is so slow loading the webpage that it need 25minutes somtetimes it crashes

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

dbambus, 2023-11-14:
I noticed yesterday as well. I'll have a look into that. Ist wasn't so some months ago. Maybe something changed in the W
ifiManager Lib.

merlin2533, 2023-11-14:
Loading of Page need 25min, do you have an idea to solve it?

dbambus, 2023-11-20:
Can you test an older release directly from the Binary provided, a Version like V3.0, if the problem still occurs ?

I guess it is a problem with the WiFi manager build we are using right now.

merlin2533, 2023-11-20:
2.8 ist working but older not

Gesendet von Outlook für Android<https://aka.ms/AAb9ysg>
________________________________
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

dbambus, 2023-11-20:
Okay,

i will investigate further, but this is an interesting hint.

Thanks @merlin2533

merlin2533, 2023-11-20:
When you need help, let me know
Otherwise or a testobject i have a cnc here with plasma and wood

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

dbambus, 2023-12-03:
Hello @merlin2533,

Could you test the current version in the main branch? I have made some changes, including using a specific build ( 2.0.16-rc2) of the WiFiManager library. I have a strong suspicion that recent changes in it are causing the connection to timeout. That's why I fall back to the latest stable version.
In my test setup, everything has worked so far.

Cheers
David

merlin2533, 2023-12-22:
Have you found a potion to port it? or why it happen?

nikolai2111, 2024-09-11:
Hello everyone,

What is the current status?

I would be very interested in porting to the ESP32 boards. Since I am currently planning to create a board that should also have a certain cross-compatibility and should be available for hobbyists easily and for a long time (e.g. order online, assembled or just as a board). The data sheet of the ESP8266 recommends using a ‘newer’ chip, the ‘long-term commitment’ from Espressif states the EOL for the ESP8622 as sometime in 2029, the replacement board, which is specified in the data sheet as a replacement, is not specified, so the EOL is unknown. Therefore, I would rather focus on the newer boards. As far as I understand it, porting would also mean that many more different ESPs (C, S & H series) could be used, as the code would be easily interchangeable between the new ESP32s (adaptation of platformio.ini).

I have already tried this myself. However, I failed due to a lack of knowledge and experience with the ESPs, as certain functions would have to be rewritten in some cases.

However, before I can design this circuit board, I would like to create a breadboard prototype. Is it possible to discuss the priority of the issue? Especially if you say it can be done in a few hours, I would be very interested. I could also help you with the hardware tests as I bought some ESP DevKits for this project (ESP32-C3 / C6 & S3).

What do you think?

dbambus, 2024-09-14:
Hey,

in short, I tried yesterday some adjustments for ESP32 and I was able to build it :-) here is a Version, which should work, as a alpha. Can you test it at first ?

LED Pin is preconfigured to PIN 2

[V3.3_Dev_ESP32.zip](https://github.com/user-attachments/files/17001614/V3.3_Dev_ESP32.zip)

I will make the branch available anytime soon.

Mit freundlichen Grüßen
David

merlin2533, 2024-09-14:
I will do a test in the next days

Gesendet von Outlook für Android<https://aka.ms/AAb9ysg>
________________________________
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

nikolai2111, 2024-09-15:
Thank you very much for your quick response!

I tried it today, unfortunately without success. I failed to flash it (I have never done it with the .bin files).
I would welcome a branch to upload everything via PIO. That way I can also test the code on several new ESP32s (C3, C6 & S3).

dbambus, 2024-10-18:
Done with the latest Release https://github.com/ESPWortuhr/Multilayout-ESP-Wordclock/releases/tag/V4.0.0

nikolai2111, 2024-10-19:
@dbambus, great job! I'm currently playing around with the new release, very nice Job!
I also have seen that you are using LaTeX for the documentation, another very nice step forward!

I'm currently designing a PCB and which I want to contribute to this repo as a pull request, but this can take a littebit of time.

As I have seen from the code and to mention it for the community I figured out that the periphery is connected to the following pins (of the ESP32):
- A0: LDR
- D21 & D22: I2C for the BH1750 (maybe also the RTC?)
- D27: for the LED stripes

Closed 2024-10-18.

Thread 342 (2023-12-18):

Wifi Manager settings reset

irqnet, 2023-12-18:
Ist es möglich die Einstellungen komplett auf Werksreset zurück zu setzen ohne Zugriff auf die Webseite?

Ich habe das Problem das ich zwar eine IP aus meinem Heimnetz bekommen habe aber die Uhr nicht mehr erreichbar ist.

Bei tasmota oder ähnlichen esp Firmwares kann man glaube ich mit 5x power cycle den AP Mode starten?

dbambus, 2023-12-18:
@irqnet

Sowas in der Art habe ich bisher noch nicht implementiert. Aber das wäre etwas für die Zukunft.

Mit freundlichen Grüßen
David

dbambus, 2023-12-18:
Ja, leider schon.

irqnet, 2023-12-18:
Da wären die Buttons von meinem SP511 Controller ja prädestiniert :)

dbambus, 2023-12-18:
In der tat, das wäre auch super Leicht zu implementieren ^^ gerne mal ein Vorschlag machen ^^

irqnet, 2023-12-18:
Ok meine Programmierskills halten sich für die Integration in Grenzen :) Aber ein erster Versuch, zumindest die Buttons einzubinden, noch ohne Code. Evtl. kann man includen abhäning von einer Variable? z.b.

Controller=SP511E, WEMOS, NODEMCU etc.

Die Buttons gibts ja default mäßig bei einem Wemos/NodeMCU nicht, man könnte aber freie GPIOs definieren.

Für den SP511E sähe das aktuell so aus:

`// Define the GPIO pins for the buttons
const int buttonPin1 = 2;
const int buttonPin2 = 13;
const int buttonPin3 = 14;

// Add more button pins as needed

void setup() {
  // Initialize serial communication for debugging
  Serial.begin(9600);

  // Set button pins as inputs
  pinMode(buttonPin1, INPUT_PULLUP);
  pinMode(buttonPin2, INPUT_PULLUP);
  pinMode(buttonPin3, INPUT_PULLUP);
  // Set additional button pins as inputs

}

void loop() {
  // Read the state of the buttons
  int buttonState1 = digitalRead(buttonPin1);
  int buttonState2 = digitalRead(buttonPin2);
  // Read additional button states as needed

  // Check if button POW is pressed
  if (buttonState1 == LOW) {
    Serial.println("Button POW pressed");
    // missing code for button action
    delay(500);  // debounce delay
  }

  // Check if button M is pressed
  if (buttonState2 == LOW) {
    Serial.println("Button M pressed");
    // missing code for button action
    delay(500);  // debounce delay
  }
  // Check additional buttons as needed

  // Check if button S is pressed
  if (buttonState3 == LOW) {
    Serial.println("Button S pressed");
    // missing code for button action
    delay(500);  // debounce delay
  }

}
`

dbambus, 2024-04-18:
Hinzugefügt mit https://github.com/ESPWortuhr/Multilayout-ESP-Wordclock/pull/394

Closed 2024-04-18.

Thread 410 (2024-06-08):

PermissionError: [Errno 13] Permission denied: '/home/christoph/Wortuhr/.pio/build/nodemcuv2/.sconsign310.tmp'

SkylightXD, 2024-06-08:
Hallo zusammen,

habt ihr eine Idee, was hier flasch läuft? :(

~/Wortuhr$ pio run -t upload
Processing nodemcuv2 (platform: espressif8266; board: nodemcuv2; framework: arduino)
-----------------------------------------------------------------------------------------------------------------------------------------------------------------------------
Verbose mode can be enabled via `-v, --verbose` option
CONFIGURATION: https://docs.platformio.org/page/boards/espressif8266/nodemcuv2.html
PLATFORM: Espressif 8266 (4.2.1) > NodeMCU 1.0 (ESP-12E Module)
HARDWARE: ESP8266 160MHz, 80KB RAM, 4MB Flash
PACKAGES:
 - framework-arduinoespressif8266 @ 3.30102.0 (3.1.2)
 - tool-esptool @ 1.413.0 (4.13)
 - tool-esptoolpy @ 1.30000.201119 (3.0.0)
 - tool-mklittlefs @ 1.203.210628 (2.3)
 - tool-mkspiffs @ 1.200.0 (2.0)
 - toolchain-xtensa @ 2.100300.220621 (10.3.0)
LDF: Library Dependency Finder -> https://bit.ly/configure-pio-ldf
LDF Modes: Finder ~ chain, Compatibility ~ soft
Found 45 compatible libraries
Scanning dependencies...
Dependency Graph
|-- NeoPixelBus @ 2.8.0
|-- ArduinoJson @ 6.21.5
|-- WebSockets @ 2.4.1
|-- RTClib @ 1.14.2
|-- PubSubClient @ 2.8.0
|-- WiFiManager @ 2.0.17+sha.d82d0a1
|-- DNSServer @ 1.1.0
|-- ESP8266HTTPUpdateServer @ 1.0
|-- ESP8266WebServer @ 1.0
|-- ESP8266WiFi @ 1.0
|-- ESP8266mDNS @ 1.2
|-- Hash @ 1.0
|-- Wire @ 1.0
|-- EEPROM @ 1.0
Building in release mode
npx --no-install grunt build
*** [.pio/build/nodemcuv2/lib856] /home/christoph/Wortuhr/.pio/build/nodemcuv2/lib856: Permission denied
Running "eslint:files" (eslint) task

Running "csslint:files" (csslint) task
Linting webpage/style.css...ERROR
[L496:C5]
WARNING: Use of !important Be careful when using !important declaration (important) Browsers: All
[L497:C5]
WARNING: Use of !important Be careful when using !important declaration (important) Browsers: All
[L504:C5]
WARNING: Unknown property 'grid-gap'. Properties should be known (listed in CSS3 specification) or be a vendor-prefixed property. (known-properties) Browsers: All
>> 1 file lint free.

Running "htmllint:files" (htmllint) task
>> encountered 0 errors in total
>> 0 file(s) had lint error out of 1 file(s). (skipped 0 files)

Running "clean:temp" (clean) task
>> 0 paths cleaned.

Running "cssmin:dev" (cssmin) task
Warning: Unable to create directory ".pio/build/webpage" (Error code: EACCES). Use --force to continue.

Aborted due to warnings.
*** [include/WebPageContent.gen.inc] Error 3
PermissionError: [Errno 13] Permission denied: '/home/christoph/Wortuhr/.pio/build/nodemcuv2/.sconsign310.tmp':
  File "/home/christoph/.platformio/packages/tool-scons/scons-local-4.7.0/SCons/Script/Main.py", line 1477:
    _exec_main(parser, values)
  File "/home/christoph/.platformio/packages/tool-scons/scons-local-4.7.0/SCons/Script/Main.py", line 1431:
    _main(parser)
  File "/home/christoph/.platformio/packages/tool-scons/scons-local-4.7.0/SCons/Script/Main.py", line 1174:
    nodes = _build_targets(fs, options, targets, target_top)
  File "/home/christoph/.platformio/packages/tool-scons/scons-local-4.7.0/SCons/Script/Main.py", line 1369:
    jobs.run(postfunc = jobs_postfunc)
  File "/home/christoph/.platformio/packages/tool-scons/scons-local-4.7.0/SCons/Taskmaster/Job.py", line 114:
    postfunc()
  File "/home/christoph/.platformio/packages/tool-scons/scons-local-4.7.0/SCons/Script/Main.py", line 1366:
    SCons.SConsign.write()
  File "/home/christoph/.platformio/packages/tool-scons/scons-local-4.7.0/SCons/SConsign.py", line 131:
    syncmethod()
  File "/home/christoph/.platformio/packages/tool-scons/scons-local-4.7.0/SCons/dblite.py", line 195:
    with self._open(self._tmp_name, "wb", opener=self.opener) as f:
  File "/home/christoph/.platformio/packages/tool-scons/scons-local-4.7.0/SCons/dblite.py", line 177:
    return os.open(path, flags, mode=self._mode)
Exception ignored in: <function _Dblite.__del__ at 0x785de3bbef80>
Traceback (most recent call last):
  File "/home/christoph/.platformio/packages/tool-scons/scons-local-4.7.0/SCons/dblite.py", line 184, in __del__
  File "/home/christoph/.platformio/packages/tool-scons/scons-local-4.7.0/SCons/dblite.py", line 181, in close
  File "/home/christoph/.platformio/packages/tool-scons/scons-local-4.7.0/SCons/dblite.py", line 195, in sync
  File "/home/christoph/.platformio/packages/tool-scons/scons-local-4.7.0/SCons/dblite.py", line 177, in opener
PermissionError: [Errno 13] Permission denied: '/home/christoph/Wortuhr/.pio/build/nodemcuv2/.sconsign310.tmp'
======================================================================== [FAILED] Took 2.28 seconds ===========================================

dbambus, 2024-07-14:
Hallo @SkylightXD

Das ist schon eine Weile her, wurde das Problem inzwischen gelöst? Es sieht so aus, als hättest du für den einen oder anderen Vorgang nicht die notwendigen Rechte gehabt. `[Errno 13] Permission denied`

Mit freundlichen Grüßen
David

Closed 2024-08-20.

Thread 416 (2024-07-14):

Farbskala & Symbolfunktion

bbroesl, 2024-07-14:
Hallo,
das ist echt ein toll programmiertes Projekt & es macht Spaß es umzusetzen!
Ich habe 2 Fragen, bisher habe ich dazu noch keine Lösung finden können:

- Bei den Farbeinstellungen werden die Farben anders übertragen. die runde Farbskala ist quasi horizontal gespiegelt (blau ist grün, pink ist gelb) -> ich gehe davon aus, dass es an den RGB Einstellungen liegt, habe aber noch nicht finden können wo man es einstellt?
- gibt es eine Möglichkeit bei der Symbol Funktion noch mehrere Symbole einzubinden? Wo genau werden die definiert?

vielen Dank!

dbambus, 2024-07-14:
Hallo @bbroesl

jeder Hersteller verbaut die LEDs unterschiedlich, um das zu beheben habe ich in den Einstellungen der Wordclock folgendes hinterlegt. Hier kann man die Zuordnung korrigieren, sodass dann auch das Farbrad wieder passt :-)
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

Zu den Symbolen.

Ich habe bisher nur das Herzsymbol fertig implementiert. Zu finden sind weitere, aber zumeist umadressierte, unter `https://github.com/ESPWortuhr/Multilayout-ESP-Wordclock/blob/main/include/icons.h` und aufgerufen werden sie in der Datei Wordclock.hpp ab 217ff. Hierzu muss ich allerdings sagen, dass ich gerne ein anderes Auswahlmenü für die Website plane, beschrieben in dem Issue https://github.com/ESPWortuhr/Multilayout-ESP-Wordclock/issues/297, aber es mangelt leider an der Zeit, die ganzen schönen Ideen zu implementieren :-(. Gerne aber schon mal den ersten Schritt machen, dann kann ich gerne mithelfen :-).

```
void ClockWork::displaySymbols(uint8_t iconNum) {
    static uint8_t count = 0;

    switch (iconNum) {
    case HEART:
        /* Heartbeat begin */
        if (count < 10) {
            G.color[Foreground].B += 0.03;
            if (G.color[Foreground].B > 1) {
                G.color[Foreground].B = 1;
            }
            count++;
        } else if (count < 20) {
            G.color[Foreground].B -= 0.03;
            if (G.color[Foreground].B <= 0) {
                G.color[Foreground].B = 0;
            }
            count++;
        } else {
            count = 0;
        }
        /* Heartbeat end */
        led.setIcon(iconNum);
        break;

    case SMILEY:
        led.setIcon(iconNum);
        break;

    case NOTE:
        led.setIcon(iconNum);
        break;

    case SNOW:
        led.setIcon(iconNum);
        break;

    default:
        break;
    }
}
```

Mit freundlichen Grüßen
David

Closed 2024-08-26.

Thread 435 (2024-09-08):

Add new customized layout

nikolai2111, 2024-09-08:
Hello everyone,

I am currently working with my colleague on a special customized version of the clock, the layout should not go into the official repo but only work in my fork.

Unfortunately I have not found a chapter in the documentation to add a customized layout manually, is there a possibility that someone who knows the code in detail could write here how and which adjustments would have to be made?

dbambus, 2024-09-08:
Hello,

Can you specify the layout a little bit?  Which Language? Matrix size? Standard or LED skipping for the arrangement?

Basicly take a look in the „Uhrtype“ Folder. Every .h/.hop definition you’ll add there will be available as header in the code as soon as you start the platform.io building process. There you can add new types of layout.

For a almost standard clock (10x11, DE, Standart LED) you can take a look at DE.10x11.Alternative.hpp

If you have an other matrix configuration you’ll need to use the override functions.

Mit freundlichen Grüßen
David

PS: Just a question, why don’t you want to share your layout ;-)

nikolai2111, 2024-09-08:
Hello,

It's a CH10x11, but with some custom and personal jokes. It's not that I want to hide it, it's also publicly visible in my fork (you can [have a look](https://github.com/nikolai2111/Multilayout-ESP-Wordclock/tree/JoergUhr)), but it doesn't make sense to include it by default in the layout collection because it doesn't really make sense for others.

Currently I have copied and renamed CH10x11.hpp, in which I have modified the `setFrontMatrixWord()` function calls to control the correct LEDs. Are there any other changes that need to be made to the rest of the code?

Do I just need to save the layout as an .hpp file and it will be added directly to the collection? I thought I would have to add the drop down menu to select the layout etc.

I'm also planning to add a branch with a PCB to my fork, which may be more relevant to this project than the custom layout. I have a certain idea / vision. ;P

nikolai2111, 2024-09-08:
Currently, I modified the following parts:
1. Added a new header file called `CH10x11.custom.hpp`. In this file I created the class `Ch10x11Custom_t` and mapped the LEDs. In the last line I also defined the pointer `Ch10x11Custom_t _ch10x11custom;`
2. Added the following entry in the `ClockType` enum in the `Uhr.h` file:
```cpp
Ch10x11Custom = 99
```
3. Added the following entry in the switch-case-statement in the `clockWork.hpp` file:
```cpp
case Ch10x11Custom:
    return &_ch10x11custom;
```

I think I've forgotten something, even with the search function I couldn't find more. But currently I can't select my custom version in the drop down menu.

dbambus, 2024-09-09:
I took a look in your current fork ist looks okay from my side. Does ist build and work ?

nikolai2111, 2024-09-11:
Yes, it runs perfectly fine. Thanks!

Closed 2024-09-09.

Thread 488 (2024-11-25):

M5 Atom Lite ESP32

irqnet, 2024-11-25:
Dank dem Port auf den ESP32 gibt es von mir eine neue Controller Empfehlung für das Wortuhr Projekt!

M5 Atom Lite
- ESP32 Board
- 25x25x10mm

Getestet mit dem aktuellen Branch, Anpassung der GPIO Ports.

Der Vorteil, das Modul hat einen Grove Connector, kann darüber mit Spannung versorgt werden und G26 wird darüber auch nach außen geführt.

Ich warte noch auf meine Grove Stecker, aktuell hab ich es getestet mit den PIN Outs an der Oberseite und G25 als LED GPIO.

> [env:m5stack-atom]
platform = espressif32
board = m5stack-atom
framework = arduino
; change microcontroller
board_build.mcu = esp32
board_build.partitions = partitions_singleapp_large.csv
; change MCU frequency
board_build.f_cpu = 240000000L
upload_protocol = esptool
build_flags =
    -Os
    -ffunction-sections
    -fdata-sections
    -Wl,--gc-sections
lib_deps =
    makuna/NeoPixelBus@^2.7.6
    bblanchon/ArduinoJson@^6.17.2
    links2004/WebSockets@2.4.1
    adafruit/RTClib@^1.11.2
    knolleary/PubSubClient@^2.8.0
    https://github.com/tzapu/WiFiManager#v2.0.17
    claws/BH1750@^1.3.0
extra_scripts = pre:extra_scripts.py

Link: https://shop.m5stack.com/products/atom-lite-esp32-development-kit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

irqnet, 2024-11-27:
Habe einen Test gemacht mit den Ports G26 und G32 die über den Anschluss unten verfügbar sind.
@dbambus
Leider bekomme ich hier kein Ergebnis wenn ich den LEDGPIO entsprechend ändere. Unter WLED funktionieren beide Ports allerdings.

Gibt es hier noch irgendwo eine andere Stelle die im Code geändert werden muss?

dbambus, 2024-12-06:
Hey @irqnet,

ich muss mal sehen wie das spezifiziert ist. Ich verwende ja die Neopixelbus Library.

Im Code selbst wird in der `clockwork.hpp` ein `#define LEDGPIO 27` gesetzt. Wie man der Schematic vom M5 ATOM entnehmen kann, ist da auch ein SK6812 angeschlossen, der sollte zumindest funktionieren.

Wenn man das `#define` aber abändert sollte es doch mit 26 bzw. 32 funktionieren, oder? Evtl muss man da tiefer in der verwendeten Lib nachschauen, was die Gründe dafür sind. Bspw. beim ESP8266 ist nur der RX Pin für die DMA Ansteuerung möglich.

Mit freundlichen Grüßen
David

irqnet, 2024-12-09:
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

Hi David,

das define habe ich entsprechend geändert aber es funktioniert mit den gpios am vorderen Anschluss eben nicht. Nur mit denen am breakout pin oben.

Kann natürlich sein das die Version der Neopixelbus Lib die ports nicht unterstützt? Aber beim kompilieren bekomme ich auch keinen Fehler.

Wüsste aktuell nicht wo ich da suchen muss.

irqnet, 2024-12-10:
Es scheint daran zu liegen das die GPIO Pins nicht default auf OUTPUT konfiguriert sind.

Hab bei der ESP32 Definition nun folgendes hinterlegt:

pinMode(LEDGPIO, OUTPUT);

irqnet, 2024-12-11:
@dbambus Ja konnte ich, wobei das jetzt ein erster Versuch war und ich die pinMode Definition sicher nicht an der richtigen Stelle mache.

Ich muss aktuell bei jedem Start/Neustart die LED Config neu auswählen, speichern, und zurück stellen, damit die überhaupt angehen. Vielleicht ist hier nochmal Hilfe nötig :)

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

Wie gesagt, das war ein Try and Error, aber so geht es mit den manuell beschriebenen Steps. Final ist das noch nicht :)

Irgendeine Idee wo man die GPIO Config für den ESP32 besser unterbringt?

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

irqnet, 2024-12-11:
Irgendwie scheint es aber nicht reproduzierbar zu sein. Mit einem zweiten Atom bekomme ich es nicht zum Rennen :/

dbambus, 2025-02-21:
Hey @irqnet,

ich habe mal deine PinMode Definition in das aktuelle Release gepackt. https://github.com/ESPWortuhr/Multilayout-ESP-Wordclock/pull/508/commits/929b89d5a0c486a7c38cde523d6f30b995ec9573

Mit freundlichen Grüßen
David

Closed 2025-02-21.

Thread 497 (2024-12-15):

Misplaced WIFI logo on first startup

nikolai2111, 2024-12-15:
I had an error with the WIFI logo at startup, only the first time when the flash is empty. After entering the WIFI credentials, the WIFI logo appeared correctly. When I cleaned the flash, the incorrect one reappears.

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

Sorry for the bad quality ;P.

PS: Yes, the first prototypes for the PCB have arrived! They look sooo clean, I was wondering if you would be interested in one?

dbambus, 2024-12-15:
Hey @nikolai2111,

fantastic job :-) nice. I would be interested in one of those PCBs.

Just for the recall. If you have a completely new code without any user inputs the Wifi Symbol is corrupted. As soon as you enter the credentials the Logo is just fine as long as you don't reset the clock again ?

Can you activate the LEDSWEEP in the `config.h` to see if all the LEDs (except of the minute ones) light up correctly ?

```
//--------------------------------------------------------------------------
// Settings for Boot sequence
//--------------------------------------------------------------------------
/*
 * Show Ip Adress of clock on boot, with BOOT_SHOWIP
 * Light up LEDs on boot, with BOOT_LEDSWEEP
 *
 * Valid values BOOT_SHOWIP [true, false]
 * Valid values BOOT_LEDSWEEP [true, false]
 */
#define BOOT_SHOWIP true
#define BOOT_LEDSWEEP true

```
Cheers
David

nikolai2111, 2024-12-18:
Hello @dbambus,

How do we get in touch with each other?
I never did this before, so I have no clue other than [guerrillamail](https://guerrillamail.com). Because I don't want to put my direct email here. ;P

> Can you activate the LEDSWEEP in the `config.h` to see if all the LEDs (except of the minute ones) light up correctly ?
I did that, there should be no problem with that.

I checked it again and I had a very strange behavior.
After a reset and also a re-upload I did not have the problem, the WIFI logo shows up normal. I only had the error after I had programmed the empty and new ESP32, or after I manually erased the flash (with the "Erase Flash" button) and then re-uploaded the firmware (with the "Upload and Monitor" button).

dbambus, 2024-12-18:
hey @nikolai2111,

I have my real name in Github and you can find my email address relatively quickly :-) but here it is:

david.panusch@fau.de

Just mail me.

Ahh, I got it. You are using an ESP32. Well I just recently adapted the code to work on that MCU. There could be some strange behaviors, still. I will take a look into it to figure out what is going on here.

Cheers
David

Closed 2025-02-21.

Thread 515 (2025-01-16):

When using a layout with SecondsFrame, Text is blinking when "Farbübergang" is activated

Vrumfondel, 2025-01-16:
When using a layout with SecondsFrame and "Farbübergang" is enabled, for each tick of the SecondsFrame the displayed words are shortly blinking in the Foreground color before switched again to the correct "random" color.

These blinking effects is visible on all Display modes.
Might this be caused by the order of the calls in loop(), where transition->loop() is called before secondsFrame->loop(), while the latter one might call led.clear() on each change, and the inpact of transition is elimitated until the next call to loop()?

Vrumfondel, 2025-01-17:
One question to this issue:

After playing around a little, I removed " parametersChanged = true; " at the end of frameLogic() --> Issue gone.

Why would setting "parameterChanged" needed there anyways? I don't see how frameLogic() would even do this?

Vrumfondel, 2025-02-22:
Fixed with my pull-requesr

Closed 2025-02-22.

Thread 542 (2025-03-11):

Bei Dimmen via Sensor wird manchmal Rotation ignoriert

TychoGold, 2025-03-11:
Guten Abend,

vielen Dank für dieses wirklich schöne Projekt!

Ich habe die Uhr mit dem I2C Helligkeitssensor aufgebaut. Die LEDs sind horizontal gespiegelt eingestellt. Teilweise passiert es beim Dimmen, dass die Rotation für mehrere Sekunden verloren geht.

Viele Grüße
Tycho

dbambus, 2025-03-13:
Hey @TychoGold,

vielen Dank für den Hinweis. Verwendest du die aktuellste Version aus dem Git oder das Release 4.0.0 ? Eigentlich sollte das Problem mit https://github.com/ESPWortuhr/Multilayout-ESP-Wordclock/commit/bc9a495ba99fcda496ab6ac158344147c542dc3a behoben worden sein.

Mit freundlichen Grüßen
David

dbambus, 2025-03-14:
Ah okay,

dann sollte das schon gefixed sein :-)

Mit freundlichen Grüßen
David

TychoGold, 2025-04-07:
Guten Morgen,

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

Leider muss der Issue wieder aufgemacht werden. Ich hab die aktuelle Version auf drei Uhren und die Besitzer der zwei anderen Uhren berichten das gleiche.

Vielleicht liegt es an der Form der Rotation? Wir haben die horizontal gespiegelt aufgebaut.

Viele Grüße
Tycho

Closed 2025-03-14.

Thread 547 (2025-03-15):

ESP 32

merlin2533, 2025-03-15:
Hallo

habe jetzt über mehrere ESP 32 versucht in unterschiedlichen Modellen. Leider erhalten wir immer ein Problem mit dem Partitionen.
Hast du eine IDee?

SP-ROM:esp32c3-api1-20210207
Build:Feb  7 2021
rst:0x1 (POWERON),boot:0xd (SPI_FAST_FLASH_BOOT)
SPIWP:0xee
mode:DIO, clock div:1
load:0x3fcd5810,len:0x438
load:0x403cc710,len:0x90c
load:0x403ce710,len:0x2624
entry 0x403cc710
E (234) esp_core_dump_flash: No core dump partition found!

Neuste Release 4.1 aber auch Release mit 3 versucht.
Danke

dbambus, 2025-03-15:
Hey @merlin2533,

Ichhabe hier paar fragen. du nutzt den ESP32C3, wenn ich nur den DUMP hier anschaue. hast du das flashen über Plattformio probiert oder über die bereitgestellte .bin?

Wenn Plattformio, hast du da die richtige build env in der plattformio.ini definiert?

Ich denke bei der .bin kann es noch zu Fehlern kommen, da ich für den ESP32 das Partitionsschema angepasst habe und ich da erst noch den richtigen Befehl zur verfügung stellen muss.

Mit freundlichen Grüßen
David

merlin2533, 2025-03-15:
Hallo David,

habe es mit Plattformio geflashed aber auch der BIN.
Env habe ich das richtige genommen. Hatte auch andere ESp32 bereits probiert die ich da hatte und versucht
Leider beides ohne erfolg. mit der BIN aber auch direkt Plattformio.

Hast du mir einen TIP wegen Partitionen?
Sollte ja eigentlich mit Plattformio so wie ich den Code sehe auch richtig geflashed werden

Markus

sogidaned, 2025-03-16:
@merlin2533,

ich hatte eine ähnliche Fehlermeldung. hat dann immer neu gestartet. bei mir startet sie aber auch ohne esp_core_dump_flash.
mein Problem war die Initialisierung des I2C.
Da ist im Programm
#define SDA_PIN_ESP32 7
#define SCL_PIN_ESP32 6

mein ESP32dev board hat sie aber auf 21 und 22. sobald ich sie ändere startet die Software
#define SDA_PIN_ESP32 21
#define SCL_PIN_ESP32 22

Wegen den Partitionen da habe ich gerade diese laufen. Weil in dem aktuellem release auch kein OTA funktioniert hat beim ESP32
nvs,      data, nvs,     0x9000,  0x6000,
phy_init, data, phy,     0xf000,  0x1000,
factory,  app,  factory, 0x10000, 0x150000,
ota_0,    app,  ota_0,   0x160000,0x150000,
ota_data, data, ota,     0x2b0000,0x2000,
coredump, data, coredump,0x2b2000,0x8000,

grüße
Alex

merlin2533, 2025-03-16:
Danke dir, habe gearde verschiedene Varianten versucht. Leider ohne Erfolg

Pin:: 21/22

mit ESp32C2
ESP-ROM:esp32c3-api1-20210207
Build:Feb  7 2021
rst:0x1 (POWERON),boot:0xd (SPI_FAST_FLASH_BOOT)
SPIWP:0xee
mode:DIO, clock div:1
load:0x3fcd5810,len:0x438
load:0x403cc710,len:0x90c
load:0x403ce710,len:0x2624
entry 0x403cc710
E (234) esp_core_dump_flash: No core dump partition fo⸮⸮⸮!⸮⸮⸮1 !% ⸮ !1⸮g⸮1⸮ 1⸮⸮H⸮1! g⸮1! g⸮1! g⸮1! g⸮1! g⸮1! g⸮1! !!155⸮!1⸮ ⸮ !1D!!%⸮ !%⸮⸮!!⸮!1D!⸮!⸮!1D⸮!1  ⸮1  !!⸮  !1⸮z!!  ⸮%⸮⸮⸮@5⸮ ⸮⸮@!%⸮⸮⸮1⸮   !%  ⸮!1 %! ⸮$! ⸮0⸮!⸮⸮⸮⸮! ⸮⸮! %⸮! %!%⸮5! ⸮ %⸮%!⸮ԕ⸮⸮ԡ%⸮⸮ԡ⸮⸮⸮ԩ(1 %⸮1 %%⸮⸮⸮4!!%⸮@⸮ 55⸮5⸮⸮⸮7⸮⸮
⸮⸮+⸮⸮c⸮ԡ⸮⸮ 55⸮5⸮⸮⸮7⸮1
⸮⸮+⸮⸮5⸮ԡ⸮⸮!
5 15$0⸮⸮ !Ĕ⸮⸮⸮⸮⸮g⸮!!%⸮⸮⸮⸮7@ !⸮⸮1⸮%$⸮⸮⸮-

mit ESP32 Wroom 32 (alte Partition
rst:0x1 (POWERON_RESET),boot:0x13 (SPI_FAST_FLASH_BOOT)
configsip: 0, SPIWP:0xee
clk_drv:0x00,q_drv:0x00,d_drv:0x00,cs0_drv:0x00,hd_drv:0x00,wp_drv:0x00
mode:DIO, clock div:2
load:0x3fff0030,len:1184
load:0x40078000,len:13232
load:0x40080400,len:3028
entry 0x400805e4
E (558) esp_core_dump_flash: No  ⸮K⸮⸮dump partition found!
E (558) esp_core_dump_flash: No core dump partition found!
T⸮⸮⸮jU⸮⸮⸮jRUUUUU⸮⸮⸮⸮⸮⸮⸮U rAe⸮⸮*⸮]

Partitionen:
Wenn ich das verwende habe ich ein Problem mit dem RTC
ESP-ROM:esp32c3-api1-20210207
Build:Feb  7 2021
rst:0x3 (RTC_SW_SYS_RST),boot:0xd (SPI_FAST_FLASH_BOOT)
Saved PC:0x403cf94c
SPIWP:0xee
mode:DIO, clock div:1
load:0x3fcd5810,len:0x438
load:0x403cc710,len:0x90c
load:0x403ce710,len:0x2624
entry 0x403cc710

mit E32 Woom 32 (mit E32dev)
rst:0x1 (POWERON_RESET),boot:0x13 (SPI_FAST_FLASH_BOOT)
configsip: 0, SPIWP:0xee
clk_drv:0x00,q_drv:0x00,d_drv:0x00,cs0_drv:0x00,hd_drv:0x00,wp_drv:0x00
mode:DIO, clock div:2
load:0x3fff0030,len:1184
load:0x40078000,len:13232
load:0x40080400,len:3028
entry 0x400805e4
E (558) esp_core_dump_flash: In
⸮Kɕ⸮сsize of core dump image: -1467940832
⸮⸮⸮⸮ZUUU⸮jR]UUUUUU⸮⸮⸮⸮⸮U rAe⸮u*⸮]

sogidaned, 2025-03-16:
@merlin2533,

habe leider die esp32C2 und esp32C3 nicht zum testen da.
hab nur mal kurz die KI gefragt.
Sie meinte:
Ja, es kann definitiv zu einem Konflikt mit LED_PIN 3 kommen, insbesondere bei ESP32-C3 und ESP32-C2, da GPIO3 bei diesen Varianten häufig für die serielle Kommunikation (UART TX) verwendet wird.

evtl gibt es bei den boards da auch noch einen Konflikt.
ich kann aber auch auf dem Holzweg sein.
hier noch eine liste von der KI.
Empfehlungsliste für Pin-Definitionen
ESP32 (Standard/ESP32Dev)
I2C:
SDA: GPIO21
SCL: GPIO22
LED (WS2812/NeoPixel):
Empfohlener Pin: GPIO2
Alternative: GPIO15, GPIO16, GPIO17
ESP32-C3
I2C:
SDA: GPIO8 oder GPIO9
SCL: GPIO6 oder GPIO10
LED (WS2812/NeoPixel):
Empfohlener Pin: GPIO8
Alternative: GPIO7, GPIO6
ESP32-C2
I2C:
SDA: GPIO5 oder GPIO7
SCL: GPIO6 oder GPIO8
LED (WS2812/NeoPixel):
Empfohlener Pin: GPIO4
Alternative: GPIO5, GPIO0
Wemos D1 Mini ESP32 (ESP32-WROOM-32)
I2C:
SDA: GPIO21
SCL: GPIO22
LED (WS2812/NeoPixel):
Empfohlener Pin: GPIO2
Alternative: GPIO13, GPIO15
ESP8266 (NodeMCU/Wemos D1 Mini)
I2C:
SDA: GPIO4 (D2)
SCL: GPIO5 (D1)
LED (WS2812/NeoPixel):
Empfohlener Pin: GPIO2 (D4)
Alternative: GPIO3 (RX)
Begründung
Die I2C-Pins sind jeweils die Standard-Pins, die vom Hardware-I2C-Controller unterstützt werden
Die LED-Pins wurden aufgrund ihrer Kompatibilität mit den RMT- oder Timer-Peripherien gewählt, die für die präzise Zeitsteuerung der WS2812-LEDs erforderlich sind
Für einige Chips (ESP32-C3, ESP32-C2) gibt es überlappende Empfehlungen für I2C und LED - in diesen Fällen muss abgewogen werden, welche Funktion welchen Pin bekommt
Diese Pin-Zuweisungen bieten die beste Leistung und Zuverlässigkeit für die jeweiligen Boards.

merlin2533, 2025-03-17:
Leider den ganzen Sonntag versucht aber leider ohne erfolg:
KI konnte mir auch nicht weiterhelfen aber auch die "Informationen aus dem Internet"

Für den ESP32-C3-DevKitM-1 ist es sehr wahrscheinlich, dass:
SCL auf GPIO6 (Pin 9)
SDA auf GPIO10(Pin 11) oder GPIO8(pin 6)

Fehler bleibt bei
ESP-ROM:esp32c3-api1-20210207
Build:Feb  7 2021
rst:0x3 (RTC_SW_SYS_RST),boot:0xd (SPI_FAST_FLASH_BOOT)
Saved PC:0x403cf94c
SPIWP:0xee
mode:DIO, clock div:1
load:0x3fcd5810,len:0x438
load:0x403cc710,len:0x90c
load:0x403ce710,len:0x2624
entry 0x403cc710

#define LED_PIN 8 // Use direct pin number
#define SDA_PIN_ESP32 9 // Use direct pin number
#define SCL_PIN_ESP32 11 // Use direct pin number

auch
#define LED_PIN 6 // Use direct pin number
#define SDA_PIN_ESP32 9 // Use direct pin number
#define SCL_PIN_ESP32 11 // Use direct pin number

Am ESP selbst ist auch nichts angeschlossen

dbambus, 2025-03-17:
Hey @sogidaned und @merlin2533,

schon mal sehr cool, dass hier nach einer Fehlerursache gesucht wird. Ich kann aktuell nur beisteuern (Kann erst heute am Abend wieder Testen), dass die Software problemlos mit der aktuellen default config auf einem ESP32C3 und ESP8266 gelaufen ist.

ich würde noch fragen, wisst Ihr welche Speicherconfig eure MCUs haben?

Als ESP8266 kommt bei mir ein WEMOS LOLIN MINi D1, ESP32 ein WEMOS 32 D1 Mini (4MB) und als ESP32C3 ein SuperMini (4MB) zum Einsatz.

Mit freundlichen Grüßen
David

sogidaned, 2025-03-17:
@dbambus

ich habe den esp32dev mit 4mb.

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

bei läuft auch alles nach dem ich den i2c auf 21/22 gesetzt habe (leds habe ich nicht getestet)
ich kann auch leider den fehler von merlin2533 nicht mehr reproduzieren.
kam noch von der zeit als ich dachte es lag an der LED Init und nicht der RTC Init die kurz darauf folgt.
bei mir hat die bootschleife immer nach LED Init begonnen.
mein esp hat auch teilwese probleme bei der bootschleife und der hohen Baudrate überhaupt was anzuzeigen.
bei einer monitorspeed von 115200 klappt es aber. Dann kommt mit der aktuellen software (pin 7/6) folgendes:
Beim start direkt:
E (558) esp_core_dump_flash: No ␇斕�dump partition found!
E (558) esp_core_dump_flash: No core dump partition found!
(läuft aber ohne core dump partition auch)

am ende des setups der rst fehler in schleife( aber nur bei pin7/6)
........
eeprom schreiben
LED Init
ets Jun  8 2016 00:22:57

rst:0x8 (TG1WDT_SYS_RESET),boot:0x13 (SPI_FAST_FLASH_BOOT)
flash read err, 1000
ets_main.c 371
ets Jun  8 2016 00:22:57

rst:0x7 (TG0WDT_SYS_RESET),boot:0x13 (SPI_FAST_FLASH_BOOT)
flash read err, 1000
ets_main.c 371
ets Jun  8 2016 00:22:57

@merlin2533

basieren auf der neuen info "ESP32-C3-DevKitM-1" :

ich weis nicht ob du die config schon versucht hast das würde cursor für das board vorschlagen.
soweit ich weiß, wird auch immer die gpio nummer angegeben. Nie die pin nummer vom board selber obwohl "PIN" in der Definition steht.

#define LED_PIN 8
#define SDA_PIN_ESP32 5
#define SCL_PIN_ESP32 4

grüße
Alex

merlin2533, 2025-03-17:
glaub bei mir ist es verhext, habe ja auch das ESP Woom 32 Board

#define LED_PIN 8
#define SDA_PIN_ESP32 5
#define SCL_PIN_ESP32 4

wenn ich es mit Partion wie beim orginal , un deinen Pins Flashe, erhalte ich den Fehler immer noch

ets Jul 29 2019 12:21:46

rst:0x1 (POWERON_RESET),boot:0x13 (SPI_FAST_FLASH_BOOT)
configsip: 0, SPIWP:0xee
clk_drv:0x00,q_drv:0x00,d_drv:0x00,cs0_drv:0x00,hd_drv:0x00,wp_drv:0x00
mode:DIO, clock div:2
load:0x3fff0030,len:1184
load:0x40078000,len:13232
load:0x40080400,len:3028
entry 0x400805e4
E (558) esp_core_dump_flash: No
⸮K⸮⸮dump partition found!
E (558) esp_core_dump_flash: No core dump partition found!
JUUUU⸮⸮⸮j⸮⸮JUU⸮⸮⸮⸮⸮⸮⸮⸮⸮U rAe⸮]e⸮YeS
⸮ ⸮  bt ⸮ ⸮ ⸮ ⸮ ⸮ ⸮ ⸮ ⸮ ⸮ ⸮ ⸮⸮z⸮⸮Nw⸮U⸮⸮fU]HU⸮ ⸮ՅUUE⸮U ⸮⸮E⸮U lU ⸮T	⸮V⸮r⸮^] B⸮⸮m⸮⸮u4
⸮T⸮!⸮Zu⸮[⸮ ⸮⸮[⸮l⸮⸮[⸮du⸮⸮⸮⸮⸮⸮ur⸮q+ur⸮ ⸮ur⸮QuR ⸮]⸮⸮⸮Iѝ⸮⸮⸮TemUi ⸮/⸮U⸮ ⸮⸮E-ǆ-j
 ⸮⸮qv⸮⸮ ⸮⸮}A⸮⸮⸮ets Jul 29 2019 12:21:46

und beim "ESP32-C3-DevKitM-1" :
ESP-ROM:esp32c3-api1-20210207
Build:Feb  7 2021
rst:0x3 (RTC_SW_SYS_RST),boot:0xd (SPI_FAST_FLASH_BOOT)
Saved PC:0x403cf94c
SPIWP:0xee
mode:DIO, clock div:1
load:0x3fcd5810,len:0x438
load:0x403cc710,len:0x90c
load:0x403ce710,len:0x2624
entry 0x403cc710

Auch wenn ihr mehrmals boote auch mehr Power gebe, Fehler ist immer der gleiche.

sogidaned, 2025-03-17:
@merlin2533

setz mal die monitor speed runter von 460800 auf 115200. dann kann ich z.b. dass bei mir lesen:
x�x�␀�xxx��␀␀x��x�␀x␀��␀␀�x�x␀xx␀�␀�x��x�x�����x␀�␀␀

in src/wohrtuhr.cpp zeile 149
und in dem fall(esp32dev) in der platform.ini zeile 38

#define LED_PIN 3

// Define the I2C pins for the ESP32
#define SDA_PIN_ESP32 21
#define SCL_PIN_ESP32 22

dann läufts bei mir der anmeldehotspot

evtl noch einen erase flash vorher

grüße
Alex

merlin2533, 2025-03-17:
Arbeitet so perfekt, @dbambus willst du das in den Master übernehmen? Oder dies als Option in env übernehmen?

esp32dev hier hat es perfekt funktioniert

merlin2533, 2025-03-17:
Mega Support

Closed 2025-03-17.

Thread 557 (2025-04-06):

Crash in >v4.1.0 (main) when setting mode digital clock or seconds (potentially in Led::showNumbers())

hoffie, 2025-04-06:
#550 contains comments about crashes in v4.1.0. I'm experiencing the same on main (haven't verified the release v4.1.0 directly). I'm opening this as a sperate issue as #550 is mainly about distorted animations and I don't want to conflate those topics.

## Trigger
The crash happens when setting the mode to digital clock or seconds. It might also trigger directly after boot (probably if digital clock had been selected before booting/flashing the new version).

## Exception

```
Exception (3):
epc1=0x4020bf0d epc2=0x00000000 epc3=0x00000000 excvaddr=0x402ac18e depc=0x00000000

LoadStoreError: Processor internal physical address or data error during load or store
  epc1=0x4020bf0d in Led::showNumbers(char, char) at ??:?
  excvaddr=0x402ac18e in system_get_sdk_version at ??:?

>>>stack>>>

ctx: cont
sp: 3ffffd00 end: 3fffffd0 offset: 0150
3ffffe50:  e88ee888 e8eee8e8 3ffffe80 3ffffe70
3ffffe60:  00000008 00000034 00000032 40205e41
3ffffe70:  3fff22a2 3ffe8648 00000002 0000001a
3ffffe80:  3fffff31 00000000 3fff51a4 3fff26f4
3ffffe90:  3fff22a2 3ffe8648 3ffea9f4 4021449c
3ffffea0:  35320032 2d34302d 31203630 36343a34
3ffffeb0:  2032343a 32302b28 0a293030 3ffe8300
3ffffec0:  3ffe8368 402b0810 3ffe8368 40236f52
3ffffed0:  00000000 00005b0b fe353f7c 006945dd
3ffffee0:  00000000 00000000 3ffe86f8 00000000
3ffffef0:  00000000 00000000 00005b0b 40228885
3fffff00:  00000000 00005b0b fdf3b645 006945dd
3fffff10:  3fff2658 00000001 3fff7a40 000000cc
3fffff20:  00000000 00005b0b 00000000 4022984c
3fffff30:  00000034 3fff1a40 3fff1da0 40218088
3fffff40:  4022f0a8 00000000 00001388 3fff28d8
3fffff50:  3fff1e6c 00005b0b 00000000 4022984c
3fffff60:  3fff2371 3fff236f 3fff1a40 3fff28d8
3fffff70:  3fff2371 3fff236f 3fff18c8 402149d6
3fffff80:  0000002a 0000002e 0000000e 00000006
3fffff90:  00000003 0000007d 00000000 0000005f
3fffffa0:  00000001 feefeffe 67f277b2 00000000
3fffffb0:  3fffdad0 00000000 3fff28ac 40228930
3fffffc0:  feefeffe feefeffe 3fffdab0 401003e1
<<<stack<<<

0x40205e41 in _ZN23NeoEsp8266DmaMethodBaseI19NeoEsp8266DmaEncodeI25NeoEsp8266DmaSpeedWs2812xEE6UpdateEb$isra$0 at Wortuhr.cpp:?
0x4021449c in ClockWork::loop(tm&) at ??:?
0x402b0810 in etharp_output at ??:?
0x40236f52 in _getenv_r at /workdir/repo/newlib/newlib/libc/stdlib/getenv_r.c:126
0x40228885 in esp_try_delay(unsigned int, unsigned int, unsigned int) at ??:?
0x4022984c in __delay at ??:?
0x40218088 in WebSocketsServerCore::handleClientData() at ??:?
0x4022f0a8 in DhcpServer::isRunning() const at ??:?
0x4022984c in __delay at ??:?
0x402149d6 in loop at ??:?
0x40228930 in loop_wrapper() at core_esp8266_main.cpp:?
0x401003e1 in cont_wrapper at ??:?
```

## Hardware
Node MCU: D1 Mini Pro 4m
LED band: WS2812B Grb
Layout: Ger10x11Clock (my gut feeling is that the layout dimensions might be most relevant factor, but I haven't verified yet)

## Analyses / Potential causes
git bisect pointed me to 1ea211006d787bfdb86d4fc258f8a7bd153a149e as the first broken version (cc @BastiMu). I'm currently trying to further pinpoint the exact details.

dbambus, 2025-04-06:
Hey @hoffie,

Thank you for the detailed bug report. Can you elaborate if the last release is also affected ?

Cheers
David

hoffie, 2025-04-06:
> Thank you for the detailed bug report. Can you elaborate if the last release is also affected ?

Based on the git details (`git tag --contains ...` is empty), I'd say: no. I think the PR #483 is too recent for it to be included in V4.1.0 (although the commits are from Nov 2024).

hoffie, 2025-04-06:
Further results after sprinkling in some debug prints:
[`PROGMEM`|https://arduino-esp8266.readthedocs.io/en/latest/PROGMEM.html] is new to me (I'm not that deep into ESP or Arduino), but `fontSize` and `fontHeight` are declared to be that. It seems like that those are not supposed to be directly referenced as arrays and require pgm_read_byte() instead (?).
For some reason, `fontWidth[0]` ("normal size") seems to crash, while `fontWidth[1]` ("small size") does not. This might explain why it did not show up during testing.

hoffie, 2025-04-06:
I think 1ea211006d787bfdb86d4fc258f8a7bd153a149e (+ 3fd2b248) are other problematic commits (maybe also relevant for #550).

I believe the accesses to `fontWidth` and `fontHeight` are the problem, as they are defined as `PROGMEM`. I'm working on a potential fix.

dbambus, 2025-04-06:
Hey,

I could have a look to the code earliest on Tuesday.
Then we could elaborate the problem together ;-) till then I m thankful for every hint/solution you can give me or came up with.

But one remark here the fontsizes shouldn’t be in the transitions. For a cleaner code each mode should have its own unique.h/.hpp or class to interface with.
Well some To Do here. 🤯

Cheers
David

hoffie, 2025-04-06:
> till then I m thankful for every hint/solution you can give me or came up with.

Sure. I've submitted #558 which fixes the issues for me.

> But one remark here the fontsizes shouldn’t be in the transitions. For a cleaner code each mode should have its own unique.h/.hpp or class to interface with.
> Well some To Do here. 🤯

I understand. If possible, I would want to focus on fixing the annoying bug here first and will probably leave the refactoring to you...? :)

Closed 2025-04-09.

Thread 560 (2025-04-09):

Helligkeitsregelung mit LDR wegen BH1750-Integration unbrauchbar

D-ominik, 2025-04-09:
Mit #408 wurde eine Integration für den BH1750 ergänzt. Ich verwende bei allen Uhren einen LDR und in Kombination mit der neuen Firmware ist die Helligkeitsregelung vollkommen unbrauchbar, es wird gar nicht mehr geregelt.

@STT65 hast du dein Update mal mit einem LDR getestet? Welche Lux-Werte sollten zu erwarten sein? Ich habe völlig abgedeckt Werte um 2000 Lux herum und mit normaler Raum-Helligkeit 46631 Lux. Letzteres scheint der Maximalwert zu sein, da er auch mit intensiver Beleuchtung nicht weiter steigt.

Ich verwende 5528er LDR mit 10k Widerstand gegen GND.

D-ominik, 2025-04-18:
@dbambus Ich hatte nun einmal Zeit, mir das Problem näher anzusehen, ich denke mit der BH1750-Integration ist für den LDR-Fallback etwas schief gelaufen:

- @STT65 kommentiert im Code einen ADC-Spannungsbereich von 0-1V. Das ist korrekt für den reinen ESP-Chip. Den wird aber wohl niemand für dieses Projekt verwenden, zumal die Doku explizit die Verwendung von Development-Boards vorsieht (z.B. NodeMCU). Die Dev-Boards haben (zumindest alle gängigen) einen Spannungsteiler an den Analog-Pins, um einen Pegel bis Boardspannung (3.3V) zu ermöglichen. Das ist zweckmäßiger und grillt den Eingang nicht so schnell. Weil Stefan seinen Spannungsteiler auf maximal 1 Volt ausgelegt hat, der Port aber 3.3 Volt erlaubt, ist die Auflösung schlecht.
 
Und wenn man kein Dev-Board verwendet, wäre es nicht ratsam, einen LDR ohne Vorwiderstand (wie im vorgesehenen Schaltbild) mit 3.3V zu versorgen, wenn der Eingang nur 1V verträgt, da selbst ein LDR mit einem Hell-Nennwiderstand von mehreren Kilo-Ohm (der Hellwiderstand bezieht sich auf nur 10 Lux) bei sehr hellem Licht (direktes Sonnenlicht, helle Taschenlampe) bis unter 50 Ohm runter geht. Das Ende des Analogeingangs wäre vorprogrammiert.

- In Stefans Kommentar ist ein Spannungsteiler mit einem 220 Ohm Widerstand schematisiert. Den LDR hat er nicht spezifiziert, die üblichen LDR liegen jedoch i.d.R. bei mehreren kOhm bei normaler Raumhelligkeit (ohne direkte Bestrahlung). An einer Wand ohne gegenüberliegendes Fenster ist der Widerstand schnell im Bereich jenseits von 30 kOhm. Das resultiert, bei einer üblichen Lichtsituation im Inneren und dem Anwendungsfall der Uhr, in einer Spannung von 0,3V bis 0,01V an einem Analogeingang der bis 3.3V vorsieht und nur mit 10Bit (0-1023) auflöst. Der Bereich von Dämmerung bis Dunkelheit liegt dann bei 0,01V bis 0,001V (und kleiner). Da ist es nicht überraschend, dass Stefan keine zufriedenstellenden Ergebnisse in dunkler Umgebung erzielte.
 
Mich hat gewundert, wieso er einen Spannungsteiler mit 220 Ohm realisiert hat, wo die Anleitung doch 10k vorgibt. Nach etwas suchen bin ich fündig geworden: in `pics/Schematic.(png|pdf)` ist ein Widerstand mit Farbcode rot-rot-braun, also 220 Ohm abgebildet. Das sollte in 10kOhm geändert werden (am besten auch beschriften). Ich denke es wäre auch sinnvoll einen geeigneten LDR-Typ zu empfehlen, z.B. den 5528.

Da die Helligkeitsregelung mit Schaltung nach Anleitung (mit 10k Widerstand) gar nicht mehr funktioniert, habe ich den Aufbau mal separat nachgestellt und die drei Messvarianten (BH1750, altes LDR-Schema, neues LDR-Schema) parallel integriert. Jeweils mit den default-Werten für autoBrightOffset, autoBrightSlope, autoLdrBright, autoLdrDark, etc.:
```
BH1750: 1.67 lx, 39 gain
LDR alt: 19 lx, 13 gain
LDR neu: 357.21 lx, 88 gain

BH1750: 2.50 lx, 39 gain
LDR alt: 27 lx, 16 gain
LDR neu: 683.49 lx, 100 gain

BH1750: 5.83 lx, 39 gain
LDR alt: 49 lx, 24 gain
LDR neu: 1986.40 lx, 100 gain

BH1750: 15.83 lx, 41 gain
LDR alt: 75 lx, 34 gain
LDR neu: 4406.32 lx, 100 gain

BH1750: 32.50 lx, 43 gain
LDR alt: 117 lx, 49 gain
LDR neu: 10236.60 lx, 100 gain

BH1750: 43.33 lx, 44 gain
LDR alt: 131 lx, 54 gain
LDR neu: 12715.65 lx, 100 gain

BH1750: 452.50 lx, 100 gain
LDR alt: 231 lx, 91 gain
LDR neu: 38130.87 lx, 100 gain
```
Bis auf den Bereich voller Abdunklung wird mit der neuen Logik mit LDR immer maximale Helligkeit ausgesteuert. Mit einem 220 Ohm Widerstand gehen die "Lux"-Werte nicht so durch die Decke, erwartungsgemäß sind die Werte bei wenig Helligkeit dann jedoch recht "festgenagelt".

Der "gain" bei wenig Helligkeit ist auch beim BH1750 recht hoch und im unteren Helligkeitsbereich zu statisch. Das ließe sich mit den Konfigurationswerten etwas optimieren. Generell ist es nicht einfach, mit der Kombination "Mindesthelligkeit" und "Steilheit" zielführende Resultate zu erreichen. Es braucht viele Versuche bei verschiedenen Helligkeiten. Wenn man dann noch bestimmte Maximalwerte nicht überschreiten möchte... Im Prinzip war die alte Lösung, die Minimal- und die Maximalhelligkeit zu definieren, leichter verständlich, die gewünschten Resultate wurden schneller erzielt (keine langwierigen Versuche) und, wie man am Verlauf von "LDR alt" sieht, auch zweckdienlicher.

D-ominik, 2025-04-18:
Ich habe die LDR-Auswertung überarbeitet und eine klassische Lux-Umrechnung gewählt. Innerhalb der Helligkeitsbereiche von  Raumlicht erhält man sehr brauchbare Werte (für den Einsatzzweck, ist ja kein Messgerät). Das Ganze ohne statische Kurvenauswertung. Die Werte des Spannungsteilers sind parametrisiert und daher bei abweichendem Setup anpassbar.
```
BH1750:     1.67 lx
LDR alt:    10 lx
LDR neu:    134.94 lx
LDR rework: 2 lx

BH1750:     4.17 lx
LDR alt:    22 lx
LDR neu:    479.61 lx
LDR rework: 6 lx

BH1750:     70.00 lx
LDR alt:    135 lx
LDR neu:    13521.21 lx
LDR rework: 74 lx

BH1750:     90.83 lx
LDR alt:    156 lx
LDR neu:    17863.89 lx
LDR rework: 104 lx

BH1750:     146.67 lx
LDR alt:    176 lx
LDR neu:    22746.74 lx
LDR rework: 149 lx

BH1750:     224.17 lx
LDR alt:    196 lx
LDR neu:    27871.67 lx
LDR rework: 221 lx

BH1750:     465.83 lx
LDR alt:    221 lx
LDR neu:    35357.46 lx
LDR rework: 439 lx

BH1750:     595.00 lx
LDR alt:    231 lx
LDR neu:    38211.65 lx
LDR rework: 622 lx

BH1750:     617.50 lx
LDR alt:    230 lx
LDR neu:    38211.65 lx
LDR rework: 622 lx
```

Phrunky, 2025-04-21:
Hallo D-ominik,

vielen Dank für Deine Erläuterungen. Ich habe ebenso versucht, die Helligkeitsanpassung für mich zu verbessern und habe nur unwesentliche Fortschritte gemacht - allerdings habe ich die Geschichte bisher nur hardwareseitig betrachtet.
Vorab: bitte entschuldige, wenn ich unqualifiziert frage, aber kannst Du ausführen, was Du unter den Ausführungen "LDR alt", "LDR neu" und "LDR rework" meinst? "LDR alt" entspricht wohl dem 220 Ohm-Widerstand "LDR neu" vermutlich dem 10k Ohm. Und ich verstehe auch noch nicht, ob und wo es im Programmcode eine Umsetzungstabelle für die unterschiedlichen Belichtungsgrade gibt.

Sorry für meine Fragen, aber die Doku gibt da auch nicht viel her.

PS Ich bin die Geschichte bisher noch nicht mit dem BH1750 angegangen.

Phrunky, 2025-04-25:
Vielen, vielen Dank für die ausführliche Information und das eingebrachte Engagement

Closed 2025-05-22.

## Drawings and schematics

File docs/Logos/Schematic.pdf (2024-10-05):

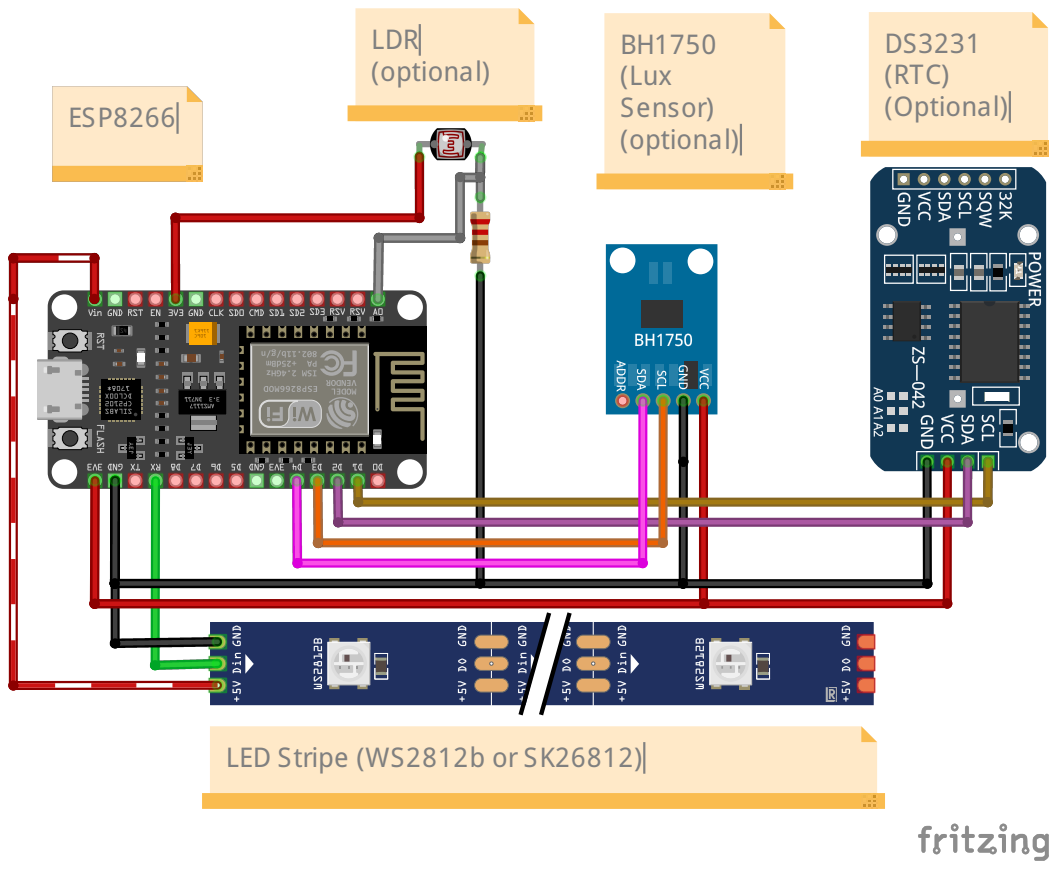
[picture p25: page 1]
DS3231 (RTC) (Optional); BH1750 (Lux Sensor) (optional); ESP8266; LDR (optional)

LED Stripe (WS2812b or SK26812)

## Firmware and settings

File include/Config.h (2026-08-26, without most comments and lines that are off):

#define LED_PIN 3 // Use direct pin number (ESP8266 currently unsupported)
#define POWER_BUTTON_PIN 255
#define MODE_BUTTON_PIN 255
#define SPEED_BUTTON_PIN 255
#define SDA_PIN_ESP32 255
#define SCL_PIN_ESP32 255
#define SDA_PIN_ESP32C3 255
#define SCL_PIN_ESP32C3 255
#define SDA_PIN_ESP8266 D2
#define SCL_PIN_ESP8266 D1
#define DEFAULT_LAYOUT Ger10x11Alternative
#define DEFAULT_LEDTYPE Grb
#define WHITE_LEDTYPE WhiteType::NeutralWhite
#define DEFAULT_HUE 120
#define DEFAULT_BRIGHTNESS 100
#define DEFAULT_BUILDTYPE BuildTypeDef::Normal
#define AUTOBRIGHT_LDR_RESBRIGHT 15
#define AUTOBRIGHT_LDR_RESDARK 1000
#define AUTOBRIGHT_LDR_RESDIVIDER 10
#define RTC_Type RTC_DS3231
#define SERNR 440
#define GENERAL_VERBOSE true
#define WIFI_VERBOSE false
#define WEATHER_VERBOSE false
#define MANUAL_WIFI_SETTINGS false
#define WIFI_SSID "WIFI_SSID"
#define WIFI_PASSWORD "YOUR_WIFI_PASSWORD"
#define CP_PROTECTED false
#define CP_SSID "Connect_to_Wordclock"
#define CP_PASSWORD "CHANGE_THIS_PASSWORD"
#define WEB_PROTECTED false
#define WEB_USER "admin"
#define WEB_PASSWORD "CHANGE_THIS_PASSWORD"
#define BOOT_SHOWIP false
#define BOOT_LEDSWEEP false
#define MINUTE_LED4x
#define IT_IS_Permanent
#define REVERSE_MINUTE_DIR false
#define MIRROR_FRONT_VERTICAL false
#define MIRROR_FRONT_HORIZONTAL false
#define EXTRA_LED_PER_ROW false
#define FLIP_HORIZONTAL_VERTICAL false
#define MEANDER_ROWS true

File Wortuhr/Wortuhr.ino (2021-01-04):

/*--------------------------------------------------------------------------
 * Hier wird definiert, welche Anzahl von LED's bzw. Reihen verwendet werden
 */
#define UHR_114                       // Uhr mit 10 Reihen, jeweils 11 LED's pro Reihe + 4 LED's für Minuten
//#define UHR_114_Alternative         // Uhr mit 10 Reihen, jeweils 11 LED's pro Reihe + 4 LED's für Minuten, mit geändertem Layout für extra Wörter in der Matrix
//#define UHR_114_2Clock			  // Uhr mit 10 Reihen, jeweils 11 LED's pro Reihe + 4 LED's für Minuten, mit dem Layout vom orginal Hersteller
//#define UHR_125                       // Uhr mit 11 Reihen, jeweils 11 LED's pro Reihe + 4 LED's für Minuten
//#define UHR_169                     // Uhr mit zusätzlichen LED's um den Rahmen seitlich zu beleuchten
//#define UHR_242                       // Uhr mit Wettervorhersage 242 LED's --> Bitte die Library "ArduinoJson" im Library Manager installieren!

#define SERNR 101             //um das eeprom zu löschen, bzw. zu initialisieren, hier eine andere Seriennummer eintragen!

// Wenn die Farben nicht passen können sie hier angepasst werden:
#define Brg_Color   // RGB-Stripe mit dem Chip WS2812b und dem Layout Brg
//#define Grb_Color      // RGB-Stripe mit dem Chip WS2812b und dem Layout Grb
//#define Rgb_Color    // RGB-Stripe mit dem Chip WS2812b und dem Layout Rgb
//#define Rbg_Color    // RGB-Stripe mit dem Chip WS2812b und dem Layout Rbg
//#define Grbw_Color   // RGBW-Stripe mit dem Chip SK6812 und dem Layout Grbw

#define RTC_Type RTC_DS3231        // External Realtime Clock: RTC_DS1307, RTC_PCF8523 oder RTC_DS3231

bool DEBUG = true;       // DEBUG ON|OFF wenn auskommentiert
//#define VERBOSE          // DEBUG VERBOSE Openweathermap
/*--------------------------------------------------------------------------
 * ENDE Hardware Konfiguration. Ab hier nichts mehr aendern!!!
 *--------------------------------------------------------------------------
 */

#include <Arduino.h>
#include <NeoPixelBus.h>
#include <ESP8266WiFi.h>
#include <ESP8266WebServer.h>
#include <ESP8266mDNS.h>
#include <ESP8266HTTPUpdateServer.h>
#include <WiFiClient.h>
#include <WiFiUdp.h>
#include <NTPClient.h>
#include <Hash.h>
#include <TimeLib.h>
#include <Timezone.h>
#include <Wire.h>
#include <RTClib.h>
#include <PubSubClient.h>
#include <ArduinoJson.h>

#include "Uhr.h"
#include "WebPage_Adapter.h"
#include "EEPROMAnything.h"
#include "icons.h"

#include "Uhrtypes/uhr_func_114.hpp"
#include "Uhrtypes/uhr_func_114_Alternative.hpp"
#include "Uhrtypes/uhr_func_114_2Clock.hpp"
#include "Uhrtypes/uhr_func_125.hpp"
#include "Uhrtypes/uhr_func_169.hpp"
#include "Uhrtypes/uhr_func_242.hpp"

UHR_114_t Uhr_114_type;
UHR_114_Alternative_t Uhr_114_Alternative_type;
UHR_114_2Clock_t Uhr_114_2Clock_type;
UHR_125_t Uhr_125_type;
UHR_169_t Uhr_169_type;
UHR_242_t Uhr_242_type;

iUhrType *usedUhrType = nullptr;

NeoPixelBus<NeoBrgFeature, Neo800KbpsMethod> *strip_RGB = NULL;
NeoPixelBus<NeoGrbwFeature, Neo800KbpsMethod> *strip_RGBW = NULL;

TimeChangeRule CEST = {"CEST", Last, Sun, Mar, 2, 120};     //Central European Summer Time
TimeChangeRule CET = {"CET ", Last, Sun, Oct, 3, 60};       //Central European Standard Time
Timezone tzc(CEST, CET);

WiFiClient client;
time_t ltime, utc;
TimeChangeRule *tcr;
WiFiUDP ntpUDP;
NTPClient timeClient(ntpUDP, G.zeitserver);
PubSubClient mqttClient(client);

#ifndef RTC_Type
RTC_DS3231 RTC;
#else
RTC_Type RTC;
#endif

#include "font.h"
#include "mqtt_func.hpp"
#include "uhr_func.hpp"
#include "wifi_func.hpp"
#include "openwmap.h"

//------------------------------------------------------------------------------

iUhrType *getPointer(uint8_t num){
	switch (num){
		case 1:
			return reinterpret_cast<iUhrType *>(&Uhr_114_type);
		case 2:
			return reinterpret_cast<iUhrType *>(&Uhr_114_Alternative_type);
		case 6:
			return reinterpret_cast<iUhrType *>(&Uhr_114_2Clock_type);
		case 3:
			return reinterpret_cast<iUhrType *>(&Uhr_125_type);
		case 4:
			return reinterpret_cast<iUhrType *>(&Uhr_169_type);
		case 5:
			return reinterpret_cast<iUhrType *>(&Uhr_242_type);
		default:
			return nullptr;
	}
}

//------------------------------------------------------------------------------

void InitLedStrip(uint8_t num){
	if (num == Grbw){
		if (strip_RGBW != NULL){
			delete strip_RGBW; // delete the previous dynamically created strip
		}
		strip_RGBW = new NeoPixelBus<NeoGrbwFeature, Neo800KbpsMethod>(usedUhrType->NUM_PIXELS());
		strip_RGBW->Begin();
	}
	else{
		if (strip_RGB != NULL){
			delete strip_RGB; // delete the previous dynamically created strip
		}
		strip_RGB = new NeoPixelBus<NeoBrgFeature, Neo800KbpsMethod>(usedUhrType->NUM_PIXELS());
		strip_RGB->Begin();
	}
}

//------------------------------------------------------------------------------
// Start setup()
//------------------------------------------------------------------------------

void setup(){
	//-------------------------------------
	// EEPROM lesen / initialisieren
	//-------------------------------------
	EEPROM.begin(512);

	eeprom_read();

	if (G.sernr != SERNR){
		for (uint16_t i = 0; i < 512; i++) { EEPROM.write(i, i); }
		EEPROM.commit();

		G.sernr = SERNR;
		G.prog = 1;
		G.param1 = 0;
		G.param2 = 0;
		G.prog_init = 1;
		G.conf = COMMAND_IDLE;
		for (uint8_t i = 0; i < 4; i++) { for (uint8_t ii = 0; ii < 4; ii++) { G.rgb[i][ii] = 0; }}
		G.rgb[Foreground][2] = 100;
		G.rgb[Effect][1] = 100;
		G.rr = 0;
		G.gg = 0;
		G.bb = 0;
		G.ww = 0;
		G.hell = 2;
		G.geschw = 10;
		G.client_nr = 0;
		G.zeige_sek = 0;
		G.zeige_min = 1;
		G.ldr = 0;
		G.ldrCal = 0;
		strcpy(G.cityid, "");
		strcpy(G.apikey, "");
		strcpy(G.zeitserver, "europe.pool.ntp.org");
		strcpy(G.hostname, "uhr");
		strcpy(G.ltext, "HELLO WORLD ");

		G.hh = 100;
		G.h6 = 100;
		G.h8 = 100;
		G.h12 = 100;
		G.h16 = 100;
		G.h18 = 100;
		G.h20 = 100;
		G.h22 = 100;
		G.h24 = 100;
		for (uint8_t i = 0; i < 4; i++) { G.Sprachvariation[i] = 0;}

		G.MQTT_State = 0;
		G.MQTT_Port = 1883;
		strcpy(G.MQTT_Server, "192.168.4.1");

#ifdef UHR_114
		G.UhrtypeDef = Uhr_114;
#endif

#ifdef UHR_114_Alternative
		G.UhrtypeDef = Uhr_114_Alternative;
#endif

#ifdef UHR_114_2Clock
		G.UhrtypeDef = Uhr_114_2Clock;
#endif

#ifdef UHR_125
		G.UhrtypeDef = Uhr_125;
#endif

#ifdef UHR_169
		G.UhrtypeDef = Uhr_169;
#endif

#ifdef UHR_242
		G.UhrtypeDef = Uhr_242;
#endif

#ifdef Brg_Color
		G.Colortype = Brg;
#endif

#ifdef Grb_Color
		G.Colortype = Grb;
#endif

#ifdef Rgb_Color
		G.Colortype = Rgb;
#endif

#ifdef Rbg_Color
		G.Colortype = Rbg;
#endif

#ifdef Grbw_Color
		G.Colortype = Grbw;
#endif
		G.bootLedBlink = false;
		G.bootLedSweep = false;
		G.bootShowWifi = true;
		G.bootShowIP = false;

		eeprom_write();
		Serial.println("eeprom schreiben");
	}
	//-------------------------------------
	// Start Serielle Schnittstelle bei Bedarf
	//-------------------------------------
	if (DEBUG == true){
		Serial.begin(115200);
		Serial.println("");
		Serial.println("--------------------------------------");
		Serial.println("Begin Setup");
		Serial.println("--------------------------------------");
	}

	//-------------------------------------
	Serial.println("Starting Telnet server");
	TelnetServer.begin();
	TelnetServer.setNoDelay(true);


	//-------------------------------------
	Serial.println("--------------------------------------");
	Serial.println("ESP Uhr");
	Serial.print("Version         : "), Serial.println(VER);
	Serial.printf("Chip ID         : %08X\n", ESP.getChipId());
	Serial.printf("Flash ID        : %08X\n\n", ESP.getFlashChipId());
	Serial.printf("CPU Speed       : %u MHz \n\n", ESP.getCpuFreqMHz());

	Serial.printf("Flash real Size : %u KByte\n", ESP.getFlashChipRealSize() / 1024);
	Serial.printf("Flash ide  Size : %u KByte\n", ESP.getFlashChipSize() / 1024);
	Serial.printf("Flash ide Speed : %u\n\n", ESP.getFlashChipSpeed());

	Serial.printf("Free Heap Size  : %u Byte\n", ESP.getFreeHeap());
	Serial.printf("Sketch Size     : %u Byte \n", ESP.getSketchSize());
	Serial.printf("Free Sketch Size: %u Byte \n\n", ESP.getFreeSketchSpace());

	Serial.printf("SDK Version     : %s\n", ESP.getSdkVersion());
	Serial.print("RESET Info      : ");
	Serial.println(ESP.getResetInfo());
	Serial.print("COMPILED        : ");
	Serial.print(__DATE__);
	Serial.print(" ");
	Serial.println(__TIME__);

	//-------------------------------------
	// Get Pointer for Uhrtype
	//-------------------------------------

	usedUhrType = getPointer(G.UhrtypeDef);

	//-------------------------------------
	// LEDs initialisieren
	//-------------------------------------
	Serial.println("LED Init");
	InitLedStrip(G.Colortype);
	if (G.bootLedBlink) {
		led_set_all(0x40, 0x40, 0x40, 0x40);
		led_show();
		delay(20);
	}
	if (G.bootLedSweep) {
		led_single(20);
	}
	led_clear();
	led_show();

	G.conf = COMMAND_IDLE;

	//-------------------------------------
	// Start External RealtimeClock
	//-------------------------------------

	if (RTC.begin() == true){
		Serial.println("External RealtimeClock found");
		externalRTC = true;
	}else{
		Serial.println("No external RealtimeClock found");
		externalRTC = false;
	}

	//-------------------------------------
	// Start WiFi
	//-------------------------------------
	if (G.bootShowWifi) {
		show_icon_wlan(0);
	}
	Network_setup(G.hostname);
	int strength = Network_getQuality();
	Serial.printf("Signal strength: %i\n", strength);
	if (G.bootShowWifi) {
		show_icon_wlan(strength);
		delay(500);
	}
	WlanStart();

	//-------------------------------------
	// Zeit setzen
	//-------------------------------------
	utc = now();    //current time from the Time Library
	ltime = tzc.toLocal(utc, &tcr);
	_sekunde = second(ltime);
	_minute = minute(ltime);
	_stunde = hour(ltime);
	if (G.UhrtypeDef == Uhr_169){
		_sekunde48 = _sekunde * 48 / 60;
	}
	show_zeit(1);
	if (G.UhrtypeDef == Uhr_169 && G.zeige_sek < 1 && G.zeige_min < 2){
		set_farbe_rahmen();
	}

	//-------------------------------------
	// mDNS--
	//-------------------------------------
	MDNS.begin((const char *) G.hostname);
	MDNS.addService("http", "tcp", 80);
	MDNS.addService("http", "tcp", 81);

	//-------------------------------------
	// OTA--
	//-------------------------------------
	httpUpdater.setup(&httpServer);
	httpServer.begin();

	//-------------------------------------
	// MQTT
	//-------------------------------------

	if (G.MQTT_State == 1)
	{
		mqttClient.setServer(G.MQTT_Server, G.MQTT_Port);
		mqttClient.setCallback(MQTT_callback);
		mqttClient.connect("Wortuhr");
		mqttClient.subscribe("/Wortuhr");
	}

	//-------------------------------------
	// Start Websocket
	//-------------------------------------
	webSocket.begin();
	webSocket.onEvent(webSocketEvent);

	Serial.println("Websockest started");
	Serial.println("--------------------------------------");
	Serial.println("Ende Setup");
	Serial.println("--------------------------------------");
	Serial.println("");
}

//------------------------------------------------------------------------------
// Start loop()
//------------------------------------------------------------------------------

void loop(){
	unsigned long currentMillis = millis();
	count_millis += currentMillis - previousMillis;
	count_delay += currentMillis - previousMillis;
	if (G.UhrtypeDef == Uhr_169){
		count_millis48 += currentMillis - previousMillis;
	}
	previousMillis = currentMillis;
	if (count_millis >= interval){
		count_millis = 0;
		utc = now();    //current time from the Time Library
		ltime = tzc.toLocal(utc, &tcr);
		_sekunde = second(ltime);
		_minute = minute(ltime);
		_stunde = hour(ltime);
		count_tag++;
		// Wetteruhr
		if (G.UhrtypeDef == Uhr_242){
			weather_tag++;
		}

	}
	if (G.UhrtypeDef == Uhr_169){
		if (count_millis48 >= interval48){
			count_millis48 = 0;
			_sekunde48++;
			if (_sekunde48 > 47) { _sekunde48 = 0; }
		}
	}

	//------------------------------------------------
	Telnet();  // Handle telnet connections

	httpServer.handleClient();

	webSocket.loop();

	//------------------------------------------------
	// MQTT
	//------------------------------------------------
	if (G.MQTT_State == 1 && WiFi.status() == WL_CONNECTED)
	{
        if (!mqttClient.connected()) {MQTT_reconnect();}
        mqttClient.loop();
	}

	//------------------------------------------------
	// Sekunde48
	//------------------------------------------------
	if (G.UhrtypeDef == Uhr_169){
		if (last_sekunde48 != _sekunde48){
			if (G.prog == 0 && G.conf == 0){
				if (G.zeige_sek == 1 || G.zeige_min == 2){
					rahmen_clear();
				}
				if (G.zeige_sek > 0){
					show_sekunde();
				}
				led_show();
			}
			last_sekunde48 = _sekunde48;
		}
	}

	//------------------------------------------------
	// Sekunde und LDR Regelung
	//------------------------------------------------
	if (last_sekunde != _sekunde){

		//--- LDR Regelung
		if (G.ldr == 1){
			doLDRLogic();
		}

		if (G.prog == 0 && G.conf == 0){
			show_zeit(0); // Anzeige Uhrzeit ohne Config
		}
		last_sekunde = _sekunde;

		if (G.UhrtypeDef == Uhr_242){
			if ((_sekunde == 0) | (_sekunde == 10) | (_sekunde == 20) | (_sekunde == 30) | (_sekunde == 40) | (_sekunde == 50)){
				wetterswitch++;
				led_clear();
				if (wetterswitch > 4){
					wetterswitch = 1;
				}
				Serial.print("Wetterswitch: ");
				Serial.println(wetterswitch);
				Serial.print("WStunde: ");
				Serial.println(wstunde);
			}
		}
	}

	//------------------------------------------------
	// Minute
	//------------------------------------------------
	if (last_minute != _minute){
		Serial.println(">>>> Begin Minute <<<<");
		TelnetMsg(">>>> Begin Minute <<<<");

		if (G.prog == 0 && G.conf == 0){
			led_clear();
			show_zeit(1); // Anzeige Uhrzeit mit Config
		}

		_sekunde48 = 0;
		last_minute = _minute;

		Serial.printf("%u.%u.%u %u:%u:%u \n", day(ltime), month(ltime), year(ltime), hour(ltime), minute(ltime), second(ltime));
		Serial.println(">>>> Ende  Minute <<<<");
		TelnetMsg(">>>> Ende  Minute <<<<");
	}

	//------------------------------------------------
	// Tag
	//------------------------------------------------
	if (count_tag >= 86400){
		count_tag = 0;
		ntp_flag = true;
	}

	//------------------------------------------------
	// Wetterdaten abrufen
	//------------------------------------------------
	if (G.UhrtypeDef == Uhr_242 && weather_tag >= 600){    // Eisbaeeer changed for Debug (soll 600)
		weather_tag = 0;
		if (WiFi.status() == WL_CONNECTED)
		{
			getweather();
		}
	}

	Network_loop();

	//------------------------------------------------
	// NTP Zeit neu holen
	//------------------------------------------------
	if (ntp_flag == true){
		Serial.println("npt: Neue Zeit holen");
		TelnetMsg("npt: Neue Zeit holen");
		ntp_flag = false;
		wlan_status = WiFi.status();
		if (wlan_status == WL_CONNECTED){
			timeClient.update();
			unix_time = timeClient.getEpochTime();
			if (unix_time > 0){
				setTime(unix_time);
				Serial.println(unix_time);
				utc = now();    //current time from the Time Library
				ltime = tzc.toLocal(utc, &tcr);
				Serial.print(hour(ltime));
				Serial.print(":");
				Serial.print(minute(ltime));
				Serial.print(":");
				Serial.print(second(ltime));
				Serial.print(" - ");
				Serial.print(day(ltime));
				Serial.print(".");
				Serial.print(month(ltime));
				Serial.print(".");
				Serial.println(year(ltime));
			}
		}
	}

	switch (G.prog)
	{
        //------------------------------------------------
        // Farbe Uhr / Hintergrund / Rahmen einstellen
        //------------------------------------------------
	    case COMMAND_MODE_WORD_CLOCK:
	        {
            show_zeit(0); // Anzeige Uhrzeit ohne Config
            if (G.UhrtypeDef == Uhr_169 && G.zeige_sek < 1 && G.zeige_min < 2){
                set_farbe_rahmen();
            }
            G.prog = COMMAND_IDLE;
            break;
        }
			//------------------------------------------------
			// Sekunden
			//------------------------------------------------
		case COMMAND_MODE_SECONDS:
		{
			if (G.prog_init == 1)
			{
				led_clear();
				G.prog_init = 0;
			}
			char d1[5];
			char d2[5];
			sprintf(d1, "%d", (int) (_sekunde / 10));
			sprintf(d2, "%d", (int) (_sekunde % 10));
			zahlen(d1[0], d2[0]);
			break;
		}

			//------------------------------------------------
			// Laufschrift
			//------------------------------------------------
		case COMMAND_MODE_MARQUEE:
		{
			if (G.prog_init == 1)
			{
				G.prog_init = 0;
				led_clear();
				count_delay = (G.geschw + 1) * 20;
			}
			if (count_delay >= (G.geschw + 1u) * 20u)
			{
				laufschrift(G.ltext);
				count_delay = 0;
			}
			break;
		}

			//------------------------------------------------
			// Regenbogen
			//------------------------------------------------
		case COMMAND_MODE_RAINBOW:
		{
			if (G.prog_init == 1)
			{
				G.prog_init = 0;
				uhr_clear();
				count_delay = G.geschw * 7 + 1;
			}
			if (count_delay >= G.geschw * 7u + 1u)
			{
				rainbowCycle();
				count_delay = 0;
			}
			break;
		}

			//------------------------------------------------
			// Farbwechsel
			//------------------------------------------------
		case COMMAND_MODE_CHANGE:
		{
			if (G.prog_init == 1)
			{
				G.prog_init = 0;
				led_clear();
				count_delay = G.geschw * 7 + 1;
			}
			if (count_delay >= G.geschw * 7u + 1u)
			{
				rainbow();
				count_delay = 0;
			}
			break;
		}

			//------------------------------------------------
			// Farbe Rahmen
			//------------------------------------------------
		case COMMAND_MODE_COLOR:
		{
			if (G.prog_init == 1)
			{
				G.prog_init = 0;
				set_farbe();
				led_show();
			}
			break;
		}

			//------------------------------------------------
		default:
			break;
	}

	switch (G.conf)
	{
			//------------------------------------------------
			// Reset
			//------------------------------------------------
		case COMMAND_RESET:
		{
			delay(500);
			ESP.reset();
			ESP.restart();
			while (true) {}
			break;
		}

			//------------------------------------------------
			// Config Senden
			//------------------------------------------------
		case COMMAND_REQUEST_CONFIG_VALUES:
		{
			strcpy(str, R"({"command":"config")");
			strcat(str, R"(,"ssid":")");
			strcat(str, Network_getSSID().c_str());
			strcat(str, R"(","zeitserver":")");
			strcat(str, G.zeitserver);
			strcat(str, R"(","hostname":")");
			strcat(str, G.hostname);
			strcat(str, R"(","ltext":")");
			strcat(str, G.ltext);
			strcat(str, R"(","h6":")");
			sprintf(s, "%d", G.h6);
			strcat(str, s);
			strcat(str, R"(","h8":")");
			sprintf(s, "%d", G.h8);
			strcat(str, s);
			strcat(str, R"(","h12":")");
			sprintf(s, "%d", G.h12);
			strcat(str, s);
			strcat(str, R"(","h16":")");
			sprintf(s, "%d", G.h16);
			strcat(str, s);
			strcat(str, R"(","h18":")");
			sprintf(s, "%d", G.h18);
			strcat(str, s);
			strcat(str, R"(","h20":")");
			sprintf(s, "%d", G.h20);
			strcat(str, s);
			strcat(str, R"(","h22":")");
			sprintf(s, "%d", G.h22);
			strcat(str, s);
			strcat(str, R"(","h24":")");
			sprintf(s, "%d", G.h24);
			strcat(str, s);
			for (uint8_t i = 0; i < 4; i++)
			{
					strcat(str, R"(","spv)");
					sprintf(s, "%d", i);
					strcat(str, s);
					strcat(str, R"(":")");
					sprintf(s, "%d", G.Sprachvariation[i]);
					strcat(str, s);
			}
			strcat(str, R"(","hell":")");
			sprintf(s, "%d", G.hell);
			strcat(str, s);
			strcat(str, R"(","zeige_sek":")");
			sprintf(s, "%d", G.zeige_sek);
			strcat(str, s);
			strcat(str, R"(","zeige_min":")");
			sprintf(s, "%d", G.zeige_min);
			strcat(str, s);
			strcat(str, R"(","ldr":")");
			sprintf(s, "%d", G.ldr);
			strcat(str, s);
			strcat(str, R"(","ldrCal":")");
			sprintf(s, "%d", G.ldrCal);
			strcat(str, s);
			strcat(str, R"(","cityid":")");
			strcat(str, G.cityid);
			strcat(str, R"(","apikey":")");
			strcat(str, G.apikey);
			strcat(str, R"(","UhrtypeDef":")");
			sprintf(s, "%d", G.UhrtypeDef);
			strcat(str, s);
			strcat(str, R"(","colortype":")");
			sprintf(s, "%d", G.Colortype);
			strcat(str, s);
			strcat(str, R"(","MQTT_State":")");
			sprintf(s, "%d", G.MQTT_State);
			strcat(str, s);
			strcat(str, R"(","MQTT_Port":")");
			sprintf(s, "%d", G.MQTT_Port);
			strcat(str, s);
			strcat(str, R"(","MQTT_Server":")");
			strcat(str, G.MQTT_Server);
			strcat(str, R"(","bootLedBlink":")");
			strcat(str, G.bootLedBlink ? "1" : "0");
			strcat(str, R"(","bootLedSweep":")");
			strcat(str, G.bootLedSweep ? "1" : "0");
			strcat(str, R"(","bootShowWifi":")");
			strcat(str, G.bootShowWifi ? "1" : "0");
			strcat(str, R"(","bootShowIP":")");
			strcat(str, G.bootShowIP ? "1" : "0");
			strcat(str, "\"}");
			Serial.print("Sending Payload:");
			Serial.println(str);
			webSocket.sendTXT(G.client_nr, str, strlen(str));
			G.conf = COMMAND_IDLE;
			break;
		}

			//------------------------------------------------
			// conf Farbwerte senden
			//------------------------------------------------
		case COMMAND_REQUEST_COLOR_VALUES:
		{
			strcpy(str, R"({"command":"set")");
			for (uint8_t i = 0; i < 4; i++)
			{
				for (uint8_t ii = 0; ii < 4; ii++)
				{
					strcat(str, ",\"rgb");
					sprintf(s, "%d", i);
					strcat(str, s);
					sprintf(s, "%d", ii);
					strcat(str, s);
					strcat(str, "\":\"");
					sprintf(s, "%d", G.rgb[i][ii]);
					strcat(str, s);
					strcat(str, "\"");
				}
			}
			strcat(str, R"(,"hell":")");
			sprintf(s, "%d", G.hell);
			strcat(str, s);
			strcat(str, R"(","geschw":")");
			sprintf(s, "%d", G.geschw);
			strcat(str, s);
			strcat(str, R"(","colortype":")");
			sprintf(s, "%d", G.Colortype);
			strcat(str, s);
			strcat(str, "\"}");
			webSocket.sendTXT(G.client_nr, str, strlen(str));
			G.conf = COMMAND_IDLE;
			break;
		}
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

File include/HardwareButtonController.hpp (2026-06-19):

#pragma once

#include "HardwareButtonController.h"

static constexpr uint32_t HARDWARE_BUTTON_DEBOUNCE_MS = 40;
static constexpr uint32_t HARDWARE_BUTTON_LONG_PRESS_MS = 2000;

uint8_t HardwareButtonController::pinFor(ButtonId button) const {
    switch (button) {
    case PowerButton:
        return pins.powerButton;
    case ModeButton:
        return pins.modeButton;
    case SpeedButton:
        return pins.speedButton;
    default:
        return pins.powerButton;
    }
}

//------------------------------------------------------------------------------

HardwareButtonAction
HardwareButtonController::actionFor(ButtonId button,
                                    uint32_t pressDurationMillis) const {
    switch (button) {
    case PowerButton:
        return HardwareButtonAction::TogglePower;
    case ModeButton:
        return pressDurationMillis >= HARDWARE_BUTTON_LONG_PRESS_MS
                   ? HardwareButtonAction::NextTransition
                   : HardwareButtonAction::NextMode;
    case SpeedButton:
        return pressDurationMillis >= HARDWARE_BUTTON_LONG_PRESS_MS
                   ? HardwareButtonAction::NextHue
                   : HardwareButtonAction::IncreaseBrightness;
    default:
        return HardwareButtonAction::None;
    }
}

//------------------------------------------------------------------------------

void HardwareButtonController::begin(const HardwarePins &hardwarePins) {
    pins = hardwarePins;

    for (uint8_t i = 0; i < ButtonCount; i++) {
        const auto button = static_cast<ButtonId>(i);
        buttons[i] = ButtonState{};
        const uint8_t pin = pinFor(button);
        if (pin == HARDWARE_PIN_DISABLED) {
            continue;
        }

        pinMode(pin, INPUT_PULLUP);
        buttons[i].stableLevel = digitalRead(pin);
        buttons[i].lastLevel = buttons[i].stableLevel;
    }
}

//------------------------------------------------------------------------------

HardwareButtonAction HardwareButtonController::loop() {
    const uint32_t now = millis();

    for (uint8_t i = 0; i < ButtonCount; i++) {
        const auto button = static_cast<ButtonId>(i);
        const uint8_t pin = pinFor(button);
        if (pin == HARDWARE_PIN_DISABLED) {
            continue;
        }

        ButtonState &state = buttons[i];
        const bool level = digitalRead(pin);

        if (level != state.lastLevel) {
            state.lastLevel = level;
            state.lastChangeMillis = now;
        }

        if ((now - state.lastChangeMillis) < HARDWARE_BUTTON_DEBOUNCE_MS ||
            level == state.stableLevel) {
            continue;
        }

        state.stableLevel = level;
        if (state.stableLevel == LOW) {
            state.isPressed = true;
            state.pressedMillis = now;
        } else if (state.isPressed) {
            state.isPressed = false;
            return actionFor(button, now - state.pressedMillis);
        }
    }

    return HardwareButtonAction::None;
}

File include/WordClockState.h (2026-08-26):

#pragma once
#include "Arduino.h"
#include "version.gen.h"
#include <NeoPixelBus.h> // HsbColor

#define PAYLOAD_LENGTH 30
#define MAX_ROW_SIZE 22
#define MAX_BIRTHDAY_COUNT 5

// The Unique ID is a cross-reference for HTML/JavaScript

#define CLOCK_TYPES_LIST                                                       \
    /* BN (Bengali) */                                                         \
    X(BN9x8, 0, _bn9x8, "bn-9-8")                                              \
    /* CH (Swiss) */                                                           \
    X(Ch10x11, 1, _ch10x11, "ch-10-11")                                        \
    X(Ch10x11V2, 2, _ch10x11v2, "ch-10-11-v2")                                 \
    X(Ch10x11ZH, 35, _ch10x11zh, "ch-10-11-zh")                                \
    /* EN (English) */                                                         \
    X(Eng08x08, 3, _en08x08, "en-08-08")                                       \
    X(Eng10x11, 4, _en10x11, "en-10-11")                                       \
    X(Eng11x12, 5, _en11x12, "en-11-12")                                       \
    /* ES (Spanish) */                                                         \
    X(Es08x08Cuarto, 6, _es08x08Cuarto, "es-08-08-cuarto")                     \
    X(Es10x11, 7, _es10x11, "es-10-11")                                        \
    /* FR (French) */                                                          \
    X(Fr10x11, 8, _fr10x11, "fr-10-11")                                        \
    /* DE (German) */                                                          \
    X(Ger08x08, 9, _de08x08, "de-08-08")                                       \
    X(Ger08x08Viertel, 10, _de08x08Viertel, "de-08-08-viertel")                \
    X(Ger10x11, 11, _de10x11, "de-10-11")                                      \
    X(Ger10x11Alternative, 12, _de10x11Alternative, "de-10-11-alt")            \
    X(Ger10x11AlternativeFrame, 13, _de10x11AlternativeFrame,                  \
      "de-10-11-alt-frame")                                                    \
    X(Ger10x11bayerisch, 14, _de10x11bayerisch, "de-10-11-bayerisch")          \
    X(Ger10x11Clock, 15, _de10x11Clock, "de-10-11-clock")                      \
    X(Ger10x11Mrrioes, 16, _de10x11Mrrioes, "de-10-11-mrrioes")                \
    X(Ger10x11Nero, 17, _de10x11Nero, "de-10-11-nero")                         \
    X(Ger10x11NeroFrame, 18, _de10x11NeroFrame, "de-10-11-nero-frame")         \
    X(Ger10x11schwaebisch, 19, _de10x11schwaebisch, "de-10-11-schwaebisch")    \
    X(Ger11x11, 20, _de11x11, "de-11-11")                                      \
    X(Ger11x11schwaebisch, 21, _de11x11schwaebisch, "de-11-11-schwaebisch")    \
    X(Ger11x11V2, 22, _de11x11V2, "de-11-11-v2")                               \
    X(Ger11x11V3, 23, _de11x11V3, "de-11-11-v3")                               \
    X(Ger13x13, 24, _de13x13, "de-13-13")                                      \
    X(Ger16x8, 25, _de16x8, "de-16-8")                                         \
    X(Ger16x18, 26, _de16x18, "de-16-18")                                      \
    X(Ger22x11Weather, 27, _de22x11Weather, "de-22-11-weather")                \
    /* HU (Hungarian) */                                                       \
    X(Hu10x10, 28, _hu10x10, "hu-10-10")                                       \
    /* IT (Italian) */                                                         \
    X(It10x11, 29, _it10x11, "it-10-11")                                       \
    /* NL (Dutch) */                                                           \
    X(Nl10x11, 30, _nl10x11, "nl-10-11")                                       \
    /* RO (Romanian) */                                                        \
    X(Ro10x11, 31, _ro10x11, "ro-10-11")                                       \
    /* RU (Russian) */                                                         \
    X(Ru10x11, 32, _ru10x11, "ru-10-11")                                       \
    /* SE (Swedish) */                                                         \
    X(Se10x11, 33, _se10x11, "se-10-11")                                       \
    /* TR (Turkish) */                                                         \
    X(Tr10x11, 34, _tr10x11, "tr-10-11")

enum ClockWords : uint8_t {
    ESIST = 0,
    VOR = 1,
    NACH = 2,
    UHR = 3,

    FUENF = 4,
    ZEHN = 5,
    VIERTEL = 6,
    DREIVIERTEL = 22,
    ZWANZIG = 7,
    HALB = 8,
    EINS = 9,

    H_EIN = 10,
    H_ZWEI = 11,
    H_DREI = 12,
    H_VIER = 13,
    H_FUENF = 14,
    H_SECHS = 15,
    H_SIEBEN = 16,
    H_ACHT = 17,
    H_NEUN = 18,
    H_ZEHN = 19,
    H_ELF = 20,
    H_ZWOELF = 21,
    H_MITTERNACHT = 23
};

struct MqttData {
    bool state;
    char serverAdress[PAYLOAD_LENGTH];
    char user[PAYLOAD_LENGTH];
    char password[PAYLOAD_LENGTH];
    char clientId[PAYLOAD_LENGTH];
    char topic[PAYLOAD_LENGTH];
    uint16_t port;
};

enum class WhiteType : uint8_t {
    WarmWhite = 0,
    NeutralWhite = 1,
    ColdWhite = 2,
};

struct Birthday {
    uint8_t day;
    uint8_t month;
};

constexpr uint8_t HARDWARE_PIN_DISABLED = UINT8_MAX;

struct HardwarePins {
    uint8_t led;
    uint8_t powerButton;
    uint8_t modeButton;
    uint8_t speedButton;
};

struct OpenWeatherMapData {
    char apikey[35];
    char cityid[8];
};

enum class BuildTypeDef : uint8_t {
    Normal = 0,
    DoubleResM1 = 1,
    DoubleRes = 2,
    TrippleRes = 3,
    QuadRes = 4,
};

inline uint8_t getLedsPerLetter(BuildTypeDef buildTypeDef) {
    switch (buildTypeDef) {
    case BuildTypeDef::DoubleRes:
        return 2;
    case BuildTypeDef::TrippleRes:
        return 3;
    case BuildTypeDef::QuadRes:
        return 4;
    default:
        return 1;
    }
}
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

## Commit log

2022-12-28 Removed COMMAND_BRIGHTNESS, instead COMMAND_SET_BRIGHTNESS will be used for all Brightness values. Fixed Handling of Brightness update in Wortuhr.cpp
    [Uhr.h]
2022-12-28 FIxed Range of Brightness slider. Instead of 1 to 10 the Range is now 0-100. Also fixed led_set_pixel_hsb() to properly handle bri and sat values. Added possible RGBW values within the function. Rear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
    [uhr_func.hpp]
2022-12-28 Added New Handling for Speed and Brightness in Wortuhr.cpp. Changed Name of Comand_Modes to Clear Names. Fixed G.Prog_init for Comand_Modes. Refcatored javascript Funktions in script.js
    [Uhr.h]
2023-01-04 Further Refactoring of the code. Moved essential Clock Functions from Wortuhr.cpp to ClockWork Class in that way almost all led funtions could be private. Added a single ClockWork.loop() to the Wortu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
2023-01-08 Refactored led funtions out of clockWork.h/hpp to own class Led in files leh.h and led.hpp. Translated all Comments in clockwork.h/hpp and led.h/hpp to english. no further changes to code. Clang form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
    Changes to be committed:
    modified: include/Animation.hpp
    modified: include/EEPROMAnything.h
    modified: include/WebPage_Adapter.h
    modified: include/clockWork.h
    modified: include/clockWork.hpp
    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
2023-01-08 Renamed Network.h -> network.h ... My system is not case sensitive. The was basicly "Works on my machine" :-)
    renamed: include/Network.h -> include/network.h
    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
2023-01-14 Resolved an Error in OpenWeatherMap DetermineWTemp. Restructured If conditions.
    [openwmap.h]
2023-01-18 Refactor of Uhrtype names to a more univeral aproach. Added new Layoutoption "English" with dialect options.
    modified: include/Uhr.h
    renamed: include/Uhrtypes/uhr_func_114_2Clock.hpp -> include/Uhrtypes/DE10x11.2clock.hpp
    renamed: include/Uhrtypes/uhr_func_114_Alternative.hpp -> include/Uhrtypes/DE10x11.alternative.hpp
    renamed: include/Uhrtypes/uhr_func_169.hpp -> include/Uhrtypes/DE10x11.frame.hpp
    renamed: include/Uhrtypes/uhr_func_114.hpp -> include/Uhrtypes/DE10x11.hpp
    renamed: include/Uhrtypes/uhr_func_125.hpp -> include/Uhrtypes/DE11x11.hpp
    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
2023-01-18 Added Option to Reverse minute LED Direction. I implemented it with placeholders for further layout options.
    modified: include/Uhrtypes/DE10x11.frame.hpp
    modified: include/Uhrtypes/DE10x11.hpp
    modified: include/Uhrtypes/DE11x11.hpp
    modified: include/Uhrtypes/DE21x11.weather.hpp
    modified: include/Uhrtypes/Uhrtype.hpp
    modified: include/webPageAdapter.h
    modified: src/Wortuhr.cpp
    modified: webpage/index.html
    modified: webpage/script.js
    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
    [Animation.hpp, Uhr.h]
2023-01-22 Added feature to manage minute display options on all Clocktypes "Off" and "Normal". Changed order of minuteVariants accordingly.
    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
2023-01-27 Added Language Indicator to Uhrtypes and added Condition in setHour to use it.
    modified: include/Uhrtypes/DE10x11.2clock.hpp
    modified: include/Uhrtypes/DE10x11.alternative.hpp
    modified: include/Uhrtypes/DE11x11.v2.hpp
    modified: include/Uhrtypes/DE17x17.hpp
    modified: include/Uhrtypes/EN10x11.hpp
    modified: include/Uhrtypes/NL10x11.hpp
    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
2023-01-27 Added a enum class for scoped values of Words on Front. Made SetLetter Typesafe.
    modified: include/openwm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
2023-02-02 Revert "Added Purist Mode to show It is only to full Hour"
    This reverts commit e58a18880a8c43f8c67122b66820ed2ad3754758.
    [Uhr.h]
2023-02-02 Added documentation for frame layout. It is the same letter layout as DE11x11. I reanamed it accordingly and set the refs and updateded the config.h
    renamed: include/Uhrtypes/DE10x11.frame.hpp -> include/Uhrtypes/DE11x11.frame.hpp
    modified: include/config.h
    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
2023-02-04 Added missing default statement to switch case
2023-02-05 Fixed a Bug in Animation Matrix
    [Animation.hpp]
2023-02-11 Diverse kleine Anpassungen am Layout und Design
    - Anstatt den Standard-Pure-Button komplett durch eigene Stile zu ersetzen,
    werden nur ausgewählte Stile überschrieben. Dies geschieht, um
    weiterhin die guten defaults von Pure (z. B. Hover- und Focus-Stile) zu behalten.
    - Die Versionsnummer im Footer muss nicht semantisch als Überschrift
    gekennzeichnet werden und wurde optisch weniger aggressiv gestaltet.
    - Der Slider für Farbwechsel auf der Seite *Funktionen* macht das layout
    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
2023-02-12 Variablenname des Selects korrigiert
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2023-02-16 What was planned as a small bugfix for the seconds frame turned out to be a major rebuild of the handling of the seconds frame.
    Now it is possible to implement different frame lengths/sizes and also to select different styles.
    Full function has been tested.
    new file: include/frame.h#
    modified: include/led.hpp
    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
    [Uhr.h]
2023-02-19 Small bugfixes for SecondsFrame
    [Uhr.h]
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2023-02-19 Menü & Überschriften auf kleinen Geräten korrigiert
    - Fixed: Durch PR #199 verdeckte auf kleinen
    Geräten der Menü-Button die Überschrift.
    - Fixed: Die Seite *Farben* hat jetzt auch eine
    Überschrift. Damit ist sie einheitlich zu den
    anderen Seiten und sorgt nicht für Konflikte
    mit dem Menü-Button auf kleinen Geräten.
    - Changed: Die Überschriften der Boxen auf der
    Seite *Anzeigeoptionen* enthalten nicht
    mehr den Suffix `*optionen`. Das war redundant.
    - Removed: Unbenutzten CSS-Code für das alte Menü
    (`.main-menu`) und die bereits entfernten
    Elemente `.content`, `.header h2` entfernt.
    - Camel-Case-Schreibweise von `WortUhr` bzw. der
    englischen oder deutschen Schre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
2023-03-07 Reworked Handling of Minute LEDs
    [Uhr.h]
2023-03-10 Fixed Frame not showing
2023-03-10 Fix #214: Einstellungen zu einer Funktion sind wieder da.
    * Die Einstellungen zu einer Funktion auf der
    Seite *Funktionen* sind wieder da. Ich hatte
    sie versehentlich in 6e30d2ef50bd39e33aadce35f3629a9d0ee27163 gelöscht.
2023-03-10 Reworked Frame handling with bits instead of Array
    [Uhr.h]
2023-03-10 Fixed handling of new time and out of sync frame
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2023-04-12 Major Change from RGB to HSB Colors
    This is done to simplify Brightness settings and enable future SmartHome
    features.
    modified: include/mqtt.hpp
    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
2023-04-16 Fixed an Typo on Website resolving changed buttons
2023-04-16 Fixed an Error with init of MQTT on runtime
    [Uhr.h]
2023-04-20 Added missing Changes previously unstaged
    [Uhr.h]
2023-04-21 Correct spelling of *Digital Clock* in code and translations
    [Uhr.h]
2023-04-24 Fix for Minute LEDs not shoing current minute
2023-04-24 Fixed led.clear() for Frame layouts
2023-04-29 Fix for Colorization of Letters
    [Animation.hpp]
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2023-05-01 Better Accessibility (adjusted colors and HTMl elements)
    - Links are underlined.
    - Proper landmark HTMl elements are used (nav, main, ...).
    - Buttons and the logo link have better contrast ratio (WCAG AAA 4.5:1).
    - Readonly inputs have better contrast ratio (WCAG AAA 4.5:1).
    - Removed `fieldset` Elements when there was no legend
2023-05-01 Better accessibility for the menu
    - The menu items are marked as such (`role="menuitem"`).
    - The currently active page in the menu is marked as such (`aria-current="page"`).
    - The menu state is available to screen readers (`aria-expanded`).
    - SVG icons are hidden from screen readers, because they are purely visual (`aria-hidden="true"`)
    - The hamburger button is marked as a control for the menu (`aria-controls="menu"`).
    - The hamburger button has a localized label (*Show Menu* or *Hide Menu*).
2023-07-01 Reworked ledSingle() and ClearMinArray()
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2023-07-15 Reworked Min for Clocks with Min on FrontMatrix
    [Animation.h, Animation.hpp]
2023-07-15 Fixed Bug, minutes not cleared in frame Uhrtype
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2023-12-31 Verschiedene Sprachen hinzugefügt
    Schweizerdeutsch, Deutsch (Schwäbisch), Französisch und Rumänisch als Uhrenlayout hinzugefügt.
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2024-04-16 Reworked WebInterface for Offset/Slope principle
    [Transition.hpp, Uhr.h]
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2024-04-18 Added a powercycle based reset to wordclock
2024-04-18 Additional Reset for Powercycle Counter
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2024-05-13 reworked State of LED
    [Uhr.h]
2024-05-20 Some Fixes to Transition.hpp
    [Transition.hpp]
2024-05-20 Fixed fogotten refactored names
    [Transition.hpp]
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2024-07-27 Corrections for French and Romanian time display
    In the French edition, the "nach" has been removed for "20 nach" and "25 nach" because it is not needed in either case.
    Correction of the "offsetHour" for "case 35". It showed an hour too early if the "hasThirtyfive" is set.
2024-09-14 Added Options for ESP32
    [partitions_singleapp_large.csv]
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2024-10-16 Fix for MinuteChange also triggering a Transition
    [Transition.hpp]
2024-10-16 Fix for color jumps if ColorTransition is on
    [Transition.hpp]
2024-10-16 Fix for Color fade if Transitions are on with colored words
    [Transition.hpp]
2024-10-18 Fixed building for ESP32
2024-10-19 Add: ESP32-C3 to the supported boards. Fixed NeoPixel method to work with all ESP32 devices.
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2024-11-14 Added 3D files for 8x8 wordclock
    [Wortuhr_8x8-Cover.3mf, Wortuhr_8x8_CaseWithoutLayerChange.3mf, Wortuhr_8x8_Case_DE15min_Prusa.3mf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]
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2025-01-04 Corrected es_ist___plural___ behaviour in DetermineWhichItIsToShow
    Issue: The Spanish layout was not displaying "Es la una" (es_ist___plural___). Corrected by adding hour%12 outside the first if statement.
    Addition: "Es la una..." should be displayed for times >12:34 and < 13:35.
    Corrected by passing the minutes to the DetermineWhichIsToShow function and adding the corresponding if statement.
2025-01-12 Added support for d1mini Added Frame to layout "Nero" (can be used to remodel a clock from the 2013 AVR based project)
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2025-01-13 Delete include/DE10x11.nero.frame.hpp
    Wrong location
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2025-01-17 Adressed Bug with background color picker.
    [Transition.hpp]
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2025-02-22 Reworked Minutes "InWords" and added Ch11x10v2 with "gsi"
    [Transition.hpp]
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2025-03-17 Update additional Env
    [partitions_singleapp_large Woom32 .csv, partitions_singleapp_large c3.csv]
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2025-03-28 Correct Number for ES8x8Cuarto
    [Uhr.h]
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2025-03-29 Add correct color for GER08x08 VOR
    [Transition.hpp]
2025-03-29 Removed files for 8x8 wordclock for future link to printables
    [Wortuhr_8x8-Cover.3mf, Wortuhr_8x8_CaseWithoutLayerChange.3mf, Wortuhr_8x8_Case_DE15min_Prusa.3mf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]
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2025-04-06 Fix crash in Digital clock and Seconds modes
    PR #483 introduced changes which reference the fontWidth and fontHeight
    variables directly as arrays. However, those two variables are declared
    as PROGMEM and may therefore only be referenced as addresses which will
    be read from flash via pgm_read_byte.
    The array access seems to cause crashes in certain configurations (and
    maybe undefined behavior in others?).
    This commit changes all fontWidth and fontHeight array accesses to be in
    line with the previous usage of those variables: The data is read via
    pgm_read_byte.
    Fixes: #557
    Related: https://github.com/ESPWortuhr/Multilayout-ESP-Wordclock/issues/550#issuecomment-2777130560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
    [Transition.hpp]
2025-04-11 Password protected captive portal; enable captive portal and reset with power cycling
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2025-04-23 Correct Extra LED
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2025-05-27 Fix clock display in DE11x11.v3 layout by adding break statement to prevent 'uhr' and 'vor' from appearing together
    Added a break statement to the DE11x11.v3 layout. Without the statement, the clock always displays the words „uhr“ and „vor“ together (for instance, „Es ist zwanzig vor elf Uhr“). However, with the break statement, the word „UHR“ is only displayed when explicitly added (such as „Es ist elf Uhr“).
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2025-06-07 Reworked Frame Logic and Refactored code
2025-06-08 resolved some errors in frame.h
2025-06-08 Resolved an error with Frame and change of LanguageVariant
2025-06-08 Added If clauses for correct handling of Frame and Minutes w/o transitions.
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2026-02-25 Resolved potential memory leak with frame
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2026-03-03 Removed unnessecary files
    [partitions_singleapp_large Woom32 .csv, partitions_singleapp_large c3.csv, partitions_singleapp_large.csv]
2026-03-05 Added missing assignments for BN9x8 layout
    [Uhr.h]
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2026-06-19 Added new Data
    [Word.fzz, Wordclock.f3d]
2026-06-19 Fix for the SNTP not reachable
    [WordClock.cpp]
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2026-06-23 Fix color handling of website
    [ClockWork.hpp]
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2026-06-29 Fix for Build process
    [I2CBus.hpp]
2026-06-29 Fix for mqtt password
    [ClockWork.hpp]
2026-06-29 Fixed OpenWeatherMap Password handling
    [ClockWork.hpp]
2026-06-29 Adde reboot banner to hardware pin change
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2026-07-29 fix only redraw when the displayed second changes
    [ClockWork.hpp]
2026-07-30 Bounds-Guard im Getter und fix für Off-by-one
2026-07-30 Fix for MQTT OFF and ON
    [ClockWork.h, ClockWork.hpp]
2026-07-30 Fix for overflow in json
    [ClockWork.hpp]
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2026-08-12 Fixed transition buffers on clock type change
    [ClockWork.hpp, Transition.h, Transition.hpp]
2026-09-08 Separated colorization and transitions into render stages
    The clock face runs through explicit stages now: ClockWork fills the front
    matrix, ColorStage decides every cell's colour, and only then may a
    Transition blend one coloured face into the next.
    Colorization no longer needs a transition. G.transitionColorize and
    G.colorizePerWord become a single G.colorize with three modes - monochrome,
    polychrome (the top to bottom gradient) and word random - picked from a
    dropdown above the colour tiles. The tiles follow the mode: primary next to
    secondary for polychrome, background and frame only for word random. The
    separate "Wortweise" radio button is gone, its function lives on inside word
    random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
    [ClockWork.hpp, Mqtt.cpp, Transition.h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]
2026-09-08 Move transitions into their own include/Transitions/ folder
    include/Transitions/ now holds everything that animates: Transition.h/.hpp,
    TransitionType.h, TransitionEffect.h, and one file per effect under
    Effects/ (Fade, Scroll, Laser, Balls, MatrixRain, Snake, Firework,
    Countdown), plus their helpers Ball/Rain/Snake/Firework.h. include/Render/
    keeps only colour and pipeline: ColorStage, Colorizers, ColorMatrix,
    RenderPipeline, DisplayPolicy, SpecialEvents. The two former grab-bag
    headers TransitionEffects.h and EventEffects.h are gone.
    Also fixes three bugs surfaced while reviewing the last commit:
    - The colour mode dropdown never reflected the stored setting: the
    firmware sends `coloriz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
    [ClockWork.hpp, Transition.h, Transition.hpp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]
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2026-09-09 Skip refreshColors() while the birthday firework is showing
    [Transition.hpp]
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2026-09-09 Tighten the Laser effect's completion assertion
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2026-09-09 Fix auto brightness never falling back to the LDR
    [ClockWork.hpp]
2026-09-09 Skip RTC.begin() when I2C is disabled
    [WordClock.cpp]
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2026-09-09 Size the LED strip from the active layout instead of a fixed 300 LEDs
    [ClockWork.hpp]
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2026-09-10 Apply a new hostname at runtime instead of rebooting
    [ClockWork.hpp]
2026-09-10 Replaced sprintf in seconds mode with direct digit chars
    [ClockWork.hpp]
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2026-09-10 Fixed OpenWeatherMapIntegration Part 1
    [Config.h, OpenWeatherMap.h, WordClock.cpp]
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2026-09-10 Fix a short text payload wipes the setting
    [WebPageAdapter.cpp]
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2026-09-11 Correct the auto-brightness min == max comment
    [ClockWork.hpp]
2026-09-11 Fix for ES08x08 Layout
    [ClockWork.hpp]
2026-09-11 Fixed 10bit ADC readout regadless of ESP
    [WordClock.cpp]
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2026-09-19 Fix left-right mirrored symbol display (e.g. NOTE)
    ClockType::setFrontMatrixPixel() writes column col directly as bit col,
    while ClockType::getFrontMatrixPixel() reads column col as bit
    (colsWordMatrix()-1-col) - the opposite convention. Led::setDigitalClock()
    and Led::setScrollingText() already compensate for this by calling
    mirrorFrontMatrixVertical() after drawing characters via setFrontMatrixPixel
    (see the existing "Needed for correct displaying of Chars" comment), but
    Led::setBitmapSymbol() draws its bitmaps via the exact same mechanism
    without that compensation.
    This mirrors every symbol bitmap left-to-right on display. It goes
    unnoticed for the left-right symmetric symbols (HEART, SM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
2026-09-30 Default the language variants to what the layout offers
    The "twenty" and "dreiviertel" variants were off by default for every
    layout except Eng10x11, so a layout that has the word for twenty still
    showed "ten to half" until the option was switched on by hand.
    ItIs20 and ItIs40 now default to hasTwenty() and ItIs45 to
    hasDreiviertel(), both on a factory reset and when the clock type is
    changed. The user can still switch them off. Clocks that are updated
    keep their stored settings.
    The clock type change wrote the EEPROM before the defaults were applied,
    so they would not have survived a reboot; the write now follows them.
    DE10x11.schwaebisch has no word for twenty but inherited hasTwenty()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
    [ClockWork.h, ClockWork.hpp, WordClock.cpp]
2026-09-30 Document the 5.0.0 changes in the manual and list all languages
    The manual only covered the colour mode so far. It now also describes
    the fire mode with its cooling and sparking controls, the seconds frame
    with a configurable LED count, the hostname setting, the layout-driven
    defaults of the language variants, how polychrome applies outside the
    word clock, and how MQTT brightness and colour commands behave. The
    "Bunt" transition no longer exists and is dropped from the list; Turkish,
    Bengali and Züridütsch are added to the language and variant lists.
    Both READMEs replace the bullet list of languages with a table that names
    every language with its flag, its native name and its English name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
2026-10-15 Fix inverted transition direction with MirrorHorizontal/MirrorVertical layout
    Word rendering compensates for MirrorHorizontal/MirrorVertical by reversing
    row/column order in the front matrix before mapping to physical LED index
    (see Led::applyMirroringAndReverseIfDefined). Transition::copy2Stripe() and
    the STRIPE branch of Transition::analyzeColors() wrote/read pixels using the
    logical row/col directly, bypassing that correction.
    As a result, with a mirrored layout (e.g. "10 x 11 Nero" with horizontal
    mirroring and meander-wired rows), any transition with a vertical direction
    component ran inverted: scroll up/down, laser, matrix rain and firework all
    moved top<->bottom swapped, while horizo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
2026-10-22 Polish the web interface layout and labels
    The page subtitle now spans the full header width below the title
    instead of being squeezed next to the language and status pills.
    The color target selector puts three choices in one row on wider
    screens instead of leaving the background option alone on a second
    row; four choices keep the two by two grid, phones keep the old layout.
    The build type select uses the full row next to its short label so the
    long options are no longer cut off.
    The "It is" display label uses consistent quotation marks in all
    languages, and a Latin "A" in the Russian text is now Cyrillic.
2026-10-22 Publish Home Assistant discovery per entity again
    5.0.0-rc.1 announced all entities in a single device-based discovery
    bundle (homeassistant/device/<MAC>/config, Home Assistant 2024.11+) and
    cleared the per-entity configs of older firmware. Integrations that
    emulate Home Assistant discovery, such as openHAB, do not understand the
    bundle and could no longer find the clock (#824).
    Every entity now gets its own retained config under
    homeassistant/<platform>/<MAC>_<id>/config again, using the same paths
    as before the bundle. Each config carries the shared availability,
    device and origin blocks, so all entities still group under one device.
    The unique_ids are unchanged, so existing Home Assistan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
2026-10-22 Pack the web interface cards and stop early label wrapping
    Cards in a multi-column section no longer share row heights, so a short
    card no longer leaves an empty gap below it until the tallest card of
    its row ends. A small script sizes each card's grid span from its
    height and keeps the left to right order.
    Rows with a toggle switch only reserve the width of the switch, so their
    labels no longer wrap at half the card width. Automatic hyphenation is
    off, long words still break when they do not fit.
    The build type select gets its own row below the label so the long
    options are not cut off, and the manual time field centers its text in
    Safari.
2026-10-22 Give the I2C scan its own block in the hardware pins card
    The scan result now follows the pin fields as a regular labeled row with
    its scan button right below it, separated by a divider. The save button
    stays the card's last action and the only primary button, the scan
    button uses a new secondary glass style.
    The result row also no longer sits flush against the scan button, the
    aligned form group margin had overridden its top margin.
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2026-10-23 Dim the laser beam and the fireworks with the clock brightness
    The laser beam was a fixed full white and the fireworks used fixed full
    colours, so both lit up at full brightness at night, with the brightness
    set to off by the hour schedule or the light sensor, and even with the
    clock switched off via MQTT or the hardware button (#487). The birthday
    fireworks run every five minutes all day, so they flashed through the
    night as well.
    Both effects now take their level from the brightest channel of the
    current foreground and background colour, which already carry the hour
    schedule, the auto brightness and the on/off state. At full brightness
    the beam and the shells look the same as before. The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
2026-10-23 Document the setup portal clock page and running without WiFi
    Explains the new Clock page in the captive portal (time from the
    phone, color, front settings, continue without WiFi), how to open the
    portal on an already configured clock by power cycling three times,
    the factory reset on the sixth start, the boot wait times with and
    without an RTC, and how to use the DS1307 based HW-111 RTC module.
    Also corrects the default portal SSID in the first start steps.
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2026-10-26 Fehlende Übersetzungen ergänzen und falsch benannte Schlüssel korrigieren
    Spanisch, Ungarisch, Italienisch, Niederländisch und Russisch fehlten
    zwischen 14 und 33 Schlüssel, vor allem die Geburtstags-Box und die
    neueren Layout-Optionen (Extra-LED pro Reihe, Drehen, Mäander). Dort fiel
    die Seite auf Englisch zurück.
    Dazu drei Schlüssel, die nur durch einen Tippfehler nicht gegriffen haben:
    Niederländisch hatte die Weißton-Texte unter "wit type" statt "whitetype",
    Russisch den Übergangs-Block unter "animation" statt "transition" und
    Spanisch "fireworks" statt "firework". Die Blöcke sind umbenannt, der
    russische Übergangs-Block um die fehlenden Typen ergänzt.
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2026-10-27 Readme kürzen und Funktionen von 5.0.0 ergänzen
    Beide Readmes schrumpfen von 536 auf 215 Zeilen. Installation für
    Windows, macOS und Linux, Hardwareaufbau, Konfiguration und MQTT sind
    zusammengefasst, die Konfiguration steht als Tabelle.
    Neu aufgeführt: Weboberfläche mit hellem und dunklem Modus, Farbmodi
    Polychrom und Zufällig pro Wort, Farbtemperatur, Modus Feuer,
    Übergänge, BH1750, Einrichtungsportal ohne Heimnetz und die einzelnen
    Home-Assistant-Entitäten.
    Korrigiert: Effekt Fire in der MQTT-Liste, Beispieldateien auf
    V5.0.0, die nicht mehr vorhandenen AUTOBRIGHT_USE-Schalter entfernt,
    leeren Abschnitt System & Boot-Verhalten gestrichen.
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
